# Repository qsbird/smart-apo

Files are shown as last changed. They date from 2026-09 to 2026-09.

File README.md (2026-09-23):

# Smart Apo · 智能阿波与智能水中

**想让浮漂自己记笔记，顺便查清是谁在拽鱼线。** 方案是水面阿波和钩侧水中件各记录一份数据，回收后对时分析。鱼还没参与测试，预算已经先替项目按了暂停键。

> [!NOTE]
> **项目状态：暂停。** 完整方案的预计试制成本超出当前预算。仓库保留研究过程与可审查的工程文件；暂停不等于技术验证通过。

> [!IMPORTANT]
> **制造状态：`NOT_FAB_RELEASED`。** Rev.A2 的 KiCad ERC 为 0 错误、0 警告，DRC 为 0 错误、0 未连接，仍有 **3 项连接区 courtyard 警告**。没有放行的生产 Gerber、钻孔和最终 BOM/CPL，也没有首件装配或水域实测。DRC 很能检查铜线，但不会替你拧紧 O 形圈。

## 先看钓组

鱼竿主线依次经过水面阿波、水中张力记录件、鱼钩和鱼饵，鱼游在饵旁的概念图

*概念示意，不按比例。鱼在饵旁边，没有被画成“已咬钩”的成功案例；线长、结节、配重和安全绳位置仍需实物确认。*

| 设备 | 设计中的任务 | 主要硬件 |
|---|---|---|
| **阿波** · 水面 | 记录加速度、角速度和水压，原始数据写入本地 Flash；预留 LED 提示接口 | STM32G031、LSM6DSO、LPS28DFW、W25Q256、LiPo 供电/充电及 LED 驱动 |
| **智能水中** · 靠近钩侧 | 通过受力梁与应变全桥记录钓线张力，供回收后离线标注；也记录运动和压力 | 共用 MCU、IMU、压力传感器和 Flash，另装 316L 弹性梁、应变片全桥与 NAU7802 |

“共板”是**同一 PCB 设计、两块独立设备、两套贴装清单**。它们计划各自记录，回收后导出；水里不靠实时无线链路传数据。上表描述的是设计功能，尚无装配样机证明这些功能在水里运行。

## 波浪很会演，鱼却不一定配合

浮漂动了，原因可能是浪、流、提竿动作，也可能是钩侧发生了机械事件。这个项目希望用水中张力作研究阶段的辅助标签，寻找阿波的 IMU 与压力信号里可重复的特征，而不是只赌一个瞬时阈值。

```mermaid
flowchart LR
    A["阿波原始记录<br/>运动 · 压力"] -->|回收导出| H["主机工具<br/>校验 · 对时 · 评价"]
    U["水中原始记录<br/>张力 · 运动 · 压力"] -->|回收导出| H
    H --> P["候选检测参数"]
    P --> V["下一独立航次再验证"]
```

这条链路是研究方案，不是已经跑通的产品流程。尤其要说清楚：**张力变化说明钩侧受了力，不自动证明有鱼咬钩。** 摄像、提竿或捕获结果仍需作为语义真值。[现场验证计划](validation/FIELD_TEST_PLAN_CN.md)记录了拟进行的台架、水槽和真实海况测试。

## 尺寸和材料：设计目标，不是合格证

| 项目 | Rev.A 目标或候选 |
|---|---|
| 阿波外形 | 最大直径 32 mm、高 49 mm |
| 共用 PCB | 12 × 35 × 1.0 mm，四层，计划沉金 |
| 首批设想 | 共板 10 片，阿波和水中各装 5 套；**尚未下生产订单** |
| 电池 | 带保护 401020 LiPo，候选 60–80 mAh；所购型号与允许充电电流未锁定 |
| 深度 | 目标工作 10 m、15 m 等效静水压力验证；未实测 |
| 水中张力 | 目标工作 0–2 kgf；另需独立样件验证 ≥5 kgf 生存 |
| 受力件 | 0.30 mm 316L 弹性梁；打印件不能代替它承受钓线拉力 |

<details>
<summary>看看 Rev.A1 的机械概念预览</summary>

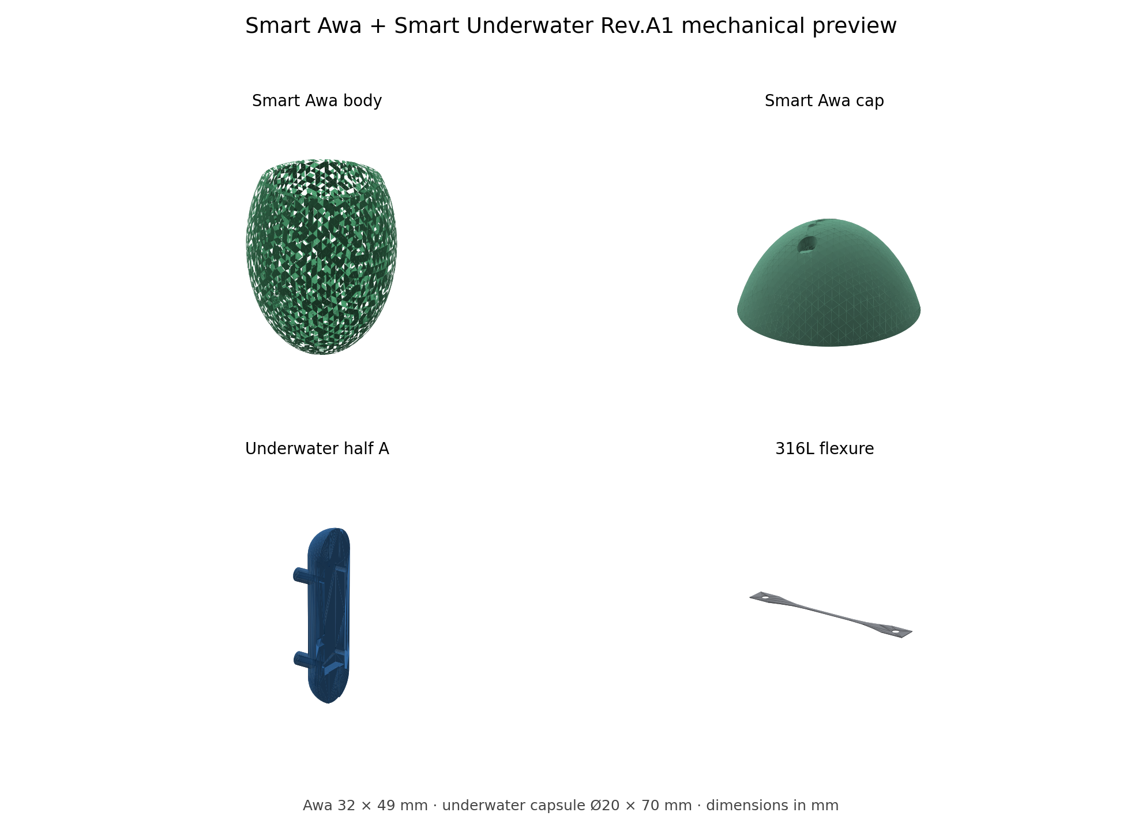
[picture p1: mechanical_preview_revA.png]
Rev.A1 阿波壳体、水中半壳与弹性梁的工程预览


这张图展示壳体与梁的工程几何。梁 STL 只供看形状，真实受力件须按 [316L 加工规范](mechanical/316L_FLEXURE_SPEC_CN.md)和 DXF 制作；图像也不表示 Rev.A2 的装配干涉或防水测试通过。

</details>

位号、数量与 DNP 差异请看 [Rev.A2 工作 BOM](hardware/revA2/BOM_revA2_WORKING.csv)和[装配变体表](hardware/revA2/ASSEMBLY_VARIANTS_revA2.csv)。采购后缀与来料尚未全部确认，工作 BOM 不能直接当最终贴片清单。

## 进度条不如证据可靠

| 领域 | 已留下什么 | 还差什么 |
|---|---|---|
| **电路与 PCB** | Rev.A2 原理图、项目符号/封装库、四层已布线候选板；KiCad 10.0.6 官方 ERC 0/0、DRC 0 错误/0 未连接 | J1/J2/J3 的 3 项连接区 courtyard、所购器件与板厂工艺、完整 3D 装配审查和制造文件复核 |
| **主机数据工具** | UART 解码、CSV 输入校验、事件评分、离线寻参和合成数据生成 | 新航次头缺专门的 C→UART→Python 端到端验证；合成数据不能替代真实航次 |
| **MCU 固件** | 采样、Flash 日志、总线与时基源码；宿主模型测试 | 没有最终可烧录 ELF、板上运行、实测功耗或真正 Stop/RTC 闭环 |
| **机械** | Rev.A1 参数模型、STL、316L 梁 DXF 与装配说明 | 缺匹配 Rev.A2 的完整壳体/器件模型、实物干涉和密封验证 |
| **现场研究** | 静载、水槽、压力和真实海况试验计划 | 尚无可用于证明性能或可靠性的样机与实测数据 |

三处警告只是最显眼的剩余提示；更大的缺口在采购、装配和实物。详细情况见 [Rev.A2 交付门槛](hardware/revA2/DELIVERY_GATES_CURRENT_CN.md)与[暂停检查点](PAUSE_CHECKPOINT_20260924_CN.md)。历史检查点中的数字属于当时版本，别把不同日期的报告拼成一块“全绿”的板。

> [!CAUTION]
> `hardware/revA2/smart_apo_common_revA2.kicad_pcb` 是设计候选版；`hardware/` 根目录里早期的 `*_NETS_PLACED.kicad_pcb` 只是布局参考。**仓库里没有可直接付款投产的制造包。**

## 如果你想复现数字检查

在仓库根目录运行。Python 测试使用宿主机 C 编译器验证模型和协议，不能替代板上测试。

```bash
python3 -m unittest discover -s firmware/host/tests -v
python3 -m unittest discover -s firmware/mcu/tests -v
python3 -m unittest discover -s tools/tests -v
python3 tools/validate_revA2.py
```

2026-09-24 公开提交前，三组测试分别有 **34、8、17 项通过**，结构检查也通过；最新 UART 航次头尚缺完整端到端用例。若有 KiCad 10，可用仅检查模式刷新 ERC/DRC 报告：

```bash
KICAD_CLI=/path/to/kicad-cli bash tools/export_fab_revA2.sh --check-only
```

`--check-only` 会更新工程中的检查报告，不生成制造文件。返回 0 只说明脚本规定的电气门禁通过，**不替三处警告、采购、3D 和实物验证签字**。无参数调用会进入制造导出流程，当前项目不应将其结果视作放行。

安装了 NumPy、SciPy 后，还可以用合成数据熟悉离线工具：

```bash
python3 firmware/host/generate_synthetic_dataset.py
python3 firmware/host/autotune.py \
  firmware/host/example_data/awa.csv \
  firmware/host/example_data/underwater.csv \
  -o /tmp/smart-apo-synthetic-result.json
```

这个例子主要验证管线能否处理规定格式，不负责替鱼提供表演。真实数据的字段、缺测规则、时钟回绕与梁标定要求见 [主机说明](firmware/host/README_CN.md)和[数据协议](firmware/DATA_AND_AUTOTUNE_PROTOCOL_CN.md)。

## 仓库地图

```text
hardware/revA2/       当前原理图、PCB、项目库、工作 BOM、正式检查结果
hardware/*revA1*      Rev.A1 历史文件；旧板不能投产
firmware/mcu/         STM32 固件、宿主模型与构建说明
firmware/host/        解码、输入校验、评分和离线寻参
mechanical/           Rev.A1 壳体/托架、316L 梁图纸与装配说明
tools/                生成器、结构检查、BOM 检查、制造导出门禁
validation/           现场试验方案与 Rev.A1 验证记录
CONTEXT_HANDOFF.md    历史决策与交接资料
```

公开仓库保存源码、工程文件和正式检查结果。本机逐轮候选板、回退快照、编译日志及不完整 3D 审查包没有推送到 GitHub；旧文档提及这些目录时，请以仓库实际文件为准。

## 如果哪天预算松口

先补齐 UART 航次头的端到端测试和最终固件链接；再确认电芯、CT05、LED、晶振、MLCC、Pogo 与板厂工艺，关闭连接区警告；随后核对 Rev.A2 壳体/压力口/电池的实物干涉。完成制造文件独立审阅后，才轮到首件、梁标定、压力、盐水和水域试验。[PCB 放行清单](hardware/revA2/PCB_RELEASE_CHECKLIST_revA2_CN.md)给出了更细的关口。

**当前结论仍是：项目因成本超预算而暂停，Rev.A2 未制造放行。** 鱼可以晚点上钩，工程结论不能抢跑。

## 复用与交流

欢迎通过 Issue 指出具体器件、KiCad 位置或可重复的测试问题。仓库中由项目作者原创的代码、设计文件、文档与插图按 [WTFPL Version 2](LICENSE) 发布（SPDX：`WTFPL`）。引用或改作自第三方的器件资料、库内容等仍受其原有权利约束；本仓库的许可证不能替第三方授权。许可证也不等于产品安全或制造放行证明。

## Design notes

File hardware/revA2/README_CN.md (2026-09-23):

> 最新同版本审查包：`validation/revA2_review_bundle/`已刷新当前原理图、正反面装配PDF及D1旋转后的不完整STEP，manifest.json绑定源/输出哈希。电气结果ERC0/0、DRC0错误/0未连/3项courtyard；采购/工艺/3D/最终链接/实机与尚未完成固件功能见 `hardware/revA2/DELIVERY_GATES_CURRENT_CN.md`。NOT_FAB_RELEASED。

> 最新原理图字段检查点（2026-09-23）：58个阻容显示字段拉开、J2扩大并同步7标签、8个符号库默认字段修正。官方ERC0/0、DRC0错误/0未连/3项courtyard，网表完全一致、PCB未改。见 `hardware/revA2/SCHEMATIC_FIELDS_CHECKPOINT_20260923_CN.md`，NOT_FAB_RELEASED。

> 最新IC图面检查点（2026-09-23）：U1至U7符号及75引脚间距扩大，69个标签/NC同步，长引脚名清晰分列；网表components/nets完全一致，PCB未改。官方ERC0/0、DRC0错误/0未连/3项courtyard。见 `hardware/revA2/SCHEMATIC_IC_CHECKPOINT_20260923_CN.md`；阻容/连接器图面仍待改善，NOT_FAB_RELEASED。

> 最新网络标签检查点（2026-09-23）：148个网络标签改为朝外对齐，锚点/网络语义不变，PCB未改。官方ERC0/0、DRC0错误/0未连/3项courtyard；IC内部引脚名及阻容字段仍待修整。见 `hardware/revA2/SCHEMATIC_LABEL_CHECKPOINT_20260923_CN.md`，NOT_FAB_RELEASED。

> 最新原理图检查点（2026-09-23）：A3纵向解决越页，Population仅隐藏显示；独立坐标/网表审查发现并清除6个连接引脚上的遗留NC叉号，保留3个有效标记。全部网络语义不变，官方ERC0/0、DRC0错误/0未连/3项courtyard，PCB未改；内部标签拥挤仍待修整。见 `hardware/revA2/SCHEMATIC_PAGE_CHECKPOINT_20260923_CN.md`，NOT_FAB_RELEASED。

> 最新D1极性修复（2026-09-23）：正式采用明确A/K符号及K1封装，1=K/LED_K、2=A/LED_A；封装/模型/端标转180°且原物理铜连接保持。官方ERC0/0、DRC0错误/0未连/3项courtyard，17项工具测试通过。设计内部冲突已关闭，所购器件/整页原理图/旧3D更新仍开放。见 `hardware/revA2/D1_POLARITY_FIX_20260923_CN.md`，NOT_FAB_RELEASED。

> 新确认的D1极性阻断（2026-09-23）：D1以PASSIVE2符号定义1=LED_A/2=LED_K，与派生KiCad LED封装1=K/2=A约定相反；ERC/DRC未捕获。必须先修正明确A/K符号、焊盘编号/网络及方向标识，不能仅等待采购资料。见 `hardware/revA2/D1_POLARITY_BLOCKER_20260923_CN.md`。PCB尚未修改，NOT_FAB_RELEASED。

> 最新BOM一致性检查（2026-09-23）：修正C7=100n、C11/C12实际0402和完整封装ID；43位号/变体数量检查通过，15项工具测试通过。U5目录编号冲突及准确MPN/有效容量仍开放，不是生产BOM放行。PCB未改，ERC0/0、DRC0错误/0未连/3警告。见 `hardware/revA2/BOM_CONSISTENCY_CHECKPOINT_20260923_CN.md`。

> 最新1脚标记检查点（2026-09-23）：U1/U5方向三角形仅平移并保持形状/指向，项目库同步；5→3警告，全部丝印DRC清零。官方ERC0/0、DRC0错误/0未连/0一致性问题，剩J1/J2/J3 missing_courtyard开放；NOT_FAB_RELEASED。见 `hardware/revA2/PIN1_SILK_CHECKPOINT_20260923_CN.md`。以下较大计数为历史。

> 最新连接区丝印检查点（2026-09-23）：J2/J3轮廓与库同步修复，9→5警告，无新增项。官方ERC0/0、DRC0错误/0未连/0一致性问题，NOT_FAB_RELEASED。见 `hardware/revA2/CONNECTOR_SILK_CHECKPOINT_20260923_CN.md`。剩2项方向标记压铜和3项courtyard，以下较大计数为历史。

> 最新上部位号检查点（2026-09-23）：U1/U7位号回到各自本体，六个拥挤丝印位号不印刷并保留原位Fab装配标识；36→9警告，无新增项。官方ERC0/0、DRC0错误/0未连/0一致性问题，NOT_FAB_RELEASED。见 `hardware/revA2/UPPER_LABEL_CHECKPOINT_20260923_CN.md`。以下较大警告数为历史。

> 最新被动元件位号检查点（2026-09-23）：R8/C5/C3/C8/R10可见位号调整，50→36警告，无新增项。官方ERC0/0、DRC0错误/0未连/0一致性问题，NOT_FAB_RELEASED。见 `hardware/revA2/PASSIVE_LABEL_CHECKPOINT_20260923_CN.md`。以下较大警告数为历史。

> 最新装配位号检查点（2026-09-23）：补齐6个项目封装Fab标识，43个封装各有一个原位Fab位号并导出正反面审查PDF；仅新增非制造层文字。官方ERC0/0、DRC0错误/0未连/50警告，项目库一致，NOT_FAB_RELEASED。见 `hardware/revA2/ASSEMBLY_LABEL_CHECKPOINT_20260923_CN.md`。完整装配/极性/工艺验证仍开放。

> 最新MCU标识处置（2026-09-23）：五个拥挤丝印位号不印刷，保留原位F.Fab并输出核对装配图，R4移到邻近空白区；70→50警告，无新增项。官方ERC0/0、DRC0错误/0未连/0一致性问题，NOT_FAB_RELEASED。见 `hardware/revA2/MCU_LABEL_CHECKPOINT_20260923_CN.md`。完整装配图仍为交付门槛，下方较大警告数为历史。

> 最新充电区丝印检查点（2026-09-23）：U6/R3/C11位号调整，75→70警告，无新增项。官方ERC0/0、DRC0错误/0未连/0一致性问题，NOT_FAB_RELEASED。见 `hardware/revA2/CHARGER_LABEL_CHECKPOINT_20260923_CN.md`。下方较大警告数为历史。

> 最新J1丝印检查点（2026-09-23）：J1丝印与项目库同步，79→75警告，板边丝印类别清零，无新增项。官方ERC0/0、DRC0错误/0未连/0一致性问题，NOT_FAB_RELEASED。见 `hardware/revA2/J1_SILK_CHECKPOINT_20260923_CN.md`。以下较大警告数为历史。

> 最新D1丝印检查点（2026-09-23）：D1位号及两段板边轮廓调整，项目专用封装同步原理图，82→79警告，无新增项。官方ERC0/0、DRC0错误/0未连/0一致性问题；NOT_FAB_RELEASED。见 `hardware/revA2/BOTTOM_SILK_CHECKPOINT_20260923_CN.md`。D1所购器件极性仍须核验，下方较大警告数为历史。

> 最新字高检查点（2026-09-23）：U2/SW1/J2位号字高修复，89→82警告，text_height类别清零，无新增项。官方ERC0/0、DRC0错误/0未连/0一致性问题，NOT_FAB_RELEASED。见 `hardware/revA2/TEXT_HEIGHT_CHECKPOINT_20260923_CN.md`。下方较大警告数为历史。

> 最新板边位号检查点（2026-09-23）：U4/C6/C16/R6仅Reference字段调整，95→89警告，无新增项；官方ERC0/0、DRC0错误/0未连/0一致性问题，NOT_FAB_RELEASED。见 `hardware/revA2/EDGE_LABEL_CHECKPOINT_20260923_CN.md`。下方警告数为历史。

> 最新U3/C13检查点（2026-09-23）：C13可见位号修复消除10项警告；U3及配套库按最大本体重建禁布，最小理想via余量.10mm/顶部.125mm。官方ERC0/0、DRC普通错误0/未连接0/95警告、一致性0，无忽略/排除，NOT_FAB_RELEASED。见 `hardware/revA2/U3_MARGIN_AND_C13_CHECKPOINT_20260923_CN.md`。以下较小余量和警告数均为历史。

> 最新整板电气闭合（2026-09-23）：MOSI最终候选已独立复检并采用。官方ERC0/0、DRC普通错误0/未连接0/105警告、一致性0，无忽略/排除；NOT_FAB_RELEASED。仅检查模式exit0且fab_export不存在。见 `hardware/revA2/MOSI_CONNECTED_CHECKPOINT_20260923_CN.md`。还须警告、制造公差/采购资料、当前3D及固件/实物门槛；下方未连接数字均为历史。

> 最新位号检查点（2026-09-23）：仅修正U3/J3可见丝印Reference字段，铜/器件位置/规则未变；官方ERC0/0、普通DRC错误0/1MOSI未连接/107警告、一致性0，无忽略/排除，NOT_FAB_RELEASED。见 `hardware/revA2/REFERENCE_TEXT_CHECKPOINT_20260923_CN.md`。MOSI候选仍独立迭代。

> 验证命令更新：日常官方检查使用 `bash tools/export_fab_revA2.sh --check-only`。即使电气计数清零，也不会创建或修改制造文件；不带参数才会在电气门禁通过后进入导出。警告、制造与机械门槛仍需逐项审核。见 CHECK_ONLY_CHECKPOINT_20260923_CN.md。

> 最新IMU完整连接（2026-09-23）：经两组几何合并与独立复核已采用；官方ERC0/0、普通DRC错误0/仅MOSI 1未连接/110警告、一致性0，无忽略/排除，NOT_FAB_RELEASED。最大U2本体理想via余量.10mm；局部供电参考缺口有明确处置、严格标记仍false。见 `hardware/revA2/IMU_CONNECTED_CHECKPOINT_20260923_CN.md`。以下候选未采用/计数为历史。

> 最新DRC可见性检查点（2026-09-23）：五类原忽略检查已启用，无ignored_checks/单项排除；修正一处地线端点，并将工程状态长说明保留到Dwgs.User。官方ERC0/0、普通DRC错误0/2未连接/111警告、一致性0，NOT_FAB_RELEASED。3个连接区courtyard缺失现在明确可见，仍开放。见 `hardware/revA2/DRC_VISIBILITY_CHECKPOINT_20260923_CN.md`。以下为历史。

> 最新LED制造修复（2026-09-23）：LED阴极孔已移出焊盘，审查中元件焊接焊盘内中心为0，剩2处Pogo接触孔待资料；官方ERC0/0、DRC普通错误0/2未连接/122警告、一致性0，NOT_FAB_RELEASED。见 `hardware/revA2/LED_VIA_MANUFACTURING_CHECKPOINT_20260923_CN.md`。以下计数为历史。

> 最新SCL制造修复（2026-09-23）：ADC与MCU两端SCL孔已移出焊盘，焊盘内中心5→3（剩D1.2及J2.7/J2.5）。官方ERC0/0、DRC普通错误0/2未连接/122警告、一致性0；NOT_FAB_RELEASED。IMU候选失败未采用。见 `hardware/revA2/SCL_VIA_MANUFACTURING_CHECKPOINT_20260923_CN.md`。以下数字为历史。

> 最新R5制造修复（2026-09-23）：原审批路径已恢复可用，R5焊盘内孔修复stage3已采用；焊盘内中心6→5。主板官方ERC0/0、DRC普通错误0/2未连接/122警告、一致性0，NOT_FAB_RELEASED。见 `hardware/revA2/R5_MANUFACTURING_CHECKPOINT_20260923_CN.md`。下方审批失败和未采用记录为历史。

> 当前制造审查补充（2026-09-23）：正式板未变，仍2未连接/122警告、NOT_FAB_RELEASED。新增全板via/焊盘审查发现4处元件焊盘内孔与2处Pogo接触孔。R5候选尚未采用，最后修改/复检因自动审批额度不足未执行；MOSI试验拒绝。见 `hardware/revA2/VIA_PAD_CHECKPOINT_20260923_CN.md`。

> 当前ADC SDA检查点（2026-09-23）：I²C两条总线已全部接通；官方ERC0/0、DRC普通错误0/未连接2/警告122、一致性0；NOT_FAB_RELEASED。见 `hardware/revA2/ADC_SDA_CHECKPOINT_20260923_CN.md`。剩IMU_INT/MOSI；官方STEP为不完整模型审查件，未通过3D干涉。以下为历史。

> 当前I²C主干检查点（2026-09-23）：SCL全部接通，上部SDA接入MCU；官方ERC0/0、DRC普通错误0/未连接3/警告122、一致性0；NOT_FAB_RELEASED。见 `hardware/revA2/I2C_JOIN_CHECKPOINT_20260923_CN.md`。余下ADC SDA/IMU_INT/MOSI；局部反焊盘及装配余量仍有明确审查边界。以下为历史。

> 当前ADC SCL检查点（2026-09-23）：MCU/上拉至ADC的SCL已连通，相关REED支路完整。官方ERC0/0、DRC普通错误0/未连接5/警告120、一致性0；NOT_FAB_RELEASED。见 `hardware/revA2/ADC_SCL_CHECKPOINT_20260923_CN.md`。显式填铜增量参考及独立连通审查通过，非EM/实物通过；以下数字为历史。

> 当前上部I²C检查点（2026-09-23）：U2/U3 SDA/SCL已连接，C2同面供电路径缩短。官方ERC0/0、DRC普通错误0/未连接6/警告120、一致性0；NOT_FAB_RELEASED。见 `hardware/revA2/UPPER_I2C_CHECKPOINT_20260923_CN.md`。7个供电过孔边缘参考点单独处置，非EM通过；以下计数为历史。

> 当前 U3 检查点（2026-09-23）：找回哈希匹配的原厂Gerber，按实际中央接地和外围逃线路径建立窄通道，电源/地缺口关闭。官方ERC0/0、DRC普通错误0/未连接8/警告119、一致性0；NOT_FAB_RELEASED。见 `hardware/revA2/U3_ESCAPE_CHECKPOINT_20260923_CN.md`。以下数字为历史。

> 当前 MISO 检查点（2026-09-23）：SCK与MISO已分组采用，官方ERC0/0、DRC普通错误0/未连接12/警告119、一致性0；NOT_FAB_RELEASED。见 `hardware/revA2/MISO_CHECKPOINT_20260923_CN.md`。In1新填铜几何通过，换层回流/SI仍开放；以下旧计数为历史。

> 当前 SCK 检查点（2026-09-23）：已采用独立验证的 B/In2/F 布线，In1 保持地。官方 ERC0/0、DRC 普通错误0/未连接13/警告120、一致性0；NOT_FAB_RELEASED。详见 `hardware/revA2/SCK_CHECKPOINT_20260923_CN.md`。以下旧检查点数字均为历史。

> 最新Flash封装检查点（2026-09-23）：误用Microchip焊盘已按Winbond原著land/paste替换，编号网络保持，错误3D移除。官方ERC0/0、DRC普通错误0/未连接14/警告119；NOT_FAB_RELEASED。见 `hardware/revA2/FLASH_LAND_CHECKPOINT_20260923_CN.md`；局部供电过孔参考缺口有独立处置，不等于EM验证。

> 最新Flash检查点（2026-09-23）：固定32轮BUSY误超时已改为5ms实时时限，host23/23、MCU8/8、20 ARM对象通过。KiCad仅检查独立副本，未采用新布线；仍14未连接/119警告，NOT_FAB_RELEASED。见 `hardware/revA2/FLASH_TIMEOUT_CHECKPOINT_20260923_CN.md`。

> 最新软件等待/LED检查点（2026-09-23）：恢复时基误失效及UART锁存重试已修复，LED寄存器驱动通过模型；MCU8/8、host23/23、20 ARM对象。真实Stop/RTC、最终ELF/实物仍未完成；PCB未改，NOT_FAB_RELEASED。见 `hardware/revA2/IDLE_LED_CHECKPOINT_20260923_CN.md`。

> 最新启动检查点（2026-09-23）：ADC100ms非阻塞保护与LSE有界启动已模型验证，MCU8/8、host23/23、20 ARM对象通过；无最终ELF/板上验证。PCB未改，仍14未连接/119警告。见 `hardware/revA2/STARTUP_TIMING_CHECKPOINT_20260923_CN.md`，软件SLEEP恢复缺陷待修复。

> 最新分压/GPIO检查点（2026-09-23）：R4/R5已改180k/60.4k，阻抗数值超限修正但精度/功耗未实测。ERC0/0；DRC普通错误0、未连接14、警告119；NOT_FAB_RELEASED。见 `hardware/revA2/DIVIDER_GPIO_CHECKPOINT_20260923_CN.md`。旧记录为历史。

> 验证更正（2026-09-23）：旧参考地脚本可能读缓存；MISO PCB组已撤回，SCK候选拒绝。当前官方ERC0/0、DRC普通错误0/未连接14/警告119，NOT_FAB_RELEASED。以 `hardware/revA2/REFERENCE_AUDIT_CORRECTION_20260923_CN.md` 为准，后续必须用显式填铜审查器。

> 最新MISO/I²C检查点（2026-09-23）：ERC0/0，DRC普通错误0、未连接13、警告115；NOT_FAB_RELEASED。详见 `hardware/revA2/SPI_I2C_CHECKPOINT_20260923_CN.md`。In1局部信号的最终回流审查仍开放；旧计数为历史记录。

> 最新逃线/ADC检查点（2026-09-23）：ERC 0/0，DRC普通错误0、未连接14、警告119；NOT_FAB_RELEASED。ADC分压源阻抗另有设计阻塞。详见 `hardware/revA2/FANOUT_ADC_CHECKPOINT_20260923_CN.md`；旧计数为历史记录。

> 最新复位/UART检查点（2026-09-23）：ERC 0/0，DRC普通错误0、未连接15、警告119；NOT_FAB_RELEASED。详见 `hardware/revA2/RESET_UART_CHECKPOINT_20260923_CN.md`。下文旧计数为历史记录。

> 最新电源/SPI 检查点（2026-09-23）：官方 ERC 0/0，DRC 普通错误 0、未连接 18、警告 119；仍 NOT_FAB_RELEASED。详见 `hardware/revA2/POWER_CHECKPOINT_20260923_CN.md`（下文旧计数为历史记录）。

# 智能阿波共板 Rev.A2 工作区

> **活动目标最新桥路检查点**：ERC **0/0**；普通DRC错误 **0**，仍有 **22未连接、119警告**，一致性0，**NOT_FAB_RELEASED**。主差分输入已成对、同面、零过孔；J3物理顺序已旋转。TIM2寄存器后端模型测试通过，23项host＋2项MCU测试通过，最终ELF/板上未完成。详见 [桥路与时基检查点](ANALOG_CHECKPOINT_20260923_CN.md)。下方旧数字为历史。

此目录是从 Rev.A1 独立建立的生产候选工作区。任何 Rev.A2 生成或审查操作都不得写入上级目录中的 `*revA1*` 文件。

## 当前状态

- Rev.A1 基线 SHA-256 已记录在 `revA1_baseline_sha256.json`。
- `smart_apo_revA2.kicad_sym` 使用逐脚电气类型，不再把核心 IC 的所有引脚定义为 Passive。
- `smart_apo_common_revA2.kicad_sch` 是独立原理图；当前先完成符号电气类型修复，电路改动需在官方 ERC 与逐脚审查后进行。
- `SmartApoRevA2.pretty` 是项目级封装库目录。
- `BOM_revA2_WORKING.csv` 与 `ASSEMBLY_VARIANTS_revA2.csv` 保留双装配版本；前者仍是工作 BOM，不是最终下单 BOM。
- `CPL_revA1_REFERENCE_ONLY.csv` 只用于查看旧布局，严禁作为 Rev.A2 贴片坐标文件。
- 上级 `hardware/smart_apo_common_revA2_NETS_PLACED.kicad_pcb` 只是参考板；本目录 `smart_apo_common_revA2.kicad_pcb` 才是从网表重建的四层候选板。
- 已使用 KiCad 10.0.6 官方 ERC：0 错误、0 警告（SW1 改紧凑封装后重跑仍通过）。
- 已使用 KiCad 10.0.6 官方 DRC：**未通过**（2026-09-09 长程 CP05：104 错误、74 未连接）。过孔 0.60/0.30 已消除钻孔过小和孔环不足。完整布线仍未关闭。
- LSM6DSO 已使用项目封装 `SmartApoRevA2:LGA-14_2.5x3mm_P0.5mm_LSM6DSO`（2.5×3.0 mm，DS Figure 25）。无评估板 Gerber 交叉验证前，封装复核不能整项关闭。
- MCU 固件骨架在 `firmware/mcu/`；无 CubeMX / `arm-none-eabi-gcc`，不能当已验证固件。
- 生产导出脚本：`tools/export_fab_revA2.sh`（DRC 非零即拒绝）。长程检查点：`LONG_RUN_CHECKPOINTS_CN.md`。
- LPS28DFW footprint 已按 ST 官方 STEVAL-MKI225A 铜层/阻焊/钢网 Gerber 重建。
- STM32G031F8P6 已按 DS12992 Rev 4 的真实 TSSOP20 物理脚顺序重建。
- W25Q256 `/CS` 已增加 R12 10 kΩ 上电上拉；`/WP`、`/HOLD` 接 3V3。
- KiCad 官方网表已导出：43 个器件、33 个已连接网络、9 个明确未连接引脚。
- 电池焊盘、7 针 Pogo、6 线桥和紧凑磁簧已在项目级 `.pretty`。

## 放行原则

只有在从原理图更新 PCB、完成布线、官方 DRC 为零错误、独立查看 Gerber/钻孔并重新导出 BOM/CPL 后，才可把状态改为 `FAB_RELEASED`。

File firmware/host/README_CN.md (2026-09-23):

> 最新CSV入口校验：直接调参输入拒绝非有限值、重复/倒序时间戳及缺失/重复列；34项host回归通过，旧/新真实加载函数对照通过。完整SciPy管线仍未运行。见VERIFICATION_CSV_INPUT_CN.md。

> 最新评分修复：事件评价改为一对一重叠匹配，防止长报警/重复报警获得虚高F1；28项host回归通过，4096组序列对照及实际搜索函数合成集成通过。完整SciPy管线未运行；example_result.json为旧评分历史，不可当新版质量证据。见VERIFICATION_EVENT_METRICS_CN.md。

# 离线闭环调参工具

输入是阿波与智能水中的两个 CSV。下水前和回收后分别做三次同步敲击，脚本用六个冲击拟合时间偏移与晶振漂移；水中张力生成教师标签，阿波 IMU/压力生成学生特征，并按连续时间切为 60%/20%/20% 三段。

```bash
python generate_synthetic_dataset.py
python autotune.py example_data/awa.csv example_data/underwater.csv -o example_result.json
```

输出参数只作为候选版本。必须在下一次、完全未参与寻参的独立航次通过门限后，才允许写入设备；本工具有意不实现自动刷机，避免同一数据集上的过拟合参数被直接投入使用。

CSV 必填列：`timestamp_us, ax, ay, az, gx, gy, gz, pressure`；水中端另加 `tension_gf`。时间戳必须单调递增，单位为微秒。

回收后若从设备 UART 拉原始帧（`A5 5A` 同步），用：

```bash
python dump_decode.py capture.bin -o voyage_raw.csv
python dump_decode.py capture.bin --autotune awa -o awa.csv
python dump_decode.py capture.bin --autotune uw --tension-lsb-per-gf "$CAL_COUNTS_PER_GF" --tension-zero-counts "$CAL_ZERO_COUNTS" -o underwater.csv
```

`--autotune` 输出 `autotune.py` 所需列，但会先执行下述安全检查。加速度/角速度用 `sensors.h` 候选量程（±4 g、±500 dps）及 ST 官方敏感度 0.122 mg/LSB、17.50 mdps/LSB。压力按 DS13317：阿波 4096 LSB/hPa（Mode 1），水中 2048 LSB/hPa（Mode 2，15 m 不能用 1260 hPa 档）。raw 导出一直保留张力原始计数；UW 调参导出必须填写实际梁标定得到的 CAL_COUNTS_PER_GF 和 CAL_ZERO_COUNTS，不提供默认 gf。帧格式见 `firmware/mcu/include/uart_dump.h`。这不是自动刷机。

宿主机协议/固件模拟接口回归（无 numpy/scipy 依赖，在仓库根目录运行）：

```bash
python3 -m unittest discover -s firmware/host/tests -v
```

2026-09-23：增加显式时间展开验证，见 `firmware/host/VERIFICATION_TIME_UNWRAP_CN.md`；ARM/板上验证未完成。MCU 已实现全航次 Flash/RAM 尾转储的模拟验证，host 去除连续完全相同的重试帧；raw 原样保留计数及 flags；`--autotune` 已拒绝含缺测通道的日志，不会把未采样零值送入调参。显式重采样仍未实现。前序证据与阻塞见 `firmware/mcu/VERIFICATION_20260923_CN.md`。

## 调参导出安全门槛

- AWA 每条样本必须同时置位 IMU_OK(bit 1) 和 PRESS_OK(bit 2)，且不能携带 STRAIN_OK(bit 3)；UW 每条必须三个有效位齐全。没有有效位的数值（即使为 0）只能作为 raw 诊断数据，不能解释为物理零值。
- 任一条缺测即拒绝整次调参导出，退出 2，不创建/覆盖目标 CSV；不擅自删行、补零、插值或前值填充。当前异步 MCU 日志通常会被此门槛拒绝，直到明确实现重采样流程。
- 检查样本内部 CRC，时间戳必须严格递增，sequence 必须按模 65536 连续（允许 65535→0）；外层 CRC 丢弃中间坏帧后产生的序号缺口也拒绝调参；回绕/复位需显式重建，不能直接调参。UART 外层 CRC 仍负责帧筛选，完全相同的连续重试帧去重。
- UW 张力采用 `(raw - zero_counts) / counts_per_gf`；斜率须有限且非零（可为负以表达桥方向），零点必须显式提供且有限。ADC 内部 offset 校准不等于梁的 gf 标定。
- UART v1 尚未传送航次头。`--autotune awa|uw` 是操作者声明的装配变体，不能自动证明压力量程正确；AWA/UW 压力比例分别是 4096/2048 LSB/hPa。
- raw 导出不改变原样本，包括诊断用无效值与 flags。它使用 `*_raw` 列名，不能直接当作 autotune 输入。

## 长航次 uint32 微秒时间展开（显式选择）

默认仍拒绝时间戳回绕。uint32 微秒计数约 71.6 分钟回绕一次；只有操作者能从采集记录确认以下条件时，才可展开：单次不中断启动、没有重启/时钟复位、相邻记录实际间隔始终不超过已知上限，且该上限严格小于半周期（2147483648 us，约 35.8 分钟）。例如已确认最大相邻间隔不超过 10000 us：

```bash
python3 firmware/host/dump_decode.py capture.bin --autotune awa --unwrap-timestamps --max-sample-gap-us 10000 -o awa.csv
```

两个参数必须一起用于 `--autotune`，上限必须为 1..2147483647 的整数。此选项是对采集条件的显式声明，软件不能替操作者证明。每步按模 2^32 计算增量，重复、明显后退、增量超上限、半周期及以上歧义全部拒绝；输出从第一条原始计数开始累加为展开时间，不推断第一条之前的回绕次数。原始记录和内部 CRC 不改写，seq 模 65536 连续、CRC、变体及缺测门槛全部保留；验证失败不覆盖输出。

UART v1 缺少启动/航次标识和宽时间戳，任意长停顿（特别是整周期停顿）、恰好伪装成小正增量的复位，以及恰丢失 65536 的整数倍记录，无法仅凭这两个有限位宽计数可靠识别。来源不明确的日志应保留 raw，不应使用展开参数强行放行。连续完全相同的 UART 重试帧仍按既有规则去重；这不证明采集未重启。时间展开不是异步传感器重采样，当前存在缺测标志的 MCU 日志仍拒绝调参导出。

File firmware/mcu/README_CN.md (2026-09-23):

> 最新日志读取修复：CRC失败时不再覆盖调用者的有效样本，空指针不推进游标的既有防护纳入回归。host契约23项通过（日志用双变体），20个ARM对象编译验证通过；函数静态栈帧40→72字节，仍无最终ELF/上板。见VERIFICATION_LOG_READ_SAFETY_CN.md。

> 最新最终链接实测（2026-09-23）：AWA/UW两次`make all`均因现有Clang找不到lld而exit2，20个新目标文件确认为ARM ELF32 REL；没有最终ELF、未上板。缺ARM链接器及builtins库，未安装新依赖。详见 hardware/revA2/CURRENT_DELIVERY_AUDIT_20260923_CN.md及validation/revA2_current_delivery_audit/。

> 最新资源证据（2026-09-23）：两个版本20个真实ARM对象带-fstack-usage编译通过；静态RAM节714/705字节，已知调用链栈帧小计616字节。未知运行库/异常栈未覆盖，最终ELF和完整栈安全仍未通过。见VERIFICATION_STACK_RESOURCES_CN.md。

# STM32G031 Rev.A2 固件开发状态

截至2026-09-23：主代理实际重跑MCU模型/runtime **8/8**、host回归 **23/23**，AWA/UW两变体共 **20个Cortex-M0+ ELF32目标文件**编译及标头检查通过。**最终ELF未链接、未烧录、没有板上运行或发行包**；缺链接器与ARM compiler runtime，新增工具链安装授权待答复。未安装CubeMX，没有声称CubeMX生成或验证过完整工程。

## 实现层级

| 功能 | 当前证据 | 尚未完成 |
|---|---|---|
| TIM2微秒时基 | 真实寄存器+状态模型 | HSI精度、实物计时、跨Stop补偿 |
| LSE启动 | 真实寄存器、有界2s策略超时+模型 | 准确晶体/drive/负载匹配、板上起振、连续监控 |
| SPI1 / UART TX / I²C1 | 真实寄存器+故障模型 | 真实器件、波形、吞吐与边界工况 |
| GPIO / 磁簧 | IDR实读、释放边沿锁存、1.5s模型 | 电平/抖动、NVIC/ISR、Stop唤醒 |
| ADC电池 | 原始码后端、分压换算、100ms启动保护 | 参考电压、实际RC/漏电/精度、运行中电压阶跃 |
| 传感器/Flash/转储 | 模型与协议回归 | 实际寄存器应答、NOR写入/掉电、整航次 |
| LED | PB0写入/读回、闪光/取消/故障模型 | 实际波形/亮度、轮询节拍、咬钩检测 |
| SLEEP/Stop | 软件等待保持时基、恢复及故障转储模型 | 真正硬件Stop、RTC补偿与功耗验证 |

每项证据与局限见 `VERIFICATION_TIM2_CN.md`、`VERIFICATION_LSE_CN.md`、`VERIFICATION_SPI_CN.md`、`VERIFICATION_UART_CN.md`、`VERIFICATION_I2C_CN.md`、`VERIFICATION_GPIO_CN.md`、`VERIFICATION_ADC_CN.md`。早期报告的“骨架”和测试数量是历史状态。

## 启动、变体和引脚

`app_boot`依次开启SYSCFG、设置PA11_RMP/PA12_RMP、启动TIM2并尝试LSE，然后初始化GPIO、SPI/I²C、磁簧轮询边沿、UART及日志/传感器。PA13/14保留SWD。LSE仅提供启动ready快照；无论LSE成功与否，当前时间戳仍由HSI16/TIM2提供。`SAMPLE_FLAG_LSE_FAIL`不是时间戳校准状态。

同一PCB的AWA变体为LSM6DSO+LPS28DFW+Flash+LED；UW另贴NAU7802与桥路，用`SMART_APO_VARIANT_AWA/UW`选择。物理引脚表见仓库 `hardware/revA2/STM32G031_TSSOP20_PIN_REVIEW_CN.md`，数据协议见 `firmware/DATA_AND_AUTOTUNE_PROTOCOL_CN.md`。

R4/R5现为180kΩ/60.4kΩ、1%，名义毫伏换算 `adc*132220/41223`。启动前100ms拒绝ADC读取且不改输出；C14的100nF X7R、容差≤20%及温度/时钟裕量是设计条件，未由实物证明。详见硬件 `DIVIDER_GPIO_CHECKPOINT_20260923_CN.md` 与启动检查点。

## 状态、存储和接口

软件路径为BOOT→RECORD→DUMP→SLEEP，失败进入ERROR；发现已有APO2日志则只读DUMP。**SLEEP目前不是硬件Stop**，不能宣称低功耗或磁簧中断唤醒已运行。`board_buses_reinit_after_stop`故意使失去补偿的TIM2时基失效；软件SLEEP现不再调用它；等待和转储期间持续服务真实时基，恢复保持同一epoch。时钟失效则仅允许只读转储，不恢复写日志。

RECORD按整数相位调度104/208/320Hz等名义速率；迟到只读当前值，不伪造历史样本。IMU连读14字节、压力5字节，失败不置有效位。同步敲击检测尚未实现；PA0即时电平轮询不能保证捕获短脉冲。

磁簧为PA9低有效。1.5s持续闭合资格使用TIM2及EXTI9上升沿pending清除释放历史，IMR/EMR屏蔽，没有NVIC/ISR。GPIO或时基错误清除资格。

SPI为Mode0、约1MHz、8位访问和软件CS；I²C使用保守标准模式时序计算、7bit地址、重复起始读和有界故障处理，干净NACK不屏蔽其他设备，硬故障需要显式恢复。具体时序假设和测试不等于板上合格。

Flash写前检查整页空白/WEL，写后读回；已有日志只读回收，未知/损坏头拒写，不自动擦除历史。BUSY已改为TIM2实时时限5ms，并有连续4096次停滞终止；首次ready允许无TIM2只读恢复，真正PP前必须验证时基进展。原厂页写最大3ms的依据及边界测试见 `VERIFICATION_FLASH_TIME_CN.md`。读失败/半帧不当有效数据。UART格式仍 `A5 5A | version=1 | len | sample | crc16`；TX等待TXE和末尾TC，失败后APP显式重新初始化TX后端并在下一步重试原记录，但没有主机ACK，不能证明主机持久化。

`app_error_flags()`提供日志/转储粘滞错误；失败保留样本/记录。主机解码为 `firmware/host/dump_decode.py`，默认拒绝时戳回绕，显式展开需满足记录间隔约束。TIM2的模2^32单调契约要求调用间隔不超过INT32_MAX微秒；Stop、停转或配置异常失败闭合。

## 实际验证

在仓库根目录：

```sh
python3 -m unittest discover -s firmware/mcu/tests -v
python3 -m unittest discover -s firmware/host/tests -v
make -C firmware/mcu objects-both CC=/opt/homebrew/opt/llvm/bin/clang BUILD=validation/flash_time_checkpoint/arm
python3 tools/check_divider_revA2.py
```

当前集成日志及20个对象哈希在 `validation/revA2_interactive/`；软件等待/转储/LED的新回归与局限见 `VERIFICATION_IDLE_LED_CN.md`；各后端还有独立状态模型/静态分析证据。不得直接运行宿主编译的生产main：默认MMIO地址属于MCU；宿主测试必须使用明确隔离的hooks。

下一步：完成真实Stop/RTC时间设计、咬钩检测与最终链接/栈预算，再以样机验证传感器、NOR/转储、ADC、时钟、功耗和故障恢复。PCB仍NOT_FAB_RELEASED。

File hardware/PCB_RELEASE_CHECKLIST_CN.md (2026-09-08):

# PCB 投板放行清单

当前文件包含网络、真实焊盘、器件布局和内层平面定义，但尚未布线。Gerber 放行门槛如下，全部签字后才可建立 `FAB_RELEASED` 版本。

## 原理图

- [ ] 从 ST、Nuvoton、Winbond、Microchip、TI 的当前原厂数据手册逐脚复核。
- [ ] STM32G031F8P6 的 TSSOP20 复用脚与固件外设映射经过 CubeMX 验证。
- [ ] LSM6DSO 在 I²C 模式下 CS 拉高；SDO/SA0 地址脚固定，不悬空。
- [ ] LPS28DFW 的焊盘严格按 ST TN0018 复核；金属帽接地、O 形圈受力和顶层禁布区按原厂建议完成。
- [ ] NAU7802 的 AVDD=3.0 V、DVDD=3.3 V、六线桥 REF、输入共模与 320 SPS 配置复核。
- [ ] W25Q256 的 `/WP`、`/HOLD` 上拉与上电时序复核。
- [ ] 充电电流按实际电芯允许值设置；20 kΩ 仅代表约 50 mA 的候选值。
- [ ] 使用带保护电芯，或补充独立过充、过放、短路保护。

## 布局布线

- [ ] 四层建议：F.Cu 信号/器件，In1 整面 GND，In2 3V3/VBAT，B.Cu 低速信号。
- [ ] IMU 距板边、螺钉、弹性梁和磁性件足够远；器件坐标轴已在丝印标出。
- [ ] 压力传感器开孔上方无遮挡，所有铜/阻焊/外壳压紧区域满足数据手册。
- [ ] NAU7802 与桥路接口形成独立安静区，差分输入等长、短、成对，远离 LED 和充电回路。
- [ ] 每个电源脚就近去耦；Flash 和 MCU SPI 回路短且有连续参考地。
- [ ] 湿式触点设置隔离/串阻，盐水中不得带电暴露。
- [ ] 完成 4 层板厂能力规则 DRC，无未布网络，无未连接地岛。
- [ ] 板文件中当前 `segments/tracks=0` 的阻断状态已解除，全部飞线清零。

## 制造与首件

- [ ] 板厚 1.0 mm、ENIG、4 层叠层与 12 × 35 mm 外形得到板厂确认。
- [ ] 实际 SMT 厂料号锁定；BOM 中所有替代料逐项审批。
- [ ] Gerber/钻孔在独立查看器中复核，CPL 原点和旋转方向用装配图确认。
- [ ] 先做裸板短路检查，再限流 10 mA 上电。
- [ ] 分别验证 3V3、I²C 三传感器、Flash、充电、SWD、LED、应变桥。

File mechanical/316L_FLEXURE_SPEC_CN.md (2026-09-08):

# 316L 弹性梁加工与标定规范（Rev.A）

## 加工定义

- 材料：316L 不锈钢薄板，固溶态；厚度 0.30 ± 0.015 mm。
- 轮廓：`316L_flexure_0p30mm_revA.dxf`，单位 mm。
- 总长 78 mm，端部宽 8 mm，安装孔 Ø3.2 mm，孔距 67 mm。
- 中央敏感段宽 1.50 mm、有效长度 22 mm。
- 工艺：优先精密激光切割后电解抛光；也可慢走丝。去除毛刺但不得磨窄敏感段。
- 平面度：≤0.15 mm；孔边与过渡圆角不得有可见裂纹。

## 应变片

- 四片 350 Ω、适用于不锈钢的箔式应变片，组成温度补偿全桥。
- 两片沿载荷方向、两片横向或布置在等应变位置；贴片方向误差建议 <0.5°。
- 胶层越薄越均匀越好。固化后先做绝缘电阻，再涂柔性防水保护。

## 工程限制

这是一根用于获取真实数据和确定最终量程的 Rev.A 梁，不是已认证的安全件。解析估算只用于下单前筛选：中央截面积约 0.45 mm²，1 kgf 名义轴向应力约 21.8 MPa、应变约 113 µε。孔边、过渡区、切割热影响和贴片胶层会改变实际输出，必须用砝码标定。

建议依次执行 0、50、100、200、500、1000、1500、2000 g 五次加载/卸载循环，记录零点、线性、回差和温漂；然后对独立样件逐级加载，验证至少 5 kgf 生存目标。钓线另加一根松弛约 1–2 mm 的 Dyneema 安全绳，防止梁意外断裂后丢钩。未经破坏试验前不得把 5 kgf 当作额定安全载荷。

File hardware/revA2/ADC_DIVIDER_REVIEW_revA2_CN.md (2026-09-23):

> **后续已采用180k/60.4k、1%（常见E96值）**：最坏Rth45.677kΩ；4.2V下17.471µA，分压30天12.579mAh。原理图/PCB/BOM/网表/固件已同步，见 `validation/revA2_divider/consistency.json`。静态电流预算、参考/建立时间和精度实测仍开放；下文保留原方案比较，180k/59.4k并非本次采用值。

# 电池分压阻抗与功耗复核（2026-09-23）

**设计开放，尚未修改R4/R5或宣称电压精度通过。** 主代理实际读取 [ST DS12992 Rev4](https://www.st.com/resource/en/datasheet/stm32g031f8.pdf) 第78页表59及第80页表60：RAIN最大50kΩ；表60还给出采样条件。不能仅用当前4MHz/160.5周期或C14就推定248kΩ已获规格保证。

以下是实际运行 `python3 validation/revA2_spi/adc_divider_options.py` 的计算结果。假设电池恒4.2V、分压电阻1%、C14名义100nF；不含漏电、参考误差、电容容差/偏压降容或其他负载，不是续航预测。

| R4/R5 | Rth最大（1%） | 4.2V静态电流 | 仅分压30天电量 | 名义RC全阶跃至半个12bit LSB |
|---|---:|---:|---:|---:|
| 现有1M/330k | 250.60kΩ | 3.158µA | 2.274mAh | 223.58ms |
| 候选180k/59.4k | 45.11kΩ | 17.544µA | 12.632mAh | 40.24ms |
| 候选100k/33k | 25.06kΩ | 31.579µA | 22.737mAh | 22.36ms |

两个候选保留相同名义分压比；原始ADC到名义毫伏的数学比值可保持，但电阻定义/静态断言、原理图、BOM、PCB值与验证记录必须同步修改。不能只改固件系数。180k/59.4k在列出的固定比值候选中静态电流较低，但采购精度/温漂和系统待机预算仍需纳入取舍。

还有开关分压/缓冲方案，会增加器件、面积、漏电和上电时序要求；本轮没有未经评估新增器件。现有代码未测VREFINT，仍用名义3.3V换算，需验证LDO压差下VDDA、输入漏电/反灌、连接电池后的RC建立和温度误差。软件读取完成只证明ADC原始码转换完成。

数字计算证据 `validation/revA2_spi/adc_divider_options.json`。下一步在准确电芯和待机目标基础上选定电阻/开关方案，完成跨文件一致性、ERC/DRC及采样建立验证；实物精度门槛保持开放。

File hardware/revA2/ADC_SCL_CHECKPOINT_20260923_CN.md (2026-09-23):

# ADC SCL 连接检查点 · 2026-09-23

已采用stage3，主板SHA256 `1b107b735467401e9e3c740cd033305a7a1a90b10bf3aedef7c3753b80e3ccb6`；NOT_FAB_RELEASED。

## 正式改动

PCB完成MCU/U1 pad20、R2 pad1与ADC/U4 pad13的SCL连接，经过F/In2/B/F，新增0.60/0.30mm过孔(9.55,10.25)、(9.1,19.4)、(5.365,21.0)，线宽0.15mm。没有In1信号。

相关REED B铜改为明确的折线路径，保留R10上拉、SW1信号脚和MCU输入连接；In2下段向右绕行避让SCL。正式版本没有移动器件、过孔或修改焊盘网络/封装/制造规则。独立文本审核除segment/via/zone外均保持，四层、1mm、12×35mm、43封装不变。

初版误将SW1连接支路当作可移除铜，并碰到已有过孔，产生短路/开路；官方检查检出后拒绝，没有进入主板。补读全部焊盘后恢复SW1完整路径并逐点修复。前后回退副本baseline/final以及每次候选和变化清单在validation/revA2_adc_bus。

## 实际工具证据

| 检查点 | 普通DRC错误 | 未连接 | 警告 |
|---|---:|---:|---:|
| baseline | 0 | 6 | 120 |
| stage1，拒绝 | 13 | 7 | 121 |
| stage2，拒绝 | 1 | 5 | 120 |
| stage3与主板复检 | 0 | 5 | 120 |

stage1分类：shorting_items5、clearance6、solder_mask_bridge2；stage2为REED支路碰3V3via的shorting_items1，stage3局部绕开后清零。采用前后警告type/UUID集合无变化。

实际执行命令：

```sh
bash tools/export_fab_revA2.sh
python3 tools/validate_revA2.py
python3 tools/check_divider_revA2.py --output validation/revA2_adc_bus/divider_consistency.json
python3 validation/revA2_adc_bus/summarize.py
```

官方KiCad10.0.6 ERC0/0，DRC普通错误0、5未连接、120警告、一致性0。制造脚本退出2，未导出生产文件。validate确认Rev.A1哈希不变；分压跨文件一致性通过。详细日志main_gate.log、validation.log及分类/位置清单comparison.json、repair_queue.csv。

另以KiCad自带Python运行check_invariants.py和tools/check_reference_revA2.py（主板对本组baseline，输出main_reference.json），均退出0；显式填铜后In1地单轮廓，六敏感网及原有外层铜无新增参考缺口。本项只比较本轮增量，不取消既有局部供电过孔的历史审查说明。

独立复核通过实际连通图确认REED的SW1.1/R10.2/U1.16及原有两via连通；SCL的U1.20/R2.1/U4.13及三个新via连通。REED新12段1962点、SCL新9段2598点，以≤0.02mm步长采样中心和双边，缺失点仅在自身via反焊盘（铜半径+0.15mm净空+0.01mm离散容差）内，未发现其他缺口。详见independent_review.md；不等于电磁回流、阻抗、I²C上升时间或实物验证。

## 剩余工作

5个缺口：SDA2（上部至MCU、MCU至ADC）、SCL1（上部传感器至MCU/上拉）、IMU_INT1、MOSI1。下一组继续I²C主干，随后IMU_INT/MOSI。

警告120与5项忽略规则仍需逐项审查。制造文件/独立查看器、采购器件与电芯资料、壳体STEP/3D、实物仍未完成。固件本轮未改也未重测；前次MCU8/8、host23/23、20ARM对象不代替最终ELF/板上验证。没有更改制造放行状态。

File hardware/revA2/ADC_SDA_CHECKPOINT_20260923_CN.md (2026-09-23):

# ADC SDA完成与3D缺件审查 · 2026-09-23

正式PCB SHA256 `07bc3e6bfeb425158fc84a676e46575252e4cc9e3bb62b5befcbbb1a239b4ae7`；I²C两条总线已全部接通，NOT_FAB_RELEASED。

## 改动

R1由B(3.8,10.4)移至(3.7,10.15)，关联线端同步。SCK In2原四段改为(4.8,11.2)→(5,11.2)→(7.55,13.75)→(7.55,15.475)，为SDA的B跨层桥让出空间。SDA从R1 pad1经B铜至via(5.8,12.85)，In2向下至via(4.825,19.525)，F经(4.825,20.1)→(4.095,20.83)接U4 pad14。线宽0.15mm、via0.60/0.30mm，不增加In1信号。

独立子任务初候选把ADC端via置于SMT pad内；主任务没有采用此端点，在隔离副本将其移至焊盘外。最终两个新via的铜环到最近焊盘包围框净距分别1.625mm、0.159619mm，不要求据此使用未经确认的填孔/盖孔工艺。

只改PCB铜及R1位置；原理图/封装库/焊盘网络/四层1mm/12×35mm板框保持。未修改Rev.A1或运行整板生成器。IMU_INT与MOSI本轮未采用改动，固件未改。

## 实际验证证据

子任务独立候选stage1：1项tracks_crossing；stage2：21 clearance、5 hole_clearance、1 solder_mask_bridge；均拒绝。stage3官方普通错误0/2未连接/122警告，随后主任务另改ADC端换层点。完整探索证据在validation/revA2_adc_sda_candidate；主任务采用前baseline、接收候选stage1、焊盘外修正版stage2、最终final在validation/revA2_adc_sda_adopt。

实际执行：

```sh
bash tools/export_fab_revA2.sh
python3 tools/validate_revA2.py
python3 tools/check_divider_revA2.py --output validation/revA2_adc_sda_adopt/divider_consistency.json
python3 validation/revA2_adc_sda_adopt/summarize.py
```

主板KiCad10.0.6 ERC0/0，普通DRC错误0、未连接3→2、警告122、一致性0。制造导出exit2拒绝Gerber/钻孔/CPL。validate确认Rev.A1哈希不变，分压一致性通过。详见main_gate.log、comparison.json、repair_queue.csv。

使用KiCad Python显式Fill的check_reference_revA2主板对baseline退出0：In1单轮廓、六敏感网和未变外层铜无新增缺口。check_invariants.py通过。

独立BFS确认SDA五器件U2.14/U3.1/U1.1/R1.1/U4.14连通，SCK与R1供电仍连通。主任务对端部修改后再次BFS，并按各段实际线宽采样全部变更铜中心/双边，共6549点，缺口距同网via最大0.456015667mm，按0.45mm反焊盘加0.01mm离散几何容差归类，不声称严格≤0.45mm或EM通过。证据在stage2/supplement.json和review.md。

## 本轮3D实际工具输出

新增validation/revA2_3d_audit，官方执行：

```sh
/Applications/KiCad/KiCad.app/Contents/MacOS/kicad-cli pcb export step --output validation/revA2_3d_audit/revA2_POST_ADC_SDA_REVIEW_ONLY_INCOMPLETE_MODELS.step hardware/revA2/smart_apo_common_revA2.kicad_pcb
```

退出0，生成1,665,009字节审查STEP，但日志报告Y1模型无法添加。实际清单43器件中35个有可解析的通用模型文件；J1/J2/J3/U2/U3/U5/SW1共7个未绑定模型，Y1绑定路径不存在。已有文件并不证明所购器件外形正确。current_export_manifest.json将STEP散列与当前PCB散列绑定；旧导出另行保留，不能混作当前板。

没有Rev.A2壳体装配STEP，未做独立3D查看器或完整干涉验证。只生成明确标记模型不完整/非生产的审查件，未勾选机械放行。Downloads按CT05/401020等相关名称检索未找到所购资料，阻塞未关闭。

## 剩余工作

电气连接剩IMU_INT和MOSI各1处。继续逐网隔离修复，随后审查122项警告、5类忽略规则和全板回流/制造细节。3D缺模型、所购器件/电芯资料、Rev.A2壳体、最终制造包/独立查看器与实物验证仍开放。固件已有8/8 MCU、23/23 host及20 ARM对象仅是前次证据，最终ELF/板上未通过。

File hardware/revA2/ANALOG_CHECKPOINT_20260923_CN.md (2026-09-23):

# 桥路输入与TIM2检查点（2026-09-23）

**目标继续活动，未完成交付，NOT_FAB_RELEASED。** 本轮解决桥路主差分输入的几何不对称，不能将此视为整个模拟性能或PCB放行已经验证。

## 当前实际结果

| 检查 | 改动前快照重跑 | 当前主文件重跑 |
|---|---:|---:|
| 普通DRC错误 | 0 | **0** |
| 未连接 | 25 | **22** |
| 警告 | 111 | **119** |
| 原理图一致性 | 0 | **0** |
| ERC | 先前0/0 | 本轮 **0/0** |
| host/native回归 | 23 | **23项通过** |
| MCU模型/runtime回归 | 1 | **2项通过** |
| Cortex-M0+对象构建 | 两变体 | 本轮重建 **20个对象通过** |
| 最终ELF链接 | 未完成 | 两变体 **exit 2** |
| 生产导出 | 拒绝 | **exit 2** |

警告增加来自重排后的丝印：压铜56、重叠47、板边9、文字高度6、背面文字未镜像1，全部仍开放；未更改规则严重性或关闭检查。普通错误0不含22项未连接，不能宣称DRC通过。

## 桥路布局及数字验证

U4横向置于F(6.0,24.4)，旋转90°；J3仍在F(7.4,32.6)，旋转180°。R8/R9在F(4.095,30.0)/(2.825,30.0)，C13在F(3.46,28.6)。C5/C6分别在F(2.825,19.6)/(1.555,19.6)，C7在F(7.905,29.5)。R10移至B(8.0,17.7)，D1移至F(2.3,32.65)。

所有受影响铜都先显式移除并重建，包括输入、参考、激励、DRDY、LED_GATE及去耦/上拉局部线。移动D1时同步焊盘内过孔和跨层相接铜，未只改坐标。中间候选曾发现跨层端点重复移动造成断线，已从原候选重做；失败副本 `finish1` 未采用。

| 输入网络 | 原铜长 / 过孔 | 当前铜长 / 过孔 |
|---|---:|---:|
| BRIDGE_A+ | 17.150mm / 0 | **2.670mm / 0** |
| BRIDGE_A− | 15.500mm / 2 | **2.670mm / 0** |
| AIN_P_FILT | 3.250mm / 0 | **2.770mm / 0** |
| AIN_N_FILT | 7.150mm / 0 | **2.770mm / 0** |

四网全部F.Cu、0.15mm宽。滤波总长包含0.155mm差分电容支路，电阻到ADC主路径各2.615mm。长度为CAD中心线去重铜段总长，不代表加工公差或噪声验证；也不是受控阻抗差分对。

- 独立只读复核确认14/16等器件焊盘网络映射没有被调换，C13仍跨AIN_P_FILT/AIN_N_FILT，未改接地。
- 主任务复核所有编号焊盘网络与基线一致。沿四条网络的中心及两侧边缘共696个采样点均有In1地覆盖，In1地为单一轮廓。
- C5/C6到U4电源脚各1.845mm；C7到VBG为2.145mm。针对复核意见补近端回流后，C5/C6地焊盘到最近接地过孔各0.72mm，C7约0.913mm，U4数字地约0.980mm。均在可追溯的接地连接组件中。
- S+参考线仍为约15.33mm/2过孔，S−约8.01mm/0过孔，参考线路并未获得主差分对同等对称性。此项及充电器附近的热/噪声影响、样机ADC噪声与标定继续开放。

**J3物理左右顺序已变化**：正面从左到右为6、5、4、3、2、1；必须使用 `BRIDGE_INTERFACE_revA2_CN.md` 的当前接线表，不能照旧图接线。

## LED供电补充

R6原位旋转180°，LED_A重新短接，过孔和相接铜同步调整，补0.25mm的3V3馈线。初次同名铜区仍未实际接主电源，官方连通性检查发现后，增加明确的F.Cu桥接至已连接的3V3网络，最终消除LED供电缺口。`led_supply`和`led_supply_finish`是未闭合的中间副本，最终采用`led_supply_bridge`。电池/LDO总链仍有未连接，不能称LED已运行。

## TIM2固件进展

`board_start_clocks()` 现在初始化寄存器级TIM2后端。它验证HSI16、分频、实际时钟源和CNT进展，PSC=15、ARR=0xffffffff；不使用循环次数伪造时间。配置变化、停转、超范围间隔和Stop唤醒后失败闭合。LSE、其余总线/ADC/低功耗驱动仍未完整实现。

宿主寄存器模型覆盖两变体的初始化、保留其他RCC位、自然回绕、配置损坏、停转、重复初始化和Stop失效；20个真实ARM目标文件编译及ARM静态分析已执行。**模型不等于真实APB/振荡器，不证明HSI精度或板上运行。** 详情与ST官方来源见 `firmware/mcu/VERIFICATION_TIM2_CN.md`。

仍无完整ELF：现有Clang可编译，但缺ARM链接器和compiler runtime。工具链安装授权问题尚未收到答复，未安装依赖。主机时间展开仍需明确的单次不中断采集条件，不会补缺测或自动完成异步重采样。

## 实际命令和证据

主任务重新运行：

```sh
python3 -m unittest discover -s firmware/host/tests -v
python3 -m unittest discover -s firmware/mcu/tests -v
make -B -C firmware/mcu objects-both CC=/opt/homebrew/opt/llvm/bin/clang
python3 firmware/mcu/tests/verify_arm_objects.py /opt/homebrew/opt/llvm/bin/llvm-nm
make -C firmware/mcu all CC=/opt/homebrew/opt/llvm/bin/clang VARIANT=0
make -C firmware/mcu all CC=/opt/homebrew/opt/llvm/bin/clang VARIANT=1
python3 tools/validate_revA2.py
git diff --check
bash tools/export_fab_revA2.sh
```

前四项通过，两次链接exit2，结构检查和diff检查通过，导出exit2。每组官方DRC使用 `/Applications/KiCad/KiCad.app/Contents/MacOS/kicad-cli pcb drc --format json --severity-all --units mm --refill-zones --schematic-parity`；主文件另加`--save-board`，另重跑错误级报告。ERC由导出门控重跑。

证据目录 `validation/revA2_analog/`：`baseline/`、`cluster/`、`finish1/`、`finish2/`、`ground_returns/`、`final/`，各有实际板/工程与DRC；`.changes.json`保存对象级修改；`analog_evidence.json`绑定主板哈希；`review.md`为补近端地过孔前的独立复核，相关意见已在最终候选处理；`commands.json`、`export_gate.log`、`comparison.json`、`repair_queue.csv`供复现。

本轮改变主PCB、官方报告/交接文档、`board.c`与`board_revA2.h`、新增TIM2寄存器模型测试及报告。Rev.A1、板框/层数/板厚/项目DRC规则和已有未涉及工作保留，未提交/重置分支。

## 下一步与仍开放门槛

优先完成SPI、I²C、NRST、IMU_INT、电池采样以及剩余电源连接，并审查参考线回流和所有丝印。U3专用引出/PAD2LID方案、原厂land/钢网复核仍有资料阻塞。所购CT05、电芯允许充电电流及尺寸、采购后缀、Rev.A2装配STEP/3D干涉和全部实物试验未通过。

完整交付目标未缩小。当前不能导出生产Gerber，也不能把ARM对象称可烧录固件。

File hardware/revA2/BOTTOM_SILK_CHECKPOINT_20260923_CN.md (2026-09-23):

# D1板边丝印检查点 · 2026-09-23

正式PCB SHA256 `33df907ab6cf1ddd62f012da16388b9dba40117633d571ee1f606bb7e43282dd`。官方KiCad10.0.6 ERC0错误/0警告、DRC0错误/0未连接/0一致性问题、79警告。NOT_FAB_RELEASED。

D1位号移到(0.65,32.1)mm，F.SilkS、90°、0.8mm字高、0.12mm笔画。左侧轮廓从(1.34,31.65)至(1.34,34.335)缩短至(1.34,33.8)；底部横线起点从(1.34,34.335)改为(1.8,34.335)，右侧轮廓完整保留。保留原开放端方向，避开板角；不删除全部方向轮廓。

首轮出现lib_footprint_mismatch，未忽略。建立项目库`LED_0805_2012Metric_RevA2_EdgeSilk.kicad_mod`并同步PCB/原理图D1引用后消除该项。基于当前板标准LED封装派生，仅板框丝印适配，不声称匹配已采购LED。

字段级检查证明PCB除D1 Reference、两段授权fp_line和库ID以外逐字节一致；原理图只变一个Footprint引用；项目不变。铜/焊盘/走线/阻焊/钢网不变。D1仍是pad1=LED_A、pad2=LED_K；此网络对应与标准库方向标识、实际所购LED阴阳极必须在装配前明确核验，不能以DRC通过替代。

官方DRC：silk_edge_clearance 4→1，其他丝印重叠27、压铜48、缺courtyard3不变，82→79，无新增项。剩板边项是J1背面轮廓。官方PDF+Poppler图面显示D1位号可辨认、轮廓在板框内；局部图面通过，不作实物极性验收。

实际命令：

- KiCad内置Python运行`validation/revA2_bottom_silk/edit.py`、`library.py`，独立副本试验；库脚本先修正Duplicate参数和SWIG类型转换，失败日志未作为验证通过。
- `kicad-cli pcb drc --format json --severity-all --units mm --refill-zones --schematic-parity -o validation/revA2_bottom_silk/candidate/drc_revA2_kicad10.json validation/revA2_bottom_silk/candidate/smart_apo_common_revA2.kicad_pcb`：0错误/0未连/79警告。
- `python3 validation/revA2_bottom_silk/verify.py`：授权块以外一致，无新增DRC。
- 采用后`bash tools/export_fab_revA2.sh --check-only`：exit0，ERC/DRC上述结果。
- `kicad-cli sch export netlist --format kicadxml --output hardware/revA2/netlist_revA2_kicad10.xml hardware/revA2/smart_apo_common_revA2.kicad_sch`：exit0，刷新封装引用。
- `python3 tools/validate_revA2.py`：exit0，Rev.A1哈希保持。

修改正式PCB、原理图D1封装引用、新项目封装及库README，刷新网表/校验报告和交接入口。固件未改未重测；未生成fab_export。证据目录包含baseline/candidate/final、invariants.json、日志、PDF/PNG和79项OPEN的warning_queue.csv。

下一步处理J1板边轮廓、底部R8/R9关联丝印及其他剩余警告。采购型号/极性、连接工艺、公差、板厂能力、当前3D与最终固件及实机门槛仍开放。

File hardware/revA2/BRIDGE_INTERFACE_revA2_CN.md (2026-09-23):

# Rev.A2 六线桥接口方向（当前候选）

本轮 J3 已旋转180°以配合短、成对的输入布线。**焊盘编号和网络定义没有改变，物理左右顺序已经改变。** 当前PCB仍未放行，本表用于审查，不是装配批准。

从 PCB 正面（F.Cu）看，板坐标 x 向右增大；J3 位于 y=32.6mm。由左至右：

| 位置 | 焊盘号 | 网络 | 六线桥功能 | x/mm |
|---|---:|---|---|---:|
| 最左 | 6 | BRIDGE_A− | 差分信号负输入 | 4.225 |
|  | 5 | BRIDGE_A+ | 差分信号正输入 | 5.495 |
|  | 4 | BRIDGE_S− | 远端激励负端感测，接REFN | 6.765 |
|  | 3 | BRIDGE_S+ | 远端激励正端感测，接REFP | 8.035 |
|  | 2 | GND | 激励负端E− | 9.305 |
| 最右 | 1 | BRIDGE_E+ | 激励正端E+ | 10.575 |

不得按旧版本的物理左右顺序接线。线色未指定，应以所购六线桥的实际引脚资料核对；S− 与 E−分别回线，不在接口处随意合并。阿波装配变体不贴J3及应变ADC相关器件，水中变体为手工引线。

本表从当前KiCad焊盘对象提取，证据 `validation/revA2_analog/analog_evidence.json`。BOM/CPL及丝印方向仍要在最终布局与生产文件审查时复核。

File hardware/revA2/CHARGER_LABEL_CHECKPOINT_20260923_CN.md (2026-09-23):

# 充电区域位号检查点 · 2026-09-23

正式PCB SHA256 `94066e22c2fb98ba4b941ccdb95fd8ff4e4b268be3cedd7140fdf393a44213fe`。官方ERC0错误/0警告，DRC0错误/0未连接/0一致性问题、70警告；NOT_FAB_RELEASED。

只修改三个B.SilkS Reference字段，保持镜像/可见属性：U6(7.8,22.1)mm/0°、R3(1,22)mm/90°、C11(1,24.6)mm/90°，字高0.8mm、笔画0.12mm。剔除三个授权字段后PCB逐字节一致，原理图/项目逐字节一致，铜/焊盘/器件位置/规则不变。

官方分类：silk_overlap26→25、silk_over_copper46→42、missing_courtyard3不变，总75→70。按type/关联UUID比较无新增项。背面官方PDF经Poppler渲染并查看，三个位号清楚，局部图面通过；不是整板或实物通过。

实际命令：

- KiCad内置Python运行`validation/revA2_charger_labels/edit.py`，只修改独立候选。
- `kicad-cli pcb drc --format json --severity-all --units mm --refill-zones --schematic-parity -o validation/revA2_charger_labels/candidate/drc_revA2_kicad10.json validation/revA2_charger_labels/candidate/smart_apo_common_revA2.kicad_pcb`：0错误/0未连/70警告。
- `python3 validation/revA2_charger_labels/verify.py`：字段不变量和无新增项通过。
- 采用后`bash tools/export_fab_revA2.sh --check-only`：exit0，官方ERC/DRC上述结果。
- `python3 tools/validate_revA2.py`：exit0，Rev.A1哈希保持，fab_export不存在。

修改正式PCB，刷新ERC/DRC/校验报告、检查点与交接入口。固件未改未重测。证据`validation/revA2_charger_labels/`含baseline/candidate/final、invariants.json、官方日志、PDF/PNG、visual_verdict.json和70项OPEN队列。

下一步处理正面MCU与上部去耦密集区域25项重叠/42项压铜。3项连接区courtyard、采购型号/极性、Pogo/板厂工艺、当前板壳体3D、最终ELF与板上验证仍开放。

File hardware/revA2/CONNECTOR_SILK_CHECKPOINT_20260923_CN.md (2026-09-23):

# J2/J3丝印轮廓检查点 · 2026-09-23

正式PCB SHA256 `146b85a298fe51a1330474656d7318dcf9f9357f232ff399242d1a810aaf2057`。官方ERC0错误/0警告、DRC0错误/0未连接/0一致性问题、5警告；NOT_FAB_RELEASED。

J2/J3丝印矩形长轴两端各外移0.25mm。J2局部x范围±4.25→±4.5mm；J3±3.62→±3.87mm，宽轴±0.8mm、线宽0.12mm保持。正式板及POGO_7x1.27mm/PAD_6x1.27mm两个项目库同步。剔除两处授权矩形后PCB逐字节一致，库除对应矩形外逐字节一致；原理图/项目不变。铜、焊盘、钢网、阻焊、位号和Fab标识不变。

官方silk_over_copper6→2，missing_courtyard3不变，总9→5，无新增type/UUID违规。正反面PDF/PNG已查看，轮廓与开窗有间隔且位于板内，不改变连接器方向。丝印边界不代表焊线/接触工艺空间通过。

实际命令：

- KiCad内置Python执行`validation/revA2_connector_silk/edit.py`，独立副本试验。
- `kicad-cli pcb drc --format json --severity-all --units mm --refill-zones --schematic-parity -o validation/revA2_connector_silk/candidate/drc_revA2_kicad10.json validation/revA2_connector_silk/candidate/smart_apo_common_revA2.kicad_pcb`：0错误/0未连/5警告。
- `python3 validation/revA2_connector_silk/verify.py`：修改范围、项目库增量与无新增项通过。
- 正式采用后`bash tools/export_fab_revA2.sh --check-only`：exit0，官方ERC/DRC上述结果。
- `python3 tools/validate_revA2.py`：exit0，Rev.A1哈希保持，fab_export不存在。

改动PCB、两个库、报告及交接入口，固件未改未重测。证据`validation/revA2_connector_silk/`包括baseline/candidate/final、invariants.json、日志、正反面PDF/PNG、visual_verdict.json及5项OPEN队列。

下一步单独核对U1/U5方向多边形的2项压铜，不直接删掉方向标记。J1/J2/J3 courtyard、采购型号/极性、工艺公差、当前3D及固件/实物验证仍开放。

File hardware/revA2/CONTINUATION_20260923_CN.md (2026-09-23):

# Rev.A2 后续开发检查点（2026-09-23）

> **活动目标最新检查点**：ERC **0/0**；普通DRC错误 **0**，仍有 **25未连接、111警告**，一致性0，**NOT_FAB_RELEASED**。LSE已同面无过孔；host/native 23项＋runtime 1项测试通过，两变体ARM目标文件可编译，最终ELF/HAL/板上仍未完成。详见 [完整目标检查点](GOAL_CHECKPOINT_20260923_CN.md)。下方旧数字为历史。

**官方 DRC 仍未通过，NOT_FAB_RELEASED。** 本轮将普通 DRC 错误从 12 降到 0，未连接从 59 降到 40；不能把“普通错误 0”说成“整板 DRC 通过”。108 项警告尚未逐项关闭。

| 实际检查 | 本轮开始 | 最终主文件 |
|---|---:|---:|
| KiCad | 10.0.6 | 10.0.6 |
| DRC 普通错误 | 12 | **0** |
| 未连接项目 | 59 | **40** |
| DRC 警告 | 108 | **108** |
| 原理图一致性问题 | 0 | **0** |
| ERC | 上轮 0/0 | 本轮重跑 **0/0** |
| native 回归 | 15 | **17 项通过** |
| ARM 构建 | 未通过 | **exit 2：缺 arm-none-eabi-gcc** |
| 生产导出 | 拒绝 | **exit 2：仍有未连接，拒绝导出** |

## PCB 改动与依据

- U2 原矩形禁布将正常焊盘引出也拦截。依据 [ST TN1383 §3.2–3.5](https://www.st.com/resource/en/technical_note/tn1383-pcb-design-guidelines-for-mems-sensors-stmicroelectronics.pdf) 的等宽、长轴向外引出及本体下保护要求，改成两层规则：**完整本体仍禁过孔和覆铜；走线只开放 14 个径向 0.20 mm 通道，实际引线 0.15 mm**。0.20 mm 是工程实现尺寸，不是 ST 给出的推荐数值；不代表原厂 Gerber/装配认证。
- 14 个焊盘位置、铜尺寸、编号和网络未改。通道彼此隔离，不形成横穿本体的路径；错误网络仍由正常铜间距/短接检查约束，规则本身不是按网络的白名单。
- 完成 U2 五个地脚及局部供电连接。地通过普通短线引出，不把地平面直接铺入本体。
- REED_WAKE 原来在顶层向上绕行后再向下，切断右侧去耦附近的地连接。改为局部逃线进入 In2.Cu，保留 In1.Cu 地参考；未通过的路径副本已弃用。
- 用实际地线连接 C16/C5/U6/U7，关闭余下热焊盘错误，未降低最少热引线规则或设置错误豁免。
- 接通 Flash 供电、CS 上拉供电、压力去耦的 3V3；调整阻挡供电的 FLASH_CS 局部段；接通电池分压与滤波节点。所有新增过孔仍为 0.60/0.30 mm。

U3 **未修改**：其外围焊盘与中央 PAD2LID 不能机械套用 U2 径向规则。原厂允许金属盖接地或悬空，但本项目保留原接地选择，未擅自改网。评估板 Gerber 下载仍失败，中央接地/其他引出方式继续待审。访问证据在 `validation/revA2_continue/sources/mems_source_access_20260923.json`；没有宣称取得或重新校验历史 ZIP。

## 正反例与回退证据

本轮所有候选先写 `validation/revA2_continue/` 的独立子目录，再运行 KiCad 官方 DRC；主板只合入最终通过局部检查的 `battery_sense` 候选。

- `u2_rule_evidence.json`：2000 个确定种子的本体采样点检查；完整投影仍禁 via/pour；只开放径向通道；原焊盘几何/网络不变。
- `negative_inner_track`：本体内线路触发 `items_not_allowed`。
- `negative_body_via`、`negative_escape_via`：本体或逃线通道里的过孔均触发 `items_not_allowed`。
- `negative_short`：将不同电源/地实际连在一起，触发 `tracks_crossing ×2`、间距和阻焊桥错误。不是 `shorting_items` 类别，不混淆统计。
- `negative_wrong_net`：只标错一条孤立线的网络，KiCad 连通性重建后没有新增错误；**此试验不计作有效反例**。
- `reed`、`reed2`、`flash_power`、`mcu_power` 均有失败报告。尤其 MCU 电源试接碰到旧 LSE/I²C 铜及 UART 净空，未合入，下一轮需先调整这些网络。
- `comparison.json`：每一阶段完整分类计数；`repair_queue.csv`：当前所有缺口和警告的网络、坐标、UUID；`unconnected_by_net.json`：逐网数量。
- `baseline/` 和 `final/` 保存完整工程快照；`board_invariants.json` 证明所有编号焊盘网络、12×35 mm 板框、四层/1.0 mm 及工程规则文件保持不变。未提交、未 reset、未动 Rev.A1。

独立子代理已只读复核规则几何和上述官方报告。规则可作为当前工程实现采用，land/钢网、传感器偏置及实际装配仍未认证。

## 固件改动与实际测试

移除 CPU 每循环自增 1000 µs 的伪时间，新增 `board_time_us()` 契约；没有真实 HAL 时基时失败闭合。调度改用整数相位，支持 uint32 回绕和 104/208/320 Hz 非整数微秒周期；迟到只读取当前一次，记录跳槽数，不伪造补采。

本轮主任务实际运行：

```sh
python3 -m unittest discover -s firmware/host/tests -v
make -C firmware/mcu
python3 tools/validate_revA2.py
bash -n tools/export_fab_revA2.sh
git diff --check
bash tools/export_fab_revA2.sh
```

结果：17 项通过；ARM 构建 exit 2；结构检查通过但保留 PCB 门槛；shell 语法与 diff 检查通过；导出 exit 2。两变体各模拟三小时、1 ms 轮询，验证累计名义次数和多次计数回绕。另实际对 8 个 C 源文件×2 变体执行 `clang --analyze`，全部退出 0，但 `board.c` 仍有合计 4 条已知 MMIO 固定地址警告，不能写成零警告。

完整命令/stdout/stderr/退出码在 `validation/revA2_continue/commands.json`；测试日志 `native_tests.log`；详细固件边界见 `firmware/mcu/VERIFICATION_TIMING_CN.md`。没有新增依赖，没有 ARM 映像或板上运行通过结论。真实 HAL 时钟、DRDY/FIFO、总线吞吐、Stop 连续性仍缺验证；主机仍拒绝跨 71.6 分钟的原始时间戳回绕，尚需显式时间重建。scipy、样机和测量设备缺失状态未改变。

官方 PCB 最终命令（CLI 绝对路径 `/Applications/KiCad/KiCad.app/Contents/MacOS/kicad-cli`）：

```sh
kicad-cli pcb drc --format json --severity-all --units mm --refill-zones --save-board --schematic-parity -o hardware/revA2/drc_revA2_kicad10.json hardware/revA2/smart_apo_common_revA2.kicad_pcb
kicad-cli pcb drc --format json --severity-error --units mm --refill-zones --schematic-parity -o hardware/revA2/drc_revA2_errors_only_kicad10.json hardware/revA2/smart_apo_common_revA2.kicad_pcb
```

实际执行使用绝对路径；ERC 由导出门控中的 `sch erc --format json --severity-all` 重跑，报告位于 Rev.A2 目录。不能仅看错误级报告的 0 项而忽略另列的 40 项未连接。

## 剩余工作与下一步

1. 成组重新安排 LSE 的同面短连接，调整阻挡 MCU 电源的旧 I²C/LSE/UART 局部铜，不能仅移动晶体而保留旧线。
2. 完成余下 40 个连接缺口：3V3 11、GND 7、I²C SDA/SCL 各3、NRST 3、VBAT 3、LSE_OUT 2、SPI三线各1、IMU_INT/VBAT_SENSE/BRIDGE_S+/VBG/CHARGE_IN 各1。优先电源与回流，再模拟/LSE及总线；已连通桥路仍需成对/长度/回流质量审查。
3. U3 引出/中央焊盘方案、U2 land/钢网原厂交叉验证仍需资料。CT05所购图纸、电芯允许充电电流、采购后缀、Rev.A2装配 STEP、3D干涉及全部实物试验仍开放。
4. 108项丝印/文字警告逐项处理。原工程忽略的5类检查也仍需恢复适用检查或写明处置依据，不能视为已完成审核。
5. 所有布线和制造门槛关闭后再生成/独立查看 Gerber、钻孔、最终 BOM/CPL；当前没有生产输出。

## 本轮主要改动文件

- `hardware/revA2/smart_apo_common_revA2.kicad_pcb`、U2 `.kicad_mod`、官方报告与状态/来源文档。
- `tools/validate_revA2.py`：适配 KiCad 格式化后的封装，检查两层保护规则名称/属性，标明评估板资料仍阻塞。
- `firmware/mcu/src/{main,board,app,sensors}.c`、对应头文件、`tests/app_errors.c`、新 `tests/sensors_timing.c`、README/时基报告及备份。
- `firmware/host/tests/test_firmware_contract.py`、`validation/revA2_continue/` 和交接状态。

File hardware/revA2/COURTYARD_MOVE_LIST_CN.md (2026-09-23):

# 人工 courtyard 挪位清单（连铜一起挪）

> **活动目标最新桥路检查点**：ERC **0/0**；普通DRC错误 **0**，仍有 **22未连接、119警告**，一致性0，**NOT_FAB_RELEASED**。主差分输入已成对、同面、零过孔；J3物理顺序已旋转。TIM2寄存器后端模型测试通过，23项host＋2项MCU测试通过，最终ELF/板上未完成。详见 [桥路与时基检查点](ANALOG_CHECKPOINT_20260923_CN.md)。下方旧数字为历史。

日期：2026-09-09。官方 DRC 现有 **10** 处封装重叠。脚本在已布线板上改坐标会把焊盘压到旧铜（CP05：错误 108→175），**不要再跑** `tools/nudge_courtyard_revA2.py`。

在 KiCad PCB 编辑器里：选中封装后用 **D**（拖动，走线跟着焊盘），不要只用改坐标。

当前冲突（`drc_revA2_kicad10.json`）：

| 冲突 | 建议 |
|---|---|
| U1 与 C3 | C3 是 IMU 去耦，沿 U1 上方空隙拖到约 y=8.0，离开 TSSOP courtyard |
| U6 与 R3 | R3 是 MCP73831 编程电阻，拖到 U7 附近，不要靠 LDO |
| U6 与 C11 / C12 | C11/C12 跟着 U6 的 IN/OUT，整组往板底中间挪，离开 LED |
| U6 与 D1 | D1/R6 留在板底角落，U6 不要压 LED |
| C11 与 D1 / C12 | 拉开 0402 间距 ≥ 0.5 mm courtyard |
| R7 与 Q1 | 都在背面，拖开 LED 栅极电阻与 MOSFET |
| C7 与 C10 | 右侧 0402 柱，把 C10 沿 x=10.55 再往下移约 1.2 mm |

挪完后只跑官方 DRC，不要重新自动布线。目标先把 `courtyards_overlap` 降到 0；短路和未连接仍按单网手工处理。

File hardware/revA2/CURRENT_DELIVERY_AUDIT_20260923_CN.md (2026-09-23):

# 当前交付证据审查 · 2026-09-23

PCB SHA256 `5d1f8a7a330c3bbbf86d8e15930d2b26694e2a207ddf2a994f410223839efa94`。本阶段PCB、原理图和固件生产代码均未改，上一阶段官方ERC0/0、DRC0错误/0未连/3项courtyard仍适用于同一板文件。NOT_FAB_RELEASED。

## 当前3D审查件

实际运行`kicad-cli pcb export step --subst-models --output validation/revA2_current_delivery_audit/revA2_CURRENT_REVIEW_ONLY_INCOMPLETE.step hardware/revA2/smart_apo_common_revA2.kicad_pcb`，exit0；STEP 1664963字节，板与STEP SHA在manifest.json。旧3D审查件对应07bc3e…板，已明确为历史，不能当当前板证据。

KiCad内置Python重新遍历43封装模型：35个模型引用可解析为现有通用STEP；J1/J2/J3/U2/U3/U5/SW1仍未绑定模型；Y1绑定路径仍无法解析，导出日志有其模型诊断。exit0不是模型齐全或碰撞通过。无Rev.A2壳体及准确实购物料外形，未运行独立3D查看器/装配碰撞检查。

## 固件最终构建实测

实际逐版本运行：

```sh
make -C firmware/mcu all CC=/opt/homebrew/opt/llvm/bin/clang BUILD=validation/delivery_link_audit VARIANT=0
make -C firmware/mcu all CC=/opt/homebrew/opt/llvm/bin/clang BUILD=validation/delivery_link_audit VARIANT=1
```

两次make均exit2，最终链接失败：Clang `invalid linker name in argument '-fuse-ld=lld'`。新目录生成20个目标文件，二进制标头逐个确认ELF32 little-endian、ET_REL、EM_ARM，哈希在manifest.json；没有生成最终ELF。因此状态仍是“ARM目标文件可编译”，不能叫“最终固件构建通过”或“板上运行”。

现有LLVM bin中没有lld，lib/clang中没有ARM builtins archive；rustc及用户Rust工具链目录也不可用，没有可复用的rust-lld。链接至少仍需ARM链接器和兼容的__aeabi运行库。未安装新工具或依赖；既有授权问题未有答复。无样机，未烧录/上板。旧模型/runtime测试证据不因本次对象构建变成硬件验证。

## 产物与下一步

`validation/revA2_current_delivery_audit/`含当前STEP、当前模型清单、官方导出日志、两份实际链接日志、退出码、20对象及STEP哈希清单；对象在firmware/mcu/validation/delivery_link_audit/。更新3D_CHECK_PARKED_CN.md和MCU README状态入口。

继续可独立进行的最终BOM/装配变体/极性一致性核查。缺失的具体输入仍为连接工艺courtyard及Pogo尺寸/定位公差、CT05所购图纸、401020允许充电电流、核心采购后缀/MLCC有效容量、Rev.A2壳体/模型、最终链接工具与板上设备。没有生产Gerber导出或FAB_RELEASED声明。

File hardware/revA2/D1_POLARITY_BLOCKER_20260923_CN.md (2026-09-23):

> 数字设计内部冲突现已修复，见D1_POLARITY_FIX_20260923_CN.md。以下为发现时历史证据；所购LED验证仍开放。

# D1极性约定冲突 · 2026-09-23

状态：BLOCKED_CONFIRMED_SYMBOL_FOOTPRINT_POLARITY_CONVENTION_CONFLICT。这是数字设计内部可修复问题，不只是等待所购LED资料。当前不允许将D1方向标识用于生产装配。

实际执行`python3 validation/revA2_led_polarity/audit.py`，exit0表示审查脚本成功识别冲突，不代表电路通过。证据audit.json绑定当前板SHA256 `5d1f8a7a330c3bbbf86d8e15930d2b26694e2a207ddf2a994f410223839efa94`与官方网表哈希；installed_Device_LED_symbol.txt为本机KiCad10.0.6库的LED符号摘录。

- 当前D1使用SmartApoRevA2:PASSIVE2通用无极性符号。
- 官方网表：D1.1=/LED_A，D1.2=/LED_K；LED_A接R6，LED_K接Q1漏极。
- 本机Device:LED明确1=K、2=A；派生来源LED_SMD:LED_0805_2012Metric采用KiCad阴极为1脚约定。
- 项目LED封装沿用了标准方向轮廓/Fab及3D方向，只曾裁短板边丝印。故当前电气定义与来源库的极性含义相反；前述“保留轮廓方向”的检查只证明未改图形方向，不能证明LED极性正确。

官方约定来源：[KiCad IDF Exporter — Pin orientation and positioning](https://docs.kicad.org/5.1/en/idf_exporter/idf_exporter.html#_pin_orientation_and_positioning)。该旧版文档作为约定背景，当前实际引脚命名由本机10.0.6库摘录直接佐证。

当前ERC0/0、DRC0错误/0未连/3项courtyard不能捕捉这个通用符号造成的极性冲突，不能据此放行。尚无所购LED准确MPN，器件实体标志与光学性能也未验证。

下一步在独立副本将D1换为明确A/K语义的符号，协调引脚编号、实际焊盘网络、阴极丝印/Fab及3D方向；优先保持已有铜几何。逐项验证R6→A、K→Q1漏极的物理连接、模型/标记一致性，再重跑官方ERC/DRC与BOM检查。不得只改网名或只旋转位号掩盖问题。

本阶段未改PCB、原理图、库或固件，只新增审查脚本/证据/本报告与交接阻断入口；因此未重复运行无修改的ERC/DRC。没有Gerber或生产BOM/CPL导出，NOT_FAB_RELEASED。

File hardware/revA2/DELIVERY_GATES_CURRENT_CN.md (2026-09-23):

# Rev.A2 当前交付门槛

状态：**NOT_FAB_RELEASED**。最新同版本审查文件在validation/revA2_review_bundle，源/输出哈希在manifest.json；旧STEP/PDF须按哈希辨别，不能混用。

| 门槛 | 当前证据 | 未完成/下一步 |
|---|---|---|
| 官方电气与PCB一致性 | KiCad10.0.6 ERC0/0、DRC0错误/0未连/0一致性问题 | 最终冻结/导出前仍须同版本重跑 |
| 丝印与方向 | 丝印DRC清零；D1明确1=K、2=A，铜网络不变 | 所购LED/IC外观、实际贴装方向与变体核验 |
| 连接区装配 | J1/J2/J3共3项missing_courtyard开放 | 需要电池线径/焊接/应力释放、桥路线束占用、Pogo探针外形/接触直径/定位公差；不能用丝印框推定 |
| 板厂能力 | 当前孔径/孔盘0.30/0.60mm、记录有几何审查 | 确认目标板厂叠层/板厚/阻抗与最小制造能力；两个Pogo焊盘内孔的接触工艺仍未合格 |
| 采购与BOM | 43位号、标称阻容值、完整封装ID/变体一致性检查通过 | U5目录编号冲突、CT05所购图纸、401020容量/保护/允许充电电流、晶体CL/drive、MLCC有效容量、Q1/D1准确MPN等未闭合 |
| 原理图与装配图 | 当前原理图已修正越页、标签和IC/阻容显示；43封装具原位Fab标识 | 最终带变体/工艺/极性说明的制造审阅；图形检查不代替电路性能验证 |
| 3D与机械 | 当前板STEP已导出；35模型引用可解析 | J1/J2/J3/U2/U3/U5/SW1未绑定，Y1路径不可解析；缺准确外形/Rev.A2壳体、电芯/压力口/O形圈；无独立3D碰撞/间隙通过 |
| MCU最终构建 | 20个ARM ELF32 REL目标文件；两变体make all实测在链接失败 | 缺lld及兼容ARM builtins，未安装新依赖；无最终ELF、无最终链接内存/栈结论 |
| MCU功能与主机 | 已有寄存器模型/协议测试；区分对象编译与上板 | 真正Stop/RTC跨睡眠时间及咬钩检测仍未完成；真实总线/传感器/Flash掉电/UART/功耗/ADC/LSE测试需样机和设备 |
| 制造输出与独立查看 | 没有生产Gerber/钻孔/CPL输出 | 前述门槛关闭后才走export_fab_revA2.sh，独立查看层/板框/孔/阻焊/钢网/方向，不能提前写FAB_RELEASED |

可独立继续：审查尚未完成的固件功能与现有测试范围，准备明确的台架测试步骤；有准确采购或机械输入后逐项关闭对应门槛。不能把外部阻塞项改写成默认通过。

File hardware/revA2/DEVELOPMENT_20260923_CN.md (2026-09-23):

# Rev.A2 开发与验证检查点（2026-09-23）

> **2026-09-23 后续实测**：ERC **0/0**；普通 DRC 错误 **0**，仍有 **40 个未连接、108 个警告**，原理图一致性 0，**仍未通过 DRC / NOT_FAB_RELEASED**。U2 径向逃线规则已实现并通过正反例检查；固件 **17 项 native 回归通过**，ARM/板上未验证。详见 [后续开发记录](CONTINUATION_20260923_CN.md)。下方早期数字保留为历史；勿重新生成整板。

本轮推进了 PCB 与固件，**完整布线和发行目标尚未完成，仍为 NOT_FAB_RELEASED**。以下为本轮实际工具证据，不以历史记录代替验证。

## 当前结果

| 检查 | 开始时实测 | 本轮主文件最终实测 |
|---|---:|---:|
| KiCad 版本 | 10.0.6 | 10.0.6 |
| 官方 ERC 错误 / 警告 | 0 / 0 | 0 / 0 |
| 官方 DRC 错误 | 104 | **12**（全部 starved_thermal） |
| 官方 DRC 警告 | 133 | **108** |
| 官方未连接项目 | 74 | **59** |
| 短路 | 24 | **0** |
| 普通间距 / 孔间距 | 15 / 7 | **0 / 0** |
| 封装 courtyard 重叠 | 10 | **0** |
| 铜到板边 / 阻焊桥错误 | 7 / 25 | **0 / 0** |
| 禁布违规 | 0 | **0** |
| 原理图一致性 | 开始的基线命令未启用 | **0**（显式启用） |
| 固件 native 回归 | 未建立本轮证据 | **15 项通过** |
| ARM 可启动构建 / 板上运行 | 未验证 | **未完成 / 未验证** |

`violations` 的错误/警告与 `unconnected_items` 分开计数，不能把 12 项错误误称整个 DRC 只剩 12 项。原理图中的 9 个明确 NC 引脚也不等于 PCB 的 59 个未连接。

Git 保持 `cursor`，`cursor/codex/main` 均从 `830e5a6` 起步；未 reset、清理或提交已有工作。Rev.A1 哈希检查通过，所有编号焊盘的网络映射与开始时完全相同。板仍为四层、1.0 mm，43 个封装，所有过孔为 0.60/0.30 mm。详见 `../../validation/revA2_20260923/board_invariants.json`。

## 已改变的 PCB 与原因

1. C8 离开背面 J2 Pogo 触点，移开两个冲突地过孔，消除 Pogo/充电/复位短路。
2. 修正 U2：ST 图中的 L/W 被旧记录误读为 X/Y。顶视投影现在为 X=3.0、Y=2.5 mm，项目库改名并同步原理图、网表；保留脚号、网络和焊盘 UUID。改动前确认 U2 没有相接走线。**0.625×0.35 mm 是候选 land，不是已获 LSM6DSO 原厂装配认证**，见 `LSM6DSO_FOOTPRINT_SOURCE_CN.md`。
3. U7/C9/C10 移出底部桥接口；充电器 U6/R3/C11/C12 移到背面，单独重接 CHG_PROG。充电器接近模拟区的热/噪声影响仍需布局复审和实测，不能据 DRC 判定模拟性能通过。
4. 调整 Q1/R7、D1/R6、C3/J1 及局部过孔；修改相接走线端点，移动焊盘内过孔时同步跨层相接走线。LED_A 的旧连接单独拆除并重接，未运行迷宫或全板生成器。
5. 接通 LDO 输入/输出去耦和充电器电容短连接；补 LDO→3V3 内层平面、J1→VBAT 平面馈线，消除孤立电源铜区和悬空过孔警告。删除一个同网同尺寸同位置的重复磁簧过孔。
6. 外层热引线宽度、热间隙、铜区最小厚度一致设置为 0.15 mm，仍符合当前候选线/隙规则，未降低最少热引线数。实际板厂能力和焊接工艺仍需确认。
7. 根据官方网表同步 43 个 `Population` 字段；原理图一致性从首次扩展检查的 43 项字段警告降为 0，双装配表未改变。

所有几何试验先写独立副本，再跑官方 DRC。主板只合入最终经过检查的链条，没有把失败试验的铜直接留在主板。

## 回退与每组计数

完整副本、分类计数和对象级修改日志位于 `../../validation/revA2_20260923/`：

- `baseline/`：开始时 PCB/原理图/工程、官方 ERC/DRC、已有 tracked 改动补丁及项目库。旧错误 U2 mod 保存在此处用于回退，不能作为当前封装选型。
- `stage*/`：每次候选 PCB、工程、原理图、库和官方 `drc.json`；`smart_apo_common_revA2.changes.json` 记录移动前后位置、调整端点 UUID 及明确局部路径。
- `comparison.json`：所有阶段错误/警告/未连接与按类型计数；`repair_queue.csv`：每一个仍开放问题的网络、坐标、UUID 和处置状态。
- `final/`：本轮最终板及报告；`local_repairs.py` 只向不存在的输出文件写入，拒绝覆盖输入。不是全板自动布线器，也不是下轮应盲跑的生产脚本。

明确不采用：stage04 充电组前移使旧铜产生新短路；stage06 背面层识别不完整，已由 stage06b 纠正；stage07 背面中部与已有 SWD/UART/SPI 铜冲突；stage13 热引线小于铜区最小厚度，虽错误归零却导致未连接升至 85，已拒绝；stage14_probe 仅作禁布诊断，未合入。stage08–11 是连续 LED/板边修复的中间副本，不能单独作为已通过板。

## 尚未解决的硬件工作，按执行顺序

1. **先审查 U2/U3 逃线与禁布规则的可实现性。** U2 候选禁布为整个本体投影，而焊盘也在投影内。stage14_probe 从 U2 pad2 `(1.1375,6.35)` 向外接到 `(0.65,6.35)`，0.15 mm 线宽、0.4875 mm 长，官方新增 `items_not_allowed`；已撤回，保留原规则。必须以原厂布板/焊接指南、评估板铜/钢网证据区分端子接线通道与其余本体下禁布区，不能简单关闭规则。U3 PAD2LID 接地逃线也需一并复核，当前还未接通。ST STEVAL-MKI196V1 页面有 Gerber，但本次下载接口失败，尚未取得用于交叉核对的压缩包。
2. **补接地与 12 个热焊盘连接。** 位置见 CSV；包括 U2 的 1/2/3/6/7，U6/U7 地脚，C1/C5/C14/C16/C17。保持最少热引线规则，局部增接地走线/过孔与调整间隙后逐组跑 DRC，不以 direct-connect 或规则豁免掩盖工艺问题。
3. **完成模拟与 LSE。** 尚有 BRIDGE_S+、VBG 未接；已接通的桥输入也没有完成短、并行、少过孔及连续回流审查。Y1 在背面、MCU 在正面，现有布置不满足 LSE 同面无过孔目标，需成组重排 Y1/C15/C16 并同步铜；不能只勾“网络已通”。
4. **剩余电源/信号逐网完成。** 数量见 `unconnected_by_net.json`，优先地和电源、NRST，再 SPI、I²C、IMU_INT/VBAT_SENSE；59 是连接缺口数，不是 59 个独立网络。保持 U2/U3 规则和连续 In1 回流，不能以铺铜覆盖或修改网络名清零。
5. **警告逐条审查。** 当前 108 项为丝印压铜 55、丝印重叠 39、丝印板边 7、文字高度 6、背面文字未镜像 1。CSV 全部保持 OPEN，没有进行空泛整体豁免。原工程还忽略了 5 类检查（含 missing_courtyard、track_not_centered_on_via），完整键列在 validation_report；这不等于这些项目已经合格，放行前应恢复适用检查或逐项写明依据。
6. **资料/机械/实物阻塞继续开放。** 所购 CT05 精确后缀及焊盘图；所购带保护 401020 的尺寸、公差、保护板、允许充电电流和温度范围；LSM6DSO land/钢网；W25Q256JVEIQ 中央焊盘工艺；其余采购后缀；Rev.A2 壳体/电池/Pogo/器件 STEP、压力口与 O 形圈装配。50 mA 仍只是候选，未用相似电芯推定通过。15 m 压力、盐水、梁标定及首件装配均无样机证据。

## 实际复核命令与结果

在项目根目录运行，`KICAD` 表示 `/Applications/KiCad/KiCad.app/Contents/MacOS/kicad-cli`：

```sh
"$KICAD" version
"$KICAD" sch erc --format json --severity-all -o hardware/revA2/erc_revA2_kicad10.json hardware/revA2/smart_apo_common_revA2.kicad_sch
"$KICAD" sch export netlist --format kicadxml -o hardware/revA2/netlist_revA2_kicad10.xml hardware/revA2/smart_apo_common_revA2.kicad_sch
"$KICAD" pcb drc --format json --severity-all --units mm --refill-zones --save-board --schematic-parity -o hardware/revA2/drc_revA2_kicad10.json hardware/revA2/smart_apo_common_revA2.kicad_pcb
"$KICAD" pcb drc --format json --severity-error --units mm --refill-zones --schematic-parity -o hardware/revA2/drc_revA2_errors_only_kicad10.json hardware/revA2/smart_apo_common_revA2.kicad_pcb
python3 tools/validate_revA2.py
python3 -m unittest discover -s firmware/host/tests -v
bash -n tools/export_fab_revA2.sh
bash tools/export_fab_revA2.sh
```

ERC 0/0；DRC 12/108/59、一致性 0；结构检查为 PASS_WITH_PCB_AND_PHYSICAL_TEST_GATES，Rev.A1 哈希未变；15 测试通过；shell 语法通过；实际导出脚本 **exit 2 并打印 REFUSING**，没有生产 Gerber/钻孔/CPL。本次增强导出门控：先 ERC，再包含一致性的 DRC；未来 BOM 使用官方 CSV 导出且失败不再被 `|| true` 吞掉。通过导出仍不等于 FAB_RELEASED，须完成独立查看和 3D 审查。

本机 DRC 最初在沙箱中 SIGABRT；崩溃栈为 macOS `_RegisterApplication`/wx 调用。经受控沙箱外运行同一官方 CLI 后得到报告；不是 KiCad 对板文件“通过”或“失败”的替代判断。Fontconfig 版本警告另保留在日志，未改系统设置。

## 固件与改动文件

固件详见 `../../firmware/mcu/VERIFICATION_20260923_CN.md`，含实际 ARM 构建失败、16 个 C 单元检查、4 条已说明 MMIO 静态分析警告、15 个 native 模拟测试及其边界。仍是代码骨架与宿主机可编译逻辑，缺 ARM 工具链、startup/linker/时钟树/HAL；没有可烧录发行包、没有板上运行结论。主机完整 autotune 仍缺 scipy，异步日志重采样/真实时基/回绕/实物标定仍未完成。

本轮改动入口：

- PCB/原理图/库：`smart_apo_common_revA2.kicad_pcb`、`.kicad_sch`、新 `SmartApoRevA2.pretty/LGA-14_3x2.5mm_P0.5mm_LSM6DSO.kicad_mod`；删除现用目录中的旧错误尺寸 mod，备份保留。
- 工程证据：官方 ERC/DRC 两种报告、netlist、validation_report；本文件、来源文档、README/放行清单/历史检查点/挪位清单及 CONTEXT_HANDOFF 的最新状态说明。
- 工具：`tools/validate_revA2.py`、`tools/export_fab_revA2.sh`、`tools/generate_revA2.py`（新封装引用并修正既有 CT05 str.replace 第三参数类型错误；**未运行生成器**）。
- 固件：`firmware/mcu/Makefile`，`include/{board_revA2,app,datalog,flash,sensors}.h`，`src/{board,app,datalog,flash,sensors}.c`，README、SENSOR_CTRL_INIT、验证报告、`tests/` 和 `validation/`；`firmware/host/dump_decode.py`、README 及 `tests/`。
- 可回退检查点和分类清单：`validation/revA2_20260923/`。

不要重新运行 `generate_pcb_revA2.py`、`route_explicit_revA2.py` 或旧挪位脚本覆盖本板；生成器的历史布局不是当前已审核局部修改的输入源。

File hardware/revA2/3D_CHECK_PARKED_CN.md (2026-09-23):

# Rev.A2 当前3D状态

最新审查件为validation/revA2_review_bundle/REVIEW_ONLY_INCOMPLETE.step，输入PCB SHA256 `6399dd180a5b50c9931cfed0662c3caf641f06213e151ca5037d261392fa9602`，已包括D1旋转修复。官方导出exit0；文件哈希/模型清单见该目录manifest.json和model_inventory.json。

43封装中35个模型引用可解析，J1/J2/J3/U2/U3/U5/SW1未绑定，Y1路径不可解析。没有准确Rev.A2壳体/完整实购物料模型，没有独立查看器及碰撞检查通过。通用模型存在不等于采购后缀/高度匹配。

其余旧STEP为历史，不再视为当前板。当前仍NOT_FAB_RELEASED，完整门槛见DELIVERY_GATES_CURRENT_CN.md。

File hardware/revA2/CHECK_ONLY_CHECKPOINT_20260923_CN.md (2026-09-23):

# 官方检查与制造导出分离 · 2026-09-23

新增 `bash tools/export_fab_revA2.sh --check-only`。它执行完全相同的官方ERC、DRC及原理图一致性门禁：失败保留非零退出；通过则退出0，但在任何mkdir/rm/导出调用前结束，不创建、不清空、不改写制造目录。检查通过也输出NOT_FAB_RELEASED提醒，其含义只是该脚本没有完成其余放行门槛。

不带参数的既有行为保持：电气门禁通过后导出候选Gerber/钻孔/CPL/BOM；仍不设置FAB_RELEASED。新增--help及参数校验，未知/多余参数在调用KiCad前退出64。没有放宽原有任何拦截条件。

## 实际验证

- `bash -n tools/export_fab_revA2.sh`：通过。
- `python3 -m unittest discover -s tools/tests -p 'test_export_fab_revA2.py' -v`：5个测试方法通过，覆盖clean check-only、ERC警告拦截、DRC错误、开路、一致性问题、工具失败、无参旧行为、无效参数/帮助。测试在临时项目中使用假CLI，只验证脚本编排，不能当作PCB验证。
- `bash tools/export_fab_revA2.sh --check-only`：实际KiCad10.0.6 ERC0违规，普通DRC错误0、1未连接（MOSI）、110警告，返回2。制造目录前后均不存在，散列/存在性核查确认没有制造文件被修改。证据validation/revA2_check_only/{tests.log,official_checks.log,verification.json}。

改动：tools/export_fab_revA2.sh；新增tools/tests/test_export_fab_revA2.py。未改PCB、原理图或固件源代码，没有新依赖。

后续MOSI闭合及丝印处理阶段使用--check-only，待用户要求的警告、制造和机械门槛审核完成后再运行无参导出；不把只检查模式的exit0当作生产放行。

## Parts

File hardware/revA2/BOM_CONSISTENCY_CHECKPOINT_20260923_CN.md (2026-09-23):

# 工作BOM跨文件一致性检查 · 2026-09-23

本阶段不修改PCB、原理图或固件。板SHA256 `5d1f8a7a330c3bbbf86d8e15930d2b26694e2a207ddf2a994f410223839efa94`保持；此前官方ERC0/0、DRC0错误/0未连/3项courtyard仍适用于同一板。NOT_FAB_RELEASED。

## 已修正的工作BOM差异

- C7原列在1µF组，正式原理图/PCB/网表为100nF。拆为独立100nF X7R行，AWA0、UNDERWATER1；1µF组变为C6/C9/C10，AWA2、UNDERWATER3。
- C11/C12工作BOM历史标注0603，正式设计为0402；纠正封装引用并明确4.7µF有效容量/充电稳定性仍未由准确MPN证明。
- 全部BOM封装字段使用正式网表的完整库ID，包括已修正的U2几何、U1/D1项目变体及其余项目封装，消除简写/过期名称歧义。
- 不改变设计器件值、板上封装尺寸、数量或装配变体；只是工作BOM与当前正式设计一致。

新增`tools/check_bom_revA2.py`读取工作BOM、ASSEMBLY_VARIANTS_revA2.csv、官方网表：检查唯一位号与43器件覆盖、阻容标称值、完整Footprint ID、Population与变体状态、分组数量。MANUAL/PCB_ONLY计数表示存在的线焊接口/PCB焊盘组，不是应采购的SMT连接器数量。该工具不验证供应商编号、准确MPN适配、容差、电压/温度降容或极性。

## 实际命令及结果

```sh
python3 tools/check_bom_revA2.py --output validation/revA2_bom_audit/consistency.json
python3 -m unittest discover -s tools/tests -v
```

一致性PASS_DESIGN_CONSISTENCY_ONLY，43/43、issues为空。15项工具测试通过，其中新增6项覆盖当前数据以及C7错误值、C11/C12错误封装、错误变体数量、重复/缺失位号、Population冲突的拒绝。旧工作BOM回放检测到44条不一致（多数为简写封装ID，并非44个电路错误），包括C7实际值差异。未重复运行无改动的PCB/ERC或固件测试。

改动文件：BOM_revA2_WORKING.csv、tools/check_bom_revA2.py、tools/tests/test_check_bom_revA2.py及本报告/交接入口。证据目录含BOM_before/after.csv、before_consistency.json、consistency.json（输入哈希）、tests.log。未输出最终生产BOM/CPL或Gerber。

## 仍开放的采购阻塞

- U5工作BOM LCSC列C97522，但备注另列C5334276，不能将两者当已确认相同采购项；下单前需要所购/批准目录项与W25Q256JVEIQ核对。
- Q1仍有2N7002/DMN1019USN-7替代选择；D1无准确MPN、极性/光学规格未闭合。
- SW1所购CT05图纸、Y1准确晶体CL/驱动规格、C15/C16匹配仍开放。
- C9/C10、C11/C12等MLCC的准确MPN与有效容量未闭合；纠正0402字段不证明0402的4.7µF能满足稳压/充电条件。
- 401020保护电芯规格/允许充电电流、Pogo/线焊实际占用、核心采购后缀、壳体与3D、ARM链接器/运行库及样机仍缺。

下一步继续核对极性与实际采购输入，保持装配及制造放行门槛。

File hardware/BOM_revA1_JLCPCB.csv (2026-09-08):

Comment | Designator | Footprint | LCSC Part # | Manufacturer Part | AWA Qty | UNDERWATER Qty | Assembly | Notes
MCU | U1 | TSSOP-20_4.4x6.5mm_P0.65 | C529334 | STM32G031F8P6 | 1 | 1 | SMT | 64KB Flash / 8KB RAM; stock must be rechecked at order
6-axis IMU | U2 | LGA-14_2.5x3.0mm_P0.5 | C2655100 | LSM6DSOTR | 1 | 1 | SMT | Do not substitute without pin/driver review
Water-resistant pressure sensor | U3 | CCLGA-7_2.8x2.8mm | C3263277 | LPS28DFWTR | 1 | 1 | SMT | Critical; footprint must be checked against ST TN0018
24-bit bridge ADC | U4 | SOIC-16_3.9x9.9mm_P1.27 | C5180029 | NAU7802SGI | 0 | 1 | SMT | AVDD 3.0V; 320SPS; six-wire bridge
256Mbit SPI NOR | U5 | WSON-8_6x8mm_P1.27 | C97522 | W25Q256JVEIQ | 1 | 1 | SMT | Alternate C5334276 only after package check
Li-ion charger | U6 | SOT-23-5 | C424093 | MCP73831T-2ACI/OT | 1 | 1 | SMT | 4.2V version; R3=20k gives nominal 50mA
3.3V LDO | U7 | SOT-23-5 | C2887324 | TPS7A0233PDBVR | 1 | 1 | SMT | Alternate C5142805 TPS7A0233DBVR after review
N-MOSFET | Q1 | SOT-23 |  | 2N7002 or DMN1019USN-7 | 1 | 0 | SMT | Lock JLC part during order
Red LED | D1 | LED_0805 |  | High-bright red 0805 | 1 | 0 | SMT | Optically couple to float light pipe
Battery pads | J1 | 2-pad custom |  | BATTERY_WIRE_PADS | 1 | 1 | Manual | Protected 401020 LiPo 60-80mAh
Debug/charge pads | J2 | POGO_7x1.27mm |  | SWD_UART_CHARGE_POGO | 1 | 1 | PCB | No connector populated
Bridge pads | J3 | PAD_6x1.27mm |  | FULL_BRIDGE_6WIRE | 0 | 1 | Manual | E+/E-/S+/S-/A+/A-
Reed switch | SW1 | SMT reed 5mm |  | Normally-open SMT reed | 1 | 1 | SMT | Wake input only; not in battery current path
32.768kHz crystal | Y1 | 2012-2P |  | 32.768kHz 12.5pF | 1 | 1 | SMT | Frequency tolerance <=20ppm preferred
4.7k 1% | R1 R2 | 0402 |  | Generic thick film | 2 | 2 | SMT | I2C pullups
20k 1% | R3 | 0402 |  | Generic thick film | 1 | 1 | SMT | Charge-program resistor
1M 1% | R4 | 0402 |  | Generic thick film | 1 | 1 | SMT | Battery divider upper
330k 1% | R5 | 0402 |  | Generic thick film | 1 | 1 | SMT | Battery divider lower
68R 1% | R6 | 0402 |  | Generic thick film | 1 | 0 | SMT | LED series
100k 1% | R7 | 0402 |  | Generic thick film | 1 | 0 | SMT | MOS gate pulldown
100R 0.1% | R8 R9 | 0402 |  | Low-TCR precision resistor | 0 | 2 | SMT | Bridge differential input pair; same lot
100k 1% | R10 | 0402 |  | Generic thick film | 1 | 1 | SMT | Reed pullup
10k 1% | R11 | 0402 |  | Generic thick film | 1 | 1 | SMT | NRST pullup
100nF X7R | C1 C2 C3 C4 C5 C8 C14 C17 | 0402 |  | Generic MLCC | 8 | 8 | SMT | Rated >=10V
1uF X5R | C6 C7 C9 C10 | 0402 |  | Generic MLCC | 2 | 4 | SMT | C6/C7 are underwater-only
4.7uF X5R | C11 C12 | 0603 |  | Generic MLCC | 2 | 2 | SMT | Rated >=10V
10nF C0G | C13 | 0402 |  | Generic MLCC | 0 | 1 | SMT | Bridge differential filter
8.2pF C0G | C15 C16 | 0402 |  | Generic MLCC | 2 | 2 | SMT | Recalculate after crystal CL/parasitics review

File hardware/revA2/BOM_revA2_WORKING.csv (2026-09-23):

Comment | Designator | Footprint | LCSC Part # | Manufacturer Part | AWA Qty | UNDERWATER Qty | Assembly | Notes
MCU | U1 | SmartApoRevA2:TSSOP-20_4.4x6.5mm_P0.65mm_RevA2_Pin1 | C529334 | STM32G031F8P6 | 1 | 1 | SMT | 64KB Flash / 8KB RAM; stock must be rechecked at order
6-axis IMU | U2 | SmartApoRevA2:LGA-14_3x2.5mm_P0.5mm_LSM6DSO | C2655100 | LSM6DSOTR | 1 | 1 | SMT | Do not substitute without pin/driver review
Water-resistant pressure sensor | U3 | SmartApoRevA2:LPS28DFW_CCLGA-7L | C3263277 | LPS28DFWTR | 1 | 1 | SMT | Critical; footprint must be checked against ST TN0018
24-bit bridge ADC | U4 | Package_SO:SOIC-16_3.9x9.9mm_P1.27mm | C5180029 | NAU7802SGI | 0 | 1 | SMT | AVDD 3.0V; 320SPS; six-wire bridge
256Mbit SPI NOR | U5 | SmartApoRevA2:WSON-8_W25Q256JV_8x6mm_AN0000009 | C97522 | W25Q256JVEIQ | 1 | 1 | SMT | Winbond AN0000009 p21 PCB land; C5334276 catalog MPN matches; incoming lot and carrier remain unverified
Li-ion charger | U6 | Package_TO_SOT_SMD:SOT-23-5 | C424093 | MCP73831T-2ACI/OT | 1 | 1 | SMT | 4.2V version; R3=20k gives nominal 50mA
3.3V LDO | U7 | Package_TO_SOT_SMD:SOT-23-5 | C2887324 | TPS7A0233PDBVR | 1 | 1 | SMT | Alternate C5142805 TPS7A0233DBVR after review
N-MOSFET | Q1 | Package_TO_SOT_SMD:SOT-23 |  | 2N7002 or DMN1019USN-7 | 1 | 0 | SMT | Lock JLC part during order
Red LED | D1 | SmartApoRevA2:LED_0805_2012Metric_RevA2_K1 |  | High-bright red 0805 | 1 | 0 | SMT | Optically couple to float light pipe
Battery pads | J1 | SmartApoRevA2:BATTERY_WIRE_PADS |  | BATTERY_WIRE_PADS | 1 | 1 | Manual | Protected 401020 LiPo 60-80mAh
Debug/charge pads | J2 | SmartApoRevA2:POGO_7x1.27mm |  | SWD_UART_CHARGE_POGO | 1 | 1 | PCB | No connector populated
Bridge pads | J3 | SmartApoRevA2:PAD_6x1.27mm |  | FULL_BRIDGE_6WIRE | 0 | 1 | Manual | E+/E-/S+/S-/A+/A-
Reed switch | SW1 | SmartApoRevA2:REED_CT05_COMPACT |  | Normally-open SMT reed | 1 | 1 | SMT | Wake input only; not in battery current path
32.768kHz crystal | Y1 | Crystal:Crystal_SMD_2012-2Pin_2.0x1.2mm |  | 32.768kHz 12.5pF | 1 | 1 | SMT | Frequency tolerance <=20ppm preferred
4.7k 1% | R1 R2 | Resistor_SMD:R_0402_1005Metric |  | Generic thick film | 2 | 2 | SMT | I2C pullups
20k 1% | R3 | Resistor_SMD:R_0402_1005Metric |  | Generic thick film | 1 | 1 | SMT | Charge-program resistor
180k 1% | R4 | Resistor_SMD:R_0402_1005Metric |  | Generic thick film | 1 | 1 | SMT | Battery divider upper
60.4k 1% | R5 | Resistor_SMD:R_0402_1005Metric |  | Generic thick film | 1 | 1 | SMT | Battery divider lower
68R 1% | R6 | Resistor_SMD:R_0402_1005Metric |  | Generic thick film | 1 | 0 | SMT | LED series
100k 1% | R7 | Resistor_SMD:R_0402_1005Metric |  | Generic thick film | 1 | 0 | SMT | MOS gate pulldown
100R 0.1% | R8 R9 | Resistor_SMD:R_0402_1005Metric |  | Low-TCR precision resistor | 0 | 2 | SMT | Bridge differential input pair; same lot
100k 1% | R10 | Resistor_SMD:R_0402_1005Metric |  | Generic thick film | 1 | 1 | SMT | Reed pullup
10k 1% | R11 | Resistor_SMD:R_0402_1005Metric |  | Generic thick film | 1 | 1 | SMT | NRST pullup
10k 1% | R12 | Resistor_SMD:R_0402_1005Metric |  | Generic thick film | 1 | 1 | SMT | W25Q256 /CS reset-state pullup
100nF X7R | C1 C2 C3 C4 C5 C8 C14 C17 | Capacitor_SMD:C_0402_1005Metric |  | Generic MLCC | 8 | 8 | SMT | Rated >=10V; C14 tolerance <=20% (startup RC guard)
100nF X7R | C7 | Capacitor_SMD:C_0402_1005Metric |  | Generic MLCC | 0 | 1 | SMT | Underwater-only; matches formal schematic/PCB 100n; exact MPN and tolerance remain open
1uF X5R | C6 C9 C10 | Capacitor_SMD:C_0402_1005Metric |  | Generic MLCC | 2 | 3 | SMT | C6 underwater-only; C9/C10 common; effective capacitance under bias/temperature requires exact MPN review
4.7uF X5R | C11 C12 | Capacitor_SMD:C_0402_1005Metric |  | Generic MLCC | 2 | 2 | SMT | Rated >=10V; actual PCB is 0402, not historical 0603; exact MPN/effective capacity and charge/LDO stability remain unverified
10nF C0G | C13 | Capacitor_SMD:C_0402_1005Metric |  | Generic MLCC | 0 | 1 | SMT | Bridge differential filter
8.2pF C0G | C15 C16 | Capacitor_SMD:C_0402_1005Metric |  | Generic MLCC | 2 | 2 | SMT | Recalculate after crystal CL/parasitics review

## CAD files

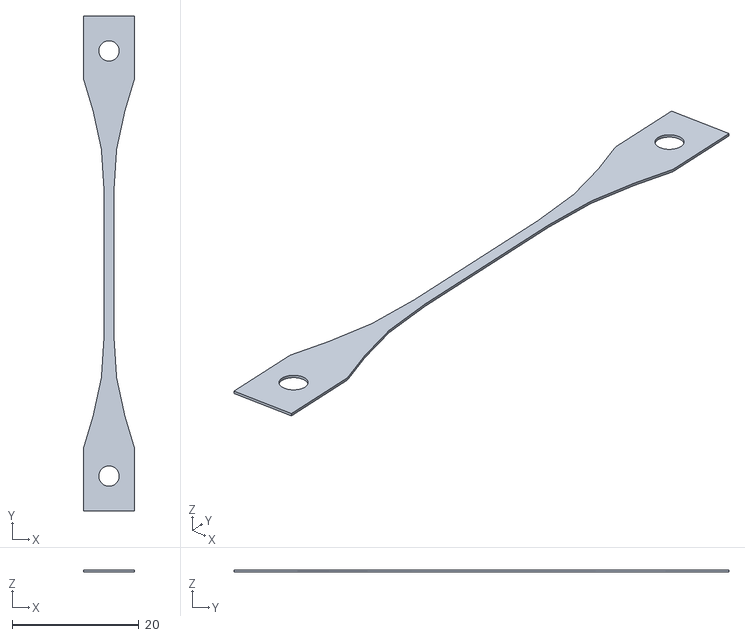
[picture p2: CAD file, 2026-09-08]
mechanical/316L_flexure_preview_NOT_FOR_PRINTING.stl
8.00 x 78.0 x 0.3

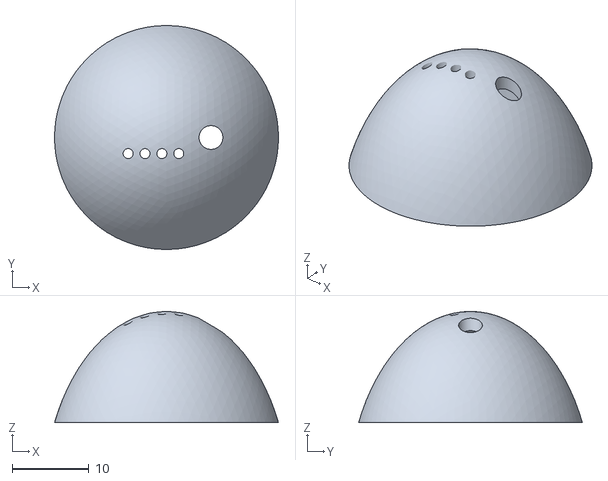
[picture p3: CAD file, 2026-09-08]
mechanical/awa_cap_revA.stl
29.2 x 29.2 x 14.5

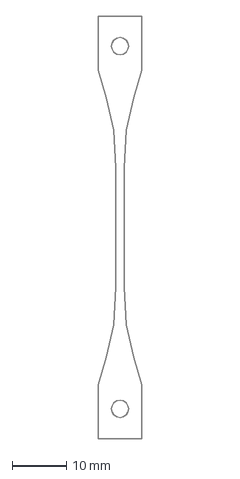
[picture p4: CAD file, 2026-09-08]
mechanical/316L_flexure_0p30mm_revA.dxf
8.00 x 78.0 mm

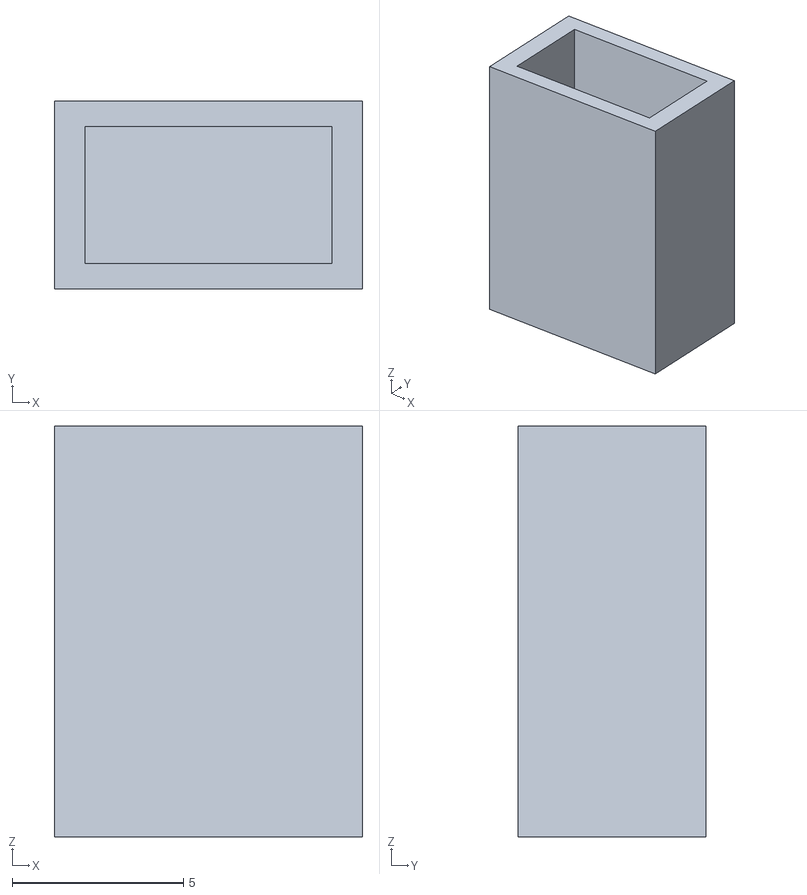
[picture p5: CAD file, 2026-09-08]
mechanical/underwater_ballast_cassette_revA.stl
9.00 x 5.50 x 12.0

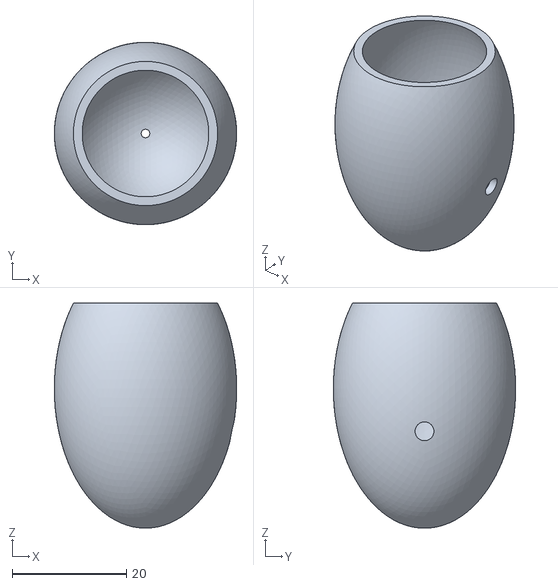
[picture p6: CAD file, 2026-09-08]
mechanical/awa_body_32x49_revA.stl
32.0 x 32.0 x 39.5

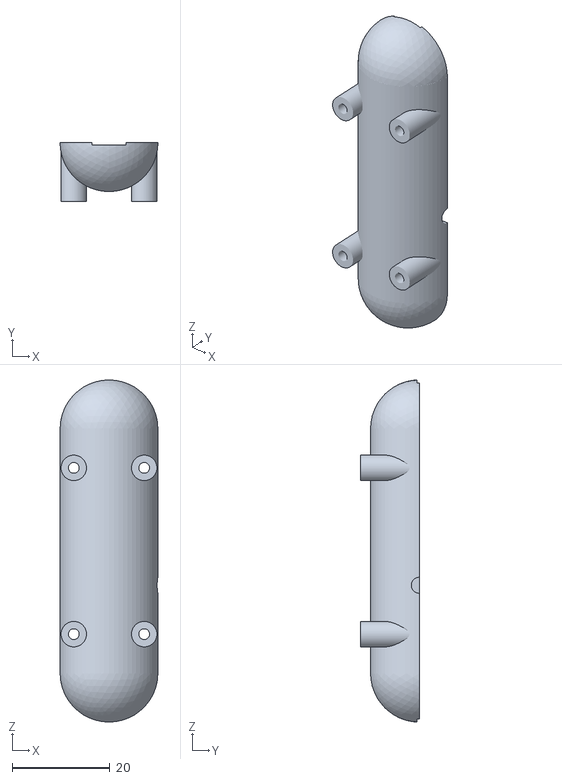
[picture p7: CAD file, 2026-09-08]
mechanical/underwater_fairing_half_A_revA.stl
20.0 x 12.0 x 69.9

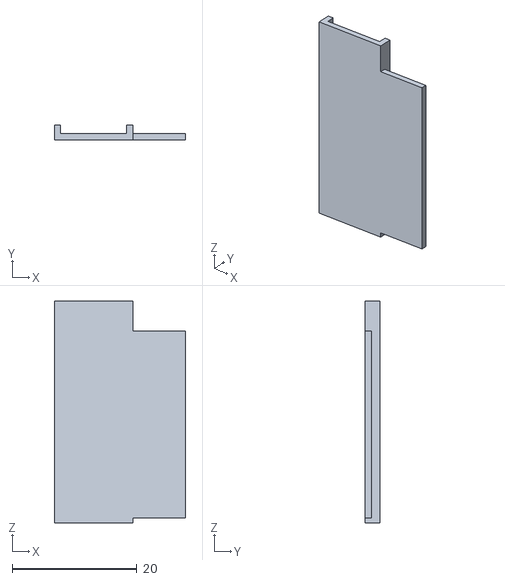
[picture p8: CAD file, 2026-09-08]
mechanical/awa_electronics_sled_revA.stl
21.1 x 2.40 x 35.6

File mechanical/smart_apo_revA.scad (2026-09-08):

// Smart Awa + Smart Underwater Rev.A — authoritative parametric geometry
// Units: millimetres.  STL files in this package were independently generated
// and watertight-checked.  Use $fn=128 for final export.
$fn = 96;

part = "awa_body"; // awa_body, awa_cap, awa_sled, uw_A, uw_B, uw_ballast, flexure

awa_d = 32;
awa_h = 49;
awa_split_z = 15;
awa_wall = 1.4;
pcb_w = 12;
pcb_l = 35;
uw_d = 20;
uw_total_l = 70;
uw_straight_l = 50;

module ellipsoid(rx, ry, rz) { scale([rx,ry,rz]) sphere(1); }

module awa_outer() { ellipsoid(awa_d/2, awa_d/2, awa_h/2); }

module awa_body() {
  difference() {
    intersection() { awa_outer(); translate([-25,-25,-35]) cube([50,50,50]); }
    intersection() {
      translate([0,0,0.2]) ellipsoid(14.6,14.6,22.8);
      translate([-20,-20,-25]) cube([40,40,45]);
    }
    cylinder(h=60,r=0.75,center=true);                    // 316L wire/eye spine
    translate([12,0,-7.5]) rotate([0,90,0]) cylinder(h=12,r=1.65,center=true); // pressure port
  }
}

module awa_cap() {
  difference() {
    union() {
      intersection() { awa_outer(); translate([-25,-25,10]) cube([50,50,20]); }
      difference() {
        translate([0,0,14]) cylinder(h=4,r=11.55,center=true);
        translate([0,0,14]) cylinder(h=6,r=9.55,center=true);
      }
    }
    intersection() {
      translate([0,0,0.2]) ellipsoid(14.6,14.6,22.8);
      translate([-20,-20,7.5]) cube([40,40,16]);
    }
    cylinder(h=35,r=0.75,center=true);
    translate([5.8,0,19]) cylinder(h=20,r=1.55,center=true); // light pipe
    for (x=[-5,-2.8,-0.6,1.6]) translate([x,-2.1,19]) cylinder(h=20,r=0.65,center=true);
  }
}

module awa_sled() {
  union() {
    translate([-4.2,0,-1.5]) cube([12.6,1,35.6],center=true);
    translate([-10,0.7,-1.5]) cube([1,2.4,35.6],center=true);
    translate([1.6,0.7,-1.5]) cube([1,2.4,35.6],center=true);
    translate([5.8,0,-3.5]) cube([9.5,1,30],center=true);
  }
}

module capsule(r=10, straight=50) {
  union() {
    cylinder(h=straight,r=r,center=true);
    translate([0,0,straight/2]) sphere(r);
    translate([0,0,-straight/2]) sphere(r);
  }
}

module uw_shell() {
  difference() {
    union() {
      capsule(uw_d/2,uw_straight_l);
      for (x=[-7.2,7.2], z=[-17,17])
        translate([x,0,z]) rotate([90,0,0]) cylinder(h=24,r=2.6,center=true);
    }
    cube([13.2,8,43],center=true);                         // electronics cavity
    cube([7,1,76],center=true);                            // 316L beam slot
    translate([8,0,-7]) rotate([0,90,0]) cylinder(h=10,r=1.65,center=true);
    for (x=[-7.2,7.2], z=[-17,17])
      translate([x,0,z]) rotate([90,0,0]) cylinder(h=28,r=1.1,center=true);
  }
}

module uw_half(sign=1) {
  intersection() {
    uw_shell();
    translate([0,sign*25.01,0]) cube([50,50,90],center=true);
  }
}

module uw_ballast() {
  translate([0,0,-14]) difference() {
    cube([9,5.5,12],center=true);
    translate([0,0,0.8]) cube([7.2,4,10.5],center=true);
  }
}

module flexure_316L() {
  // Preview only. Manufacture from the DXF in 0.30 mm 316L sheet.
  difference() {
    linear_extrude(0.30) polygon([
      [-4,-39],[4,-39],[4,-29],[2.5,-24],[1.2,-18],[0.75,-11],
      [0.75,11],[1.2,18],[2.5,24],[4,29],[4,39],[-4,39],
      [-4,29],[-2.5,24],[-1.2,18],[-0.75,11],[-0.75,-11],
      [-1.2,-18],[-2.5,-24],[-4,-29]
    ]);
    for (y=[-33.5,33.5]) translate([0,y,-0.2]) cylinder(h=1,r=1.6);
  }
}

if (part=="awa_body") awa_body();
else if (part=="awa_cap") awa_cap();
else if (part=="awa_sled") awa_sled();
else if (part=="uw_A") uw_half(-1);
else if (part=="uw_B") uw_half(1);
else if (part=="uw_ballast") uw_ballast();
else if (part=="flexure") flexure_316L();

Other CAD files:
mechanical/underwater_fairing_half_B_revA.stl

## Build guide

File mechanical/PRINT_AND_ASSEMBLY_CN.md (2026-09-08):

# 打印与装配说明

## 打印建议

| 零件 | 推荐工艺 | 层高 | 壁/填充 | 备注 |
|---|---|---:|---|---|
| 阿波壳体、上盖 | PA12 MJF/SLS；次选韧性 SLA | 0.08–0.12 mm | 实体壳 | FDM 仅用于尺寸试装，不用于下水密封 |
| 水中件两半壳 | PA12 MJF；次选韧性 SLA | 0.08–0.12 mm | 实体壳 | 接合面打印后研磨至平面 |
| 电子仓托架、配重盒 | PA12/SLA/FDM 均可 | 0.12–0.20 mm | ≥60% | 不属于压力壳 |

STL 尺寸单位均为 mm。先打印 100% 比例试装，不要让切片软件自动缩放。

## 阿波装配

1. 将 1.0–1.2 mm 316L 轴向钢丝/端眼穿过极点孔，钢丝与壳体之间留出环氧胶结合长度。
2. PCB 固定在托架左侧，30–60 mAh 保护型 LiPo 固定在另一侧；压力传感器帽对准侧面 Ø3.3 mm 压力口。
3. 压力口采用传感器原厂推荐 O 形圈结构或低模量硅胶隔离，禁止用硬环氧直接压在 MEMS 帽上。
4. 上盖四个小孔供临时湿式触点/灌封触点，Ø3.1 mm 孔供 LED 光导。盐水试验前用硅胶塞保护触点。
5. 完成上电、下载和零偏检查后再封盖。Rev.A 可采用薄 O 形圈加环氧二次密封；首次下水不超过 0.5 m、30 min。

## 水中件装配

1. 316L 梁置于中央 7 × 1 mm 槽内，梁两端孔连接钓线，外壳不得同时夹死梁的两个受力端。
2. 四片 350 Ω 应变片组成全桥，布线使用柔软漆包线，先涂应变片防水保护层，再做整机封装。
3. 两半壳结合面使用 0.5 mm 激光切割硅胶垫或低模量密封胶；四颗 M2×16 316L 螺钉仅压紧壳体。
4. 电子仓与梁之间使用软硅胶定位，避免硬胶把应变绕过敏感段传入壳体。
5. 完成装配后称重。海水目标总质量为 23.294 g；淡水目标为 22.797 g。用配重盒加入钨泥/316L 小片，最后以实测悬浮差校准。

## 密封升级顺序

水槽 0.5 m → 2 m 静压桶 → 目标使用深度的 1.5 倍保压 2 h。每级结束后称重，吸水增重超过 0.05 g 即判失败。

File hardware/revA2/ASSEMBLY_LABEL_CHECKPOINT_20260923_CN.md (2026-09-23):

# 装配位号覆盖检查点 · 2026-09-23

正式PCB SHA256 `5c6c6cb8134fcbc620c9eb22a98f85be26f280167b6e134c9233ffcfd164d30d`。官方ERC0错误/0警告、DRC0错误/0未连接/0一致性问题、50警告；NOT_FAB_RELEASED。

U2/U3/SW1/J1/J2/J3缺少Fab `${REFERENCE}`，此次在器件原点补充0.8mm字高/0.12mm笔画标识，保持各自正反面及镜像方向，并同步六个项目封装库。现在43个封装各有一个Fab位号，现有37个标识未改变。PCB除了新增六个Fab文本外内容一致（仅归一化空白），每个库除了一个Fab文本外一致；原理图/项目逐字节一致。制造层丝印、铜、焊盘、走线、规则均未改变。

修改PCB及项目库：PAD_6x1.27mm、LPS28DFW_CCLGA-7L、LGA-14_3x2.5mm_P0.5mm_LSM6DSO、REED_CT05_COMPACT、POGO_7x1.27mm、BATTERY_WIRE_PADS；完整相对路径在证据adopted_files.json。另刷新官方/离线报告和交接入口。

实际工具：

- KiCad内置Python运行`validation/revA2_assembly_labels/inspect.py`、`edit.py`，清点43个封装并在独立副本补齐；首次LIB_ID Format调用不兼容已修正后重跑，失败不计通过。
- `kicad-cli pcb drc --format json --severity-all --units mm --refill-zones --schematic-parity -o validation/revA2_assembly_labels/candidate/drc_revA2_kicad10.json validation/revA2_assembly_labels/candidate/smart_apo_common_revA2.kicad_pcb`：0错误/0未连/50警告；每项type/UUID集合与基线完全相同。
- `python3 validation/revA2_assembly_labels/verify.py`：六项Fab增量、既有内容/库增量/DRC集合检查通过。
- 官方`pcb export pdf`分别输出F.Fab/Edge.Cuts与B.Fab/Edge.Cuts，后者镜像，均exclude-value、scale5；Poppler渲染并查看。front_REVIEW.pdf与back_REVIEW.pdf的新增标识均可辨认。
- 正式采用后`bash tools/export_fab_revA2.sh --check-only`：exit0，官方ERC/DRC上述结果。
- `python3 tools/validate_revA2.py`：exit0，Rev.A1哈希保持，fab_export不存在。

证据`validation/revA2_assembly_labels/`包括baseline/candidate/final、before/after_inventory.json、invariants.json、正反面PDF/PNG、review_manifest.json、官方日志及50项OPEN队列。固件未改未重测。

这次只关闭装配位号缺失。图中原位标签能定位此前不印刷丝印的五个器件，但尚未完成装配变体、所有针脚/极性、实购物料与完整工艺标注核验；不能将位号覆盖当成装配放行或机械干涉通过。仍须处理18项丝印重叠/29项压铜/3项缺courtyard，以及采购、板厂、当前3D、最终ELF和板上验证。

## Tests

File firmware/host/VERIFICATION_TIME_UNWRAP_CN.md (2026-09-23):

# 长航次时间展开验证（2026-09-23）

## 改动与回退

- `dump_decode.py`：新增 opt-in 时间展开；要求明确声明单次不重启采集及最大样本间隔，保持严格序号/CRC/缺测/变体门槛。
- `tests/test_decode_safety.py`：新增 6 项自动回归测试。
- `README_CN.md`：增加使用契约及不能从 UART v1 推断的情况。
- 修改前副本：`firmware/host/checkpoints/time_unwrap_before/` 中同名三文件。未修改 MCU 或 PCB。

## 实际执行

仓库根目录执行：

```text
python3 -m unittest discover -s firmware/host/tests -v
修改前：Ran 17 tests in 11.125s / OK
修改后：Ran 23 tests in 5.630s / OK

python3 -m py_compile firmware/host/dump_decode.py firmware/host/tests/test_decode_safety.py
exit 0
```

新增测试验证：

1. `0xfffffff0 → 16 → 48` 正常展开为 `4294967280 → 4294967312 → 4294967344`，同时允许 seq `65535 → 0 → 1`，原始样本不变。
2. 重复时间、后退时间、等于/超过半周期和超过声明上限时拒绝。
3. 缺失/零/负数/半周期/非整数上限，或未选择展开却传上限时拒绝。
4. 开启展开仍拒绝内部 CRC 错误、外层 CRC 丢帧造成的序号缺口、缺测通道及变体冲突。
5. 14 条间隔 10^9 us 的模拟记录累计到 13×10^9 us，跨多次回绕正确。
6. 实际 subprocess CLI：默认拒绝回绕；缺少上限/上限过小拒绝并保留已有目标；明确上限后成功导出。

## 验证边界

这是宿主 Python 及已有 C 模拟回归证据，不是 ARM 构建或实物运行证据。没有添加依赖，也未改变传输格式。

UART v1 没有 boot ID、航次头或 64 位时钟。复位若恰好产生可接受的小正模增量、超整周期停顿或丢失 65536 倍数条记录，不能从当前载荷可靠识别。必须有外部采集记录支持不中断/间隔声明，否则只保留 raw。正常小幅后退或超上限能被拒绝，不代表任意复位已被检测。

时间展开不补缺测，不插值，不证明异步通道同时有效。异步日志重采样、校准、ARM/HAL 及板上验证继续保持开放。

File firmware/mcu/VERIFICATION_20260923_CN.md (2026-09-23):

# Rev.A2 固件实际验证记录（2026-09-23）

状态：**代码骨架；宿主机 C 检查/模拟接口测试通过；ARM 可启动构建未完成；板上运行未验证。** 未生成可烧录发行包。

## 已修复

- `include/sensors.h` 的宏后多余 `*/` 导致 app/main/sensors 全部无法通过 C 预处理；已删除。
- `Makefile` 中 `CC ?=` 被 GNU make 内置 `CC=cc` 覆盖，原来误调用 Apple clang 并报 Cortex-M0+ 不支持。仅在默认来源时指定 ARM 编译器，仍尊重用户显式 CC。
- `include/board_revA2.h` / `src/board.c`：RCC APBENR2 地址由 `0x4002104C` 更正为 `0x40021040`；原地址是 APBSMENR1，不能完成预期的 SYSCFG/SPI1 时钟使能。实际指针复用头文件常量，减少重复。依据 [ST 官方 STM32G031 CMSIS 头文件 RCC_TypeDef](https://raw.githubusercontent.com/STMicroelectronics/cmsis-device-g0/master/Include/stm32g031xx.h)，APBENR2 offset=0x40，APBSMENR1 offset=0x4C（本次在线读取）。此文档校核不等于寄存器实测。
- `src/datalog.c`：JEDEC/读取失败拒写；重启检测到已有 APO2 航次则只读，未知/损坏头拒写。保留 RAM 页和被拒样本；禁止日志地址越过 32 MiB；append 在隐式刷新后再次检查容量，满盘拒绝 RAM 尾写入，由 app 保留未接受样本。`src/flash.c` 检查全页空白、WEL、写后读回；已写入完全相同数据的重试仅确认，半写页拒绝重新编程。不提供擦除/历史航次自动复用。
- `src/app.c`：新增 APP_ERROR 与粘滞错误位；init/append/flush/read 失败传播，日志异常停止采样。全航次按页检查样本 CRC 并转储，包含 RAM 尾和未成功 append 样本；UART 失败缓存同一记录重试。host 去除连续完全相同帧。移除前三个调度点伪造同步敲击标记。
- 新增 native C 模拟夹具 `tests/{log_lifecycle,log_capacity,flash_nor,app_errors,sensors_config}.c`，由无第三方依赖的 `firmware/host/tests/test_firmware_contract.py` 编译运行，保留原有未提交文件，不改 Rev.A1。

## 实际工具证据

完整命令/退出码/stdout/stderr：`validation/commands_20260923.json`。测试原始输出：`validation/native_tests_20260923.log`。

| 实际命令 | 结果及边界 |
|---|---|
| `python3 -m unittest discover -s firmware/host/tests -v` | 15 个测试通过；测试内部使用 clang 编译执行模拟接口，另对 8 个 C 源文件、两个装配变体运行 `-std=c11 -Wall -Wextra -Werror -fsyntax-only` |
| `make -C firmware/mcu` | exit 2：`arm-none-eabi-gcc` 不在 PATH；未声称 ARM 构建通过 |
| `python3 firmware/host/dump_decode.py firmware/host/example_data/uart_dump_fixture.bin -o firmware/mcu/validation/uart_fixture_raw.csv` | exit 0，解码 1 条现有夹具；另测试直接生成真实 C 打包帧，验证 Python 解码、负数、小端、外层 CRC 破损重同步及截断帧 |
| `clang --analyze ...`（具体 16 条见 JSON） | 全部退出 0；board.c 在两个变体各有 2 个 `core.FixedAddressDereference` 警告，为实际 MMIO 地址访问。其余无诊断。不能把 exit 0 写成零警告 |
| 默认 `python3 firmware/host/autotune.py ...` | exit 1，缺 numpy |
| App bundled Python 执行同一 autotune | exit 1，numpy 可用但缺 scipy；未安装新依赖，未改写现有示例结果 |

测试覆盖：UART C→Python 协议；Flash 越界先于 SPI 拒绝；Flash 探测/读取失败不写；满页失败不溢出、重试地址及数据保留；模拟 NOR 的重启存储逐字节不变、WEL 拒绝、半写/占用页拒写、写后读回、同数据响应丢失重试；跨部分页的全航次+RAM尾、样本CRC损坏；DUMP 同记录重试和重新进入、错误状态停止采样；不伪造同步事件；ST RCC 地址契约。没有在宿主机执行 board.c 的 MMIO 初始化。

引脚头文件与 `hardware/revA2/STM32G031_TSSOP20_PIN_REVIEW_CN.md` 的 20 脚表对应：PB6/PB7 AF6 I2C，PA2/PA3 AF1 USART2，PA5/6/7 AF0 SPI1，PA4 CS，PA9/10 remap 后磁簧/DRDY，PA13/14 保持 SWD。该结论是文件交叉检查；CubeMX/芯片验证仍开放。

## 剩余阻塞与后续优先级

1. **非可启动固件**：未找到 ARM 工具链；`/Applications` 未找到 CubeMX。缺 startup/vector、linker script、时钟树/HAL 或完整 LL 驱动。现 Makefile 即使补工具链也不构成经过验证的可启动映像。GPIO/总线/ADC/LSE/Stop 大多数函数仍只有注释与失败返回；禁止烧录骨架。
2. **日志保护已实现软件模拟，仍需实物验证**：保持原 APO2 16-byte header / 34-byte sample / FF 页填充；已有航次一律只读，缺可用空白页拒写，未提供多航次目录、用户确认擦除或自动续写。断电损坏样本会明确报错，不跳过伪装成功；复杂损坏的原始存储抢救尚未实现。完整空白页作为顺序日志终点，不扫描任意稀疏历史片段。当前方案优先保护存量数据，不宣称断电自动恢复全部记录。
3. **全航次读取/错误传播已通过模拟验证**：增加 READ4=0x13、逐页 CRC、RAM 尾、UART 单记录重试、APP_ERROR/错误位。仍未传输航次头/设备ID/量程元数据；主机需显式选择 awa/uw。无主机 ACK、持久化确认或端到端完成帧，不把 UART 成功等同于主机已保存。实际 SPI/UART 尚无 HAL 驱动。READ4 依据 [Winbond W25Q256JV Rev.Q §8.2.11（TI 托管原厂 PDF）](https://e2e.ti.com/cfs-file/__key/communityserver-discussions-components-files/908/W25Q256JV-SPI-RevQ-02072025-Plus.pdf)：始终使用 4 字节地址；BUSY 时不读取，代码先轮询。
4. **定时与同步（软件未完成）**：main 使用循环自增伪时间；sensors deadline 比较没有 uint32 回绕处理（约 71.6 min），1 ms 步长不保证 104/208/320 Hz。尚无真实敲击检测/事件输入；标志保持未置位。
5. **主机数据安全门槛已实现，重采样未实现**：raw 保留原始计数/flags；`--autotune` 逐条拒绝缺测，要求 AWA IMU/PRESS 有效、UW 再加 STRAIN；拒绝 AWA 携带 strain-valid、样本内 CRC 错误、非递增时间戳及 sequence 缺口/乱序（允许正常 16 位回绕）。外 CRC 丢弃中间帧后不会静默输出缺失航次。UW 必须提供有限非零梁标定斜率及显式有限零点，不能把 counts 命名 gf。拒绝时不覆盖输出 CSV。当前异步 MCU 日志需要明确定义重采样后才可进入调参；时间戳回绕展开、头部变体/量程自动验证仍未实现。
6. **传感器寄存器补充模拟验证**：依据 [ST 官方 lsm6dso_reg.h](https://raw.githubusercontent.com/STMicroelectronics/lsm6dso-pid/master/lsm6dso_reg.h) 将 CTRL3_C 配成 BDU|IF_INC=`0x44`；依据 [ST 官方 lsm6dso_reg.c](https://raw.githubusercontent.com/STMicroelectronics/lsm6dso-pid/master/lsm6dso_reg.c) 修正 host 敏感度为 0.000122 g/LSB 和 0.0175 dps/LSB（原 500/32768 错误）。依据 [Nuvoton NAU7802 V1.7 原厂表](https://www.nuvoton.com/resource-files/NAU7802%20Data%20Sheet%20V1.7.pdf) 增加 PUR 有限轮询、CTRL2.CALS 内部 offset 校准并检查 CAL_ERR、PU_CTRL.CR 门控新转换。两变体模拟测试覆盖 BDU 实际写值、AWA 不访问 DNP NAU、校准失败/超时/未就绪不置有效位。NAU 和 Flash 仍使用限次数轮询，需真实毫秒时基；没有板上回读证据。内部 offset 不代表 gf 梁标定通过。
7. **设备条件**：需样机、调试器、串口/逻辑分析仪，验证 remap、总线、寄存器回读、Flash 完整性、LSE 失败降级、磁簧唤醒、ADC、高阻分压采样误差和梁标定。当前没有任何板上验证通过结论。
8. **主机调参运行依赖**：已检查 `.pydeps`，含 numpy 2.5.2 的 cp312 扩展、不含 scipy；默认 Python3.14 ABI 不兼容，但 App bundled Python3.12 实际可导入该 numpy。系统 Python3.9、KiCad Python3.9、bundled Python3.12 的 scipy 均缺失。完整探测见 `validation/python_dependencies_20260923.json`；本次未安装依赖，未运行通过 autotune，未更新候选参数，仍需 scipy 环境和真实独立航次。

不影响硬件放行状态：保持 NOT_FAB_RELEASED，由主任务官方 ERC/DRC 决定 PCB 数字检查结果。

末轮独立审查修复证据：`log_capacity.c` 实际模拟填满 131072 页/917504 条记录，额外追加触发最终页刷新后被拒绝，重复追加仍拒绝且不增加编程次数。主机回归人为破坏中间帧外 CRC，raw 恢复序号 0、2，严格调参拒绝该缺口，并单独证明 65535→0 连续回绕可通过。

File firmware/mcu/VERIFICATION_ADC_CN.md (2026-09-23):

> 启动保护已补充：TIM2开机epoch前100ms拒绝采样、不阻塞、不改输出。BOM增加C14容差≤20%设计条件；RC/温度/时钟裕量计算见 `validation/revA2_divider/consistency.json` 的 `startup_RC`。模型覆盖门槛前后与后续回绕；不是运行中电压阶跃/实物精度验证。

# STM32G031 PA1 ADC1_IN1 验证（2026-09-23）

已实现真实寄存器单次采样后端；返回实际 ADC_DR 的 12 位原始码。仅模型、宿主回归和 ARM 目标文件通过；**没有最终 ELF、烧录或板上成功声明，分压阻抗已作设计修正，但电池毫伏精度尚未实测成立。**

## 实现与边界

- PA1 改为模拟、无上下拉；只读改写 GPIOA MODER/PUPDR 中 PA1 字段。SWD PA13/14、其他GPIO、remap、TIM2/SPI/UART/I2C实现均未改动。
- 每次读独占 ADC1：使能时钟、ADC局部reset、禁IRQ/DMA/连续/外部触发/过采样，固定序列仅IN1、12位右对齐。仅接受HSI16 /1、AHB/APB /1，并检查HSIRDY及微调不变；同步HCLK/4，标称ADC 4 MHz。不改变系统时钟树或异步ADC时钟选择。
- 使用现有 `board_time_us` 测量稳压器启动30 us（官方要求20 us，留HSI与整数计时裕量），校准完成后2 us（官方要求2 ADC周期）。TIM2须先经 `board_start_clocks` 初始化；时基不可用、停止或Stop唤醒后失败，不以空循环伪造延时。TIM2的HSI与时间契约同时适用。
- 等待CHSELR更新CCRDY；启动ADCAL，等待ADCAL清零且EOCAL置位，再清陈旧标志，设置ADEN，等待ADRDY，软件ADSTART。等待EOC和EOS同时成立、ADSTART结束后才读DR。拒绝OVR、配置/时钟漂移及大于4095的DR；任何失败不改调用者输出。NULL立即失败。
- 每段轮询最多4096次，延时段也有相同次数上限；这是终止保证，不是精确墙钟timeout。成功和失败都仅reset ADC取消残留操作/关闭模拟稳压器；下一次调用必须重新校准，没有跨Stop沿用就绪状态。ADC时钟保持使能。要求串行独占ADC，无ISR/DMA/并发RCC或GPIO写者。
- 最大160.5周期采样，在4 MHz下标称40.125 us；12位转换另需12.5周期。返回0表示观察到硬件转换完成和格式正确，不表示模拟误差合格，也不表示电池电压已校准。

## 模拟硬件阻塞条件

初始R4=1 MΩ、R5=330 kΩ，等效源阻抗约248.1 kΩ，超出DS12992 Rev4表59的50 kΩ条件。后续已改为R4=180 kΩ、R5=60.4 kΩ、1%，最坏Rth=45.677 kΩ，关闭该阻抗数值超限；其余误差没有因此验证通过。分压在4.2 V下静态电流17.471 µA，仅此支路30天约12.579 mAh（恒压假设，不是整机续航）。

固件名义换算现为 `adc * 132220 / 41223`，4095码中间乘积不溢出32位。新增宿主机双变体测试逐一检查4096个码与独立物理分压有理数结果，并验证超量程钳位。跨文件证据见 `validation/revA2_divider/consistency.json`。C14名义100nF与新Rth时间常数4.522ms，全阶跃至半个12位LSB约40.75ms；电容偏压/容差、输入漏电、参考电压、上电建立与温度仍须验证，最长ADC采样时间不能代替这些检查。

既有 `board_vbat_mv_from_adc` 仍按VREF+=3.3 V及名义分压比计算。TSSOP20参考连接需按封装电源核对并测量实际VDDA/VREF+；本实现不读取VREFINT校正，不提供12位绝对电压精度承诺。PA1必须始终处于VSSA..VREF+输入范围，检查掉电时电池分压反灌、输入漏电、去耦及建立时间。未测板上ADC码、精度、功耗、启动延迟或SWD保持。

## 官方依据（实际读取）

- [ST STM32G031 CMSIS器件头](https://raw.githubusercontent.com/STMicroelectronics/cmsis-device-g0/master/Include/stm32g031xx.h)：ADC地址0x40012400、寄存器偏移、ADCEN/ADCRST位20及状态/控制字段。
- [ST ADC LL头](https://raw.githubusercontent.com/STMicroelectronics/stm32g0xx-hal-driver/master/Inc/stm32g0xx_ll_adc.h)：同步HCLK/4、160.5周期、CCRDY要求、20 us稳压启动、校准后2 ADC周期及CR命令位语义。
- [ST ADC HAL实现](https://raw.githubusercontent.com/STMicroelectronics/stm32g0xx-hal-driver/master/Src/stm32g0xx_hal_adc.c)：核心/转换时钟、单次采样流程及ADC局部reset清理。
- [DS12992 Rev4，2025-06](https://www.st.com/resource/en/datasheet/stm32g031f8.pdf)：引脚/封装连接、表59/60模拟输入条件。未声称完整核读RM0444。

## 验证与复现

从仓库根目录运行：

```sh
python3 -m unittest discover -s firmware/host/tests -v
python3 -m unittest discover -s firmware/mcu/tests -v
make -C firmware/mcu objects-both CC=/opt/homebrew/opt/llvm/bin/clang BUILD=validation/adc/arm
/opt/homebrew/opt/llvm/bin/clang --analyze --target=arm-none-eabi -mcpu=cortex-m0plus -mthumb -std=c11 -ffreestanding -I firmware/mcu/include -I firmware/mcu/runtime/include firmware/mcu/src/board.c -o firmware/mcu/validation/adc/board.plist
```

host 23/23；MCU 5/5（原有runtime/TIM2/SPI/UART四项加ADC），寄存器模型各跑AWA/UW。ADC模型地址白名单，W1C、reset、校准命令完成、ADEN/ADSTART、DR读清EOC；断言稳压和校准后最小延时、校准先于转换、端点0/4095及中间码、重复调用重校准、TIM2回绕、GPIO/RCC非目标位保留。注入校准卡住、ADRDY缺失、转换超时、OVR、时钟丢失、格式改变、微调漂移、CCRDY缺失、计时失败/停滞、DR越界、ADSTART卡住、EOCAL缺失、EOS缺失、ADSTP异常15类故障；均不改输出且下一次显式调用重新初始化可恢复。另测5类初始时钟错误与NULL。

LLVM AWA/UW各10个对象，经 `-Wall -Wextra -Werror`。`validation/adc/objects.json` 保存ELF32 little-endian ARM REL检查与SHA256；静态分析无诊断。日志为 `validation/adc/{host-tests,mcu-tests,arm-objects,static-analysis}.log` 和 `board.plist`。该模型不能替代真实ADC数字时序/模拟电路仿真，也不能证明板上轮询余量。

修改：`src/board.c` ADC函数与专用helpers、`include/board_revA2.h` ADC契约、`tests/adc_registers.c`、`tests/test_adc.py`、本报告及 `validation/adc/`。未加依赖、安装工具或提交。最终链接器/compiler runtime、阻抗数值已修正；参考电压、静态电流预算及实物验证仍未完成。

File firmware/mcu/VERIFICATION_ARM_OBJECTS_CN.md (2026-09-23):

# ARM 构建基础验证（2026-09-23）

## 结论与状态边界

已从“仅宿主语法/模拟回归”推进到 **AWA/UW 两变体真实 Cortex-M0+ ARM 目标文件可编译**。每变体 10 个 ELF32 little-endian `ET_REL` / `EM_ARM` 文件，共 20 个；`-Wall -Wextra -Werror` 编译退出 0。**未产出已链接固件 ELF，不可烧录，不是发行固件，不代表 HAL 或板上运行通过。**

已有 Clang 23.1.0 可用；PATH 无 arm-none-eabi-gcc、arm-none-eabi-ld、ld.lld、rust-lld、rustc、zig。扫描 `/Applications`、`/Library/Developer`、`/usr/local`、`/opt/homebrew`、`~/.codex` 未找到相应 ELF linker 或 ARM compiler-rt/libgcc；`~/.rustup` 不存在。未安装依赖。

## 本次文件与设计

- `Makefile`：保留默认 GNU ARM 编译入口，新增显式 LLVM cross-compile、两变体独立输出、object-only 目标、依赖跟踪、启动/链接基础。原文件备份 `validation/arm_20260923/Makefile.before`。
- `runtime/include/string.h` / `runtime/string.c`：当前源码所需 memcpy/memset/memcmp 的真实逐字节实现，使用编译器提供的 `stddef.h`，无假 typedef、无空实现；`-fno-builtin` 防止编译器将自身循环重新转成库调用。
- `runtime/startup.c`：独立实现 .data 复制、.bss 清零、进入 main、意外中断默认停驻；47 项向量顺序对应 ST G031 模板。只保留 reset 时钟状态，不声称替代 SystemInit/HAL，不支持 C++ 静态构造。
- `runtime/stm32g031f8.ld`：Flash 0x08000000/64 KiB，RAM 0x20000000/8 KiB，MSP 候选 0x20002000；保留 2 KiB 栈与向量大小断言。**因 linker 不存在，地址放置、容量断言、load/run 地址及栈预算尚未通过实际链接验证。**
- `tests/test_runtime.py`：宿主执行真实 string runtime，覆盖零长度、1/3/4/7/34/255/256/513 字节、非对齐地址、目标前后 guard、填充截断和 unsigned 比较。1 项参数化回归通过；不是 MCU 指令运行测试。
- `tests/verify_arm_objects.py`：读取每个目标文件 ELF header 并用 llvm-nm 核对跨目标文件符号；防止把宿主 object 或未解析依赖称为发行 ELF。

未修改既有 `src/`、`include/`、host 或传感器算法。

## 实际命令与证据

在仓库根目录运行：

```sh
make -C firmware/mcu objects-both CC=/opt/homebrew/opt/llvm/bin/clang
python3 firmware/mcu/tests/verify_arm_objects.py /opt/homebrew/opt/llvm/bin/llvm-nm
python3 -m unittest discover -s firmware/mcu/tests -v
make -C firmware/mcu all CC=/opt/homebrew/opt/llvm/bin/clang VARIANT=0
make -C firmware/mcu all CC=/opt/homebrew/opt/llvm/bin/clang VARIANT=1
```

前三项退出 0；后两项退出 2，实际报错 `invalid linker name in argument '-fuse-ld=lld'`。日志保存在 `validation/arm_20260923/`：`build-objects.log`、`object-audit.json`、`runtime-tests.log`、`link-variant0.log`、`link-variant1.log`。

`llvm-readelf -h/-S/-A/-s` 检查全部 20 个目标文件，完整结果分别为 `elf-headers.txt`、`sections.txt`、`attributes.txt`、`symbols.txt`。startup 的 `.isr_vector` 长度 0xBC（188 字节）、对齐 256；`vector-relocations.txt` 显示首项 `_estack`、第二项 Thumb `Reset_Handler`，EXTI0_1/EXTI4_15/SysTick 等顺序对应官方表。目标文件中这些是重定位关系，**不是已确认的最终向量地址**。

用 llvm-nm 将所有对象定义符号与引用符号做集合核对，两个变体残留完全相同：

- 编译器运行时：`__aeabi_uidiv`、`__aeabi_lmul`、`__aeabi_uldivmod`。
- linker 应提供的边界：`_ebss`、`_edata`、`_estack`、`_sbss`、`_sdata`、`_sidata`。

memcpy/memset/memcmp 已由本项目 runtime 定义，未用虚假 stub 隐藏符号。Arithmetic AEABI 没有自行伪造；需对应 ARM compiler-rt 或 libgcc。只有 linker 仍不足以消除这一阻断。

## 官方依据

- [ST DS12992 Rev 4](https://www.st.com/resource/en/datasheet/stm32g031k8.pdf)：STM32G031F8 的 64 KiB Flash、8 KiB SRAM。
- [ST CMSIS G031 设备头](https://github.com/STMicroelectronics/cmsis-device-g0/blob/master/Include/stm32g031xx.h)：FLASH_BASE/SRAM_BASE，内存地址。
- [ST G031 GCC startup](https://github.com/STMicroelectronics/cmsis-device-g0/blob/master/Source/Templates/gcc/startup_stm32g031xx.s)：异常/IRQ 顺序与保留槽。本地未复制 ST 代码，仅按硬件表独立实现。

## 尚未关闭

1. 提供 ARM ELF linker 及适配 Cortex-M0+ 的 compiler runtime 后，实际链接两个变体，再验证 entry、vector、LOAD sections、Flash/RAM/栈余量和零 undefined。
2. CubeMX/官方时钟配置、完整 GPIO/总线/ADC/时基/Stop 驱动仍缺。当前 `board_time_us()` 失败闭合，不能记录真实采样。
3. 没有模拟器/实物上的复位、异常入口、栈深度、外设通信或 Flash 运行证据；不得把 object 编译改写成“可启动”或“板上运行通过”。

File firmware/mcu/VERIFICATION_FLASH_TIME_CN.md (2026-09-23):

# Flash BUSY 实时时限验证（2026-09-23）

已移除32次状态轮询作为页编程超时的做法，改用现有 TIM2 `board_time_us()` 的5000µs预算；连续4096次时间不前进终止，属于故障防停滞上限。未增加依赖、提交、链接最终ELF或烧录；以下不是板上成功证明。

## 原厂依据

实际下载的 [Winbond W25Q256JV SPI Rev R PDF](https://www.winbond.com/resource-files/W25Q256JV%20SPI%20RevR%2005042026%20Plus.pdf)，内页发布日期 May 6, 2026，§9.7 印刷页84（PDF第85页）：tPP典型0.4ms、最大3ms。5000µs预算包含2000µs裕量，仅服务页编程等待，不覆盖扇区/整片擦除。不能将别的版本或其他料号参数混用。

原始PDF及该页文本保存在 `validation/flash_time/W25Q256JV_RevR.pdf`、`datasheet-timing.txt`。下载链起于 Winbond 官方文档库的 W25Q256JV SPI Data Sheet，下载页解析出的resource-files地址即上述链接。

## 修复及边界

- 每次读状态都结束CS事务；等待计时包含SPI状态读取时间。首次已ready允许只读恢复，即使TIM2无效；首次BUSY必须有有效时基才能继续，不以CPU循环假装微秒。
- 一旦观察BUSY，后续状态ready也需有效时间，超过5000µs不接受ready。恰在5000µs观察ready可成功，恰在5000µs仍BUSY失败。无符号时间差支持一次32位自然回绕；倒退或大跳变失败。
- 真正PP之前采集时基、WREN、验证WEL，再采集时基并验证实际进展与预算。无时基或停滞不得授权新写。返回0仍要求读回一致；已经匹配的数据可幂等确认，无需重新PP。
- 继续拒绝已占/半写页，没有隐藏program重试。失败可能已编程，调用者不能把失败当作未发生写入；显式重试先读回，半写页仍拒绝。
- CS断言失败也调用释放；传输/状态读取/时间故障路径均结束事务。物理CS损坏不可能由软件证明释放，测试证明的是release调用及模型中的非选中状态。
- 依赖SPI与TIM2 API自身的有界失败、独占同步调用。时间预算不是线程调度/异常中断下的硬实时保证，长暂停或坏时间戳会保守失败。停滞上限不是正常页编程期限。

## 先复现，再验证

修改前快照在 `validation/flash_time/baseline/`。`baseline/flash_nor_reproduction.c` 建立状态模型：每次RDSR推进10µs，PP保持BUSY 1000µs；原32轮代码在合法1ms编程尚未结束时失败。`before.log` 保存该成功预期断言的失败（exit=-6）。修复后同一情形完成100轮以上状态查询并读回成功。

专用 `tests/flash_time_cases.h` 由现有 `flash_nor.c` 运行，覆盖3ms、4990/5000/5010µs、BUSY后6000µs才采到ready拒绝、UINT32回绕、首次/等待中时基失败、倒退、永久BUSY、停滞、SPI错误、CS失败、PP后失时基以及显式重试只读确认。原有WEL拒绝、NOR按位写、读回失配、断写、已占页、重复确认断言保留。新增ready且无TIM2可读、BUSY且无TIM2失败、无TIM2不发PP断言。

验证命令（仓库根）：

```sh
python3 -m unittest discover -s firmware/host/tests -v
python3 -m unittest discover -s firmware/mcu/tests -v
make -C firmware/mcu objects-both CC=/opt/homebrew/opt/llvm/bin/clang BUILD=validation/flash_time/arm
```

host 23/23、MCU 8/8通过。20个AWA/UW Cortex-M0+目标对象在 `-Wall -Wextra -Werror` 下编译，并独立检查ELF32 little-endian ARM REL头、保存SHA256；LLVM 23.1现有工具链，无安装。Flash两个变体clang静态分析均无诊断。具体命令、日志和对象清单为 `validation/flash_time/{host-tests.log,mcu-tests.log,arm-objects.log,static-analysis.json,objects.json}`；`source-hashes.json`记录本轮源码快照哈希。

修改文件：`src/flash.c`、`include/board_revA2.h`仅FLASH_BUSY常量、`tests/flash_nor.c`、新增`tests/flash_time_cases.h`；host `test_flash_bounds_reject_before_spi`只加入时间mock及CS释放对应调用数1→2。未修改其他测试。

仍需板上验证：实际SPI/CS时序、温压边界tPP、TIM2/SPI失钟、断电半写、长航次页持久化，以及真实硬件下的超时裕量。尚未建立最终ELF或板上证据。

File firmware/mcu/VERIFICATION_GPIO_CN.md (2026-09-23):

# STM32G031 GPIO / 磁簧轮询验证（2026-09-23）

已实现真实 GPIO 寄存器初始化和 IDR 读取；磁簧连续闭合用 TIM2 微秒计时并轮询 EXTI9 释放边沿。这里只证明宿主状态模型、回归和 ARM 目标文件通过；没有最终 ELF、烧录、实物电平/功耗或 Stop 唤醒成功声明。

## 实现契约

- `board_enable_syscfg` 仅置 RCC_APBENR2 SYSCFGEN 并读回；`board_apply_pa9_pa10_remap` 必须看到该时钟使能才置 CFGR1 的 PA11_RMP/PA12_RMP。其余 RCC/SYSCFG 位保留。
- `board_init_gpio` 仅使能 GPIOA/B。先写 BSRR 将 PA4 输出锁存器置高、PB0 置低，再设置推挽、低速、无上下拉、输出模式。先预载避免由输入切换至输出时误选 FLASH 或点亮 LED。输出初始化即使 remap 缺失仍先执行；PA0/9/10 的输入配置必须在 remap 成功后进行，外部已有驱动/上拉，不加内部拉电阻。所有寄存器按目标字段读改写，保留 SWD PA13/14、AFR、其他 GPIO 和 RCC 位。
- PA9 读取实际 IDR，低为闭合；PA0 读取实际 IDR，高为 IMU pending。输入 API 检查 GPIO 时钟、SYSCFG/remap、输入模式和 pull 配置，未初始化/漂移返回假。PA10 配置成输入，但本轮不新增 strain IRQ API。
- `board_reed_exti_setup` 独占 EXTI9：选择 PA、仅上升沿（释放）触发，IMR9/EMR9 都屏蔽，以 W1C 清本线 pending，保留其他线路。它只是硬件释放边沿锁存器的轮询初始化，不启用 NVIC 或 ISR，不构成 Stop 唤醒。现有 startup 的 EXTI handler 仍是 Default_Handler 弱别名，不能启用中断。
- `board_reed_held_for_sleep` 从第一次闭合观察开始计时，至少标称 1,500,000 us 才为真。IDR 观察到松开会清零；即使两次调用之间开闭，EXTI9 上升 pending 也会清零，下一次闭合调用重新开始计时。清 pending 后不复用清除前的时间戳，避免将释放前时间计入新的闭合。计时后再次查 IDR/pending，避免调用内松开被认作合格。时钟 API 失败、时间停滞/反向或间隔超过 INT32_MAX、配置失效也清零。32 位计时回绕和长闭合跨多次回绕均受模型覆盖。必须至少每 INT32_MAX us 调用一次；无并发 GPIO/EXTI/RCC 写者或其他 pending 清除者。
- `board_imu_int_exti_setup` 明确保留空兼容入口；IMU 是即时电平轮询，短脉冲可能漏检，不是事件队列。既有基于时间的传感器采样路径仍需保留。LED 仅有启动 PB0 低电平，闪烁控制仍未实现。

1.5 秒基于现有 TIM2/HSI 的标称时间及其容差，并非独立校准的绝对时长。EXTI 捕获只能保证满足芯片电气/脉宽要求且被硬件捕获的边沿；无法证明任意短毛刺都捕获。模式配置瞬时变更后在调用间恢复、其他代码清 pending 等情况不在独占契约内。物理拉电阻、焊接、逻辑阈值、机械抖动与长期时基精度须板上确认。

## 官方依据（实际读取）

- [ST STM32G031 CMSIS 器件头](https://raw.githubusercontent.com/STMicroelectronics/cmsis-device-g0/master/Include/stm32g031xx.h)：GPIO/EXTI 地址和偏移，SYSCFG remap bit3/4，EXTICR3 EXTI9 三位字段在 bit8，RPR/FPR 与 IMR/EMR。
- [ST GPIO LL](https://raw.githubusercontent.com/STMicroelectronics/stm32g0xx-hal-driver/master/Inc/stm32g0xx_ll_gpio.h)：输入/输出模式、IDR 输入读取、BSRR 原子置位/复位。
- [ST EXTI LL](https://raw.githubusercontent.com/STMicroelectronics/stm32g0xx-hal-driver/master/Inc/stm32g0xx_ll_exti.h)：独立 trigger、interrupt/event mask、rising/falling pending 和 W1C 清除。未声称完整核读 RM0444。

## 验证证据与复现

```sh
python3 -m unittest discover -s firmware/host/tests -v
python3 -m unittest discover -s firmware/mcu/tests -v
make -C firmware/mcu objects-both CC=/opt/homebrew/opt/llvm/bin/clang BUILD=validation/gpio/arm
/opt/homebrew/opt/llvm/bin/clang --analyze --target=arm-none-eabi -mcpu=cortex-m0plus -mthumb -std=c11 -ffreestanding -I firmware/mcu/include -I firmware/mcu/runtime/include firmware/mcu/src/board.c -o firmware/mcu/validation/gpio/board.plist
```

host 23/23，MCU 7/7（原六项加 GPIO）通过。GPIO 模型各编译运行 AWA/UW 两变体，真实后端经宏 hook 操作独立状态模型；地址白名单拒绝未建模访问，BSRR 改输出锁存器、pending 为 W1C。断言 latch-before-mode、SYSCFG-before-remap、remap-before-input、GPIO/SWD 与 EXTI 非目标位保留、低有效/高有效 IDR、阈值前一微秒/正好阈值、两次轮询间释放、调用内释放、计时回绕、多次完整计数周期。注入 GPIO 时钟使能写丢失、remap 写丢失、MODER 写丢失、计时失败/停滞/反向及七类配置漂移。没有用固定成功返回模拟硬件行为。

LLVM AWA/UW 各 10 个 ARM 对象通过 `-Wall -Wextra -Werror`，`validation/gpio/objects.json` 记录各对象 ELF32 little-endian ARM REL 检查及 SHA256；静态分析无诊断。日志见 `validation/gpio/{host-tests,mcu-tests,arm-objects,static-analysis}.log`。没有安装依赖或提交。

修改范围：`src/board.c` 的 GPIO/SYSCFG/remap/磁簧/IMU 函数及局部 helpers；`include/board_revA2.h` GPIO 契约；`tests/gpio_registers.c`、`tests/test_gpio.py`；本报告和 `validation/gpio/`。未改 TIM2/SPI/UART/ADC/I2C 生产后端。分压硬件与换算由同任务其他工作流处理，不属于本 GPIO 验证结论。

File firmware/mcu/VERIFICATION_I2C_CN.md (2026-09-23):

# STM32G031 I2C1 PB6/PB7 验证（2026-09-23）

已替换 I2C 桩为寄存器轮询后端，现有 LSM6DSO、LPS28DFW、NAU7802 驱动直接调用这些接口。模型和编译通过不等于器件应答或板上时序合格；没有最终 ELF、烧录、示波器或传感器成功声明。

## 实现契约

- 独占单主机 I2C1，PB6=SCL、PB7=SDA、AF6、开漏、低速GPIO、无内部上下拉，需要外部上拉。只修改这两个引脚字段、I2C1时钟/reset/CCIPR字段；保留其他GPIO/RCC位，不更改系统时钟树、remap、SWD、TIM2/SPI/UART/ADC实现。
- 仅接受已验证 HSI16 /1、AHB/APB /1；I2C1SEL=00选择PCLK。每次事务等待检查 RCC、微调、PE、TIMINGR、滤波/控制、GPIO配置，拒绝漂移。关闭从机地址、IRQ/DMA、SMBus超时；模拟滤波开、DNF=0。初始化局部reset I2C1。
- 参数地址为未左移的7位地址；写时SADD=addr7<<1、NBYTES=2、AUTOEND，逐次TXIS写寄存器号和实际值。读先NBYTES=1写寄存器号、不AUTOEND，TC后重复START读、AUTOEND；读取实际RXDR。支持1..255字节，不做RELOAD；当前驱动最大14字节。
- 成功要求STOPF且BUSY清零，随后清STOPCF/CR2。允许最后字节RXNE与STOPF同时出现。读用255字节局部暂存，整个事务成功才复制，任何失败不改调用者缓冲区；错误没有补零或伪造有效数据。增加的栈开销须在最终链接/实际栈水位验证时评估。
- NACK/BERR/ARLO/OVR/PECERR/TIMEOUT/ALERT均使当前事务失败。只有纯NACK且STOP已完成、BUSY清零、配置仍有效才保留总线就绪，因此缺装一个器件不阻止探测其他地址。无透明重试，部分写可能已生效。
- 硬错误、异常STOP、BUSY卡住、超时、配置改变均失效，需显式init/recover。只有本次已START且仍持有总线时请求STOP；ARLO不发STOP、不自动GPIO恢复，避免干扰其他主机。STOP收尾失败不递归重试；显式恢复才产生恢复时钟。与旧桩注释不同：不在任意超时后盲目产生GPIO脉冲。
- 正常事务等待及SCL拉伸有TIM2名义25ms与4096次双上限；STOP错误收尾最多4096次。循环上限可能早于25ms，是有限终止保证，未证明板上最坏执行时延或支持25ms拉伸。所有延时使用`board_time_us`，不以CPU空循环作微秒延时；依赖其时钟/回绕/Stop失效契约。
- 显式恢复关闭PE后释放PB6/PB7，开漏GPIO读取IDR确认SCL真的变高，才计6us高电平；低电平亦6us。SDA低时最多9个恢复脉冲，再在SCL低时拉低SDA、释放SCL并等拉伸结束、释放SDA产生STOP（STOP过程额外一个SCL低/高转换）。不把输出锁存“高”误当总线“高”。确认两线高才回AF6/PE；失败保持PE=0并释放开漏引脚，可能保持GPIO模式。
- 初始化也需要工作TIM2。现有Stop唤醒使TIM2时基失效，所以不能宣称Stop后I2C已恢复；需要完整低功耗时基设计后验证。并发ISR/DMA、其他主机及外部GPIO/RCC改写不在支持范围。

## TIMINGR依据及条件

`0x10A2272F`是本轮手算的保守标准模式候选，**不是CubeMX结果或RM0444表格的直接复制**。PRESC=1、SCLDEL=10、SDADEL=2、SCLH=39、SCLL=47。在16MHz时，tPRESC=125ns，数据建立延时1375ns、保持延时250ns，SCL高/低计数部分为5000/6000ns；同步、滤波、边沿会再增加周期，因此不是精确100kHz，名义常落在约80–90kHz范围。

计算依据为[ST AN4235的时序公式](https://www.st.com/resource/en/application_note/an4235-i2c-timing-configuration-tool-for-stm32f3xxxx-and-stm32f0xxxx-microcontrollers-stmicroelectronics.pdf)，以及[ST官方BSP的SDADEL/SCLDEL计算式](https://raw.githubusercontent.com/STMicroelectronics/stm32wba55g-dk1-bsp/main/stm32wba55g_discovery_bus.c)。AN4235针对F0/F3，BSP针对WBA，这里只引用相同TIMINGR字段的计算方法，不把其时钟树或示例常数当G031配置。

计算假设：SDA/SCL上升≤1000ns，下降≤300ns，模拟滤波50..260ns、DNF=0。G031滤波范围来自[DS12992 Rev4表69](https://www.st.com/resource/en/datasheet/stm32g031y8.pdf)。`validation/i2c/check_timing.py`额外检查15.2/16/16.8MHz（人为±5%计算裕量，不是HSI校准测量）：SCLDEL时间≥1250ns；SDADEL在`max(0,tf-50-3*tclk)`到`3450-tr-260-4*tclk`之间；高低计数自身已超过标准模式要求，最快总计数周期也超过10us。结果存`timing.json`。实际边沿、上拉/总线电容、电压温度与HSI误差须上板测量并按实测重新核算；不据此关闭硬件发布门禁。

寄存器地址、偏移和位域核读[ST G031 CMSIS头](https://raw.githubusercontent.com/STMicroelectronics/cmsis-device-g0/master/Include/stm32g031xx.h)；控制/清标志、PE关闭与滤波语义核读[ST G0 LL I2C头](https://raw.githubusercontent.com/STMicroelectronics/stm32g0xx-hal-driver/master/Inc/stm32g0xx_ll_i2c.h)，事务流程参考[ST G0 HAL I2C](https://raw.githubusercontent.com/STMicroelectronics/stm32g0xx-hal-driver/master/Src/stm32g0xx_hal_i2c.c)。[RM0444](https://www.st.com/resource/en/reference_manual/rm0444-stm32g0x1-advanced-armbased-32bit-mcus-stmicroelectronics.pdf)正文提取未成功，不声称完整核读该手册。

## 验证及复现

```sh
python3 -m unittest discover -s firmware/host/tests -v
python3 -m unittest discover -s firmware/mcu/tests -v
make -C firmware/mcu objects-both CC=/opt/homebrew/opt/llvm/bin/clang BUILD=validation/i2c/arm
/opt/homebrew/opt/llvm/bin/clang --analyze --target=arm-none-eabi -mcpu=cortex-m0plus -mthumb -std=c11 -ffreestanding -I firmware/mcu/include -I firmware/mcu/runtime/include firmware/mcu/src/board.c -o firmware/mcu/validation/i2c/board.plist
python3 firmware/mcu/validation/i2c/check_timing.py
```

Host 23/23；MCU原有5项加I2C共6/6，均覆盖AWA/UW。新模型具有地址白名单、CR2 START自清、TC/STOP和AUTOEND序列、TXDR消耗TXIS、RXDR清RXNE、ICR W1C、reset和GPIO BSRR/IDR分离等副作用，不是只固定返回成功位。覆盖1..14/255字节、真实接收图样、寄存器与地址编码、重复START、最终RXNE+STOP、时间回绕、NACK及各错误、TC/TXIS/STOP缺失、BUSY/时钟/微调/时序/时钟源错误、计时失败/停滞/期限超时、读失败输出不变、参数边界、拉伸与恢复成功/失败、无关字段保留。另测0x6A NACK后0x5C成功及NACK+STOP失败/BUSY未清锁存。模型不模拟电气边沿或证明芯片实际工作。

现有TIM2模型的Stop重初始化会调用新后端；只在`tests/tim2_timebase.c`添加I2C MMIO隔离hooks，保留原有TIM2断言，防止宿主访问真实外设地址。该适配不替代独立I2C模型。

本次实际可用的Homebrew LLVM/Clang 23.1.0以`-Wall -Wextra -Werror`生成两变体各10个ARM对象；`validation/i2c/objects.json`记录ELF32 ARM REL检查、SHA256及工具版本。静态分析无诊断。完整日志见同目录`host-tests.log`、`mcu-tests.log`、`arm-objects.log`、`static-analysis.log`。没有最终链接/运行时库验证。本轮未安装或切换工具；“20个对象”是构建产物数量。

修改范围：`src/board.c`仅I2C段、`include/board_revA2.h` I2C常数/契约、`tests/i2c_registers.c`/`test_i2c.py`、TIM2测试隔离、本报告和`validation/i2c/`。无新依赖、工具安装或提交。保留板上波形、所有器件WHOAMI/数据、传感器配置/采样率、低功耗恢复和最终ELF验证为未关闭项。

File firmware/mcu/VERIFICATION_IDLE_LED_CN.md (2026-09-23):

# 软件等待恢复、UART重试与LED输出（2026-09-23）

实现已通过模型与对象构建，**不是硬件Stop、实物闪光或最终固件验证**。本轮无PCB改变。

## 修复与边界

- APP_SLEEP当前只是软件等待。移除其对`board_buses_reinit_after_stop`的错误调用，避免没有进入Stop却丢失TIM2时基；真实Stop后失效保护函数保持原样，TIM2原模型仍覆盖它。
- `app_step_from_clock`在等待和转储期间也读取真实TIM2时间，避免长时间未服务32位epoch而无法识别回绕。非记录状态遇到时钟失败保留只读转储路径并锁存APP_ERROR_CLOCK；不伪造时间、不恢复记录。
- 时间已失效时，ERROR使用真实闭合输入请求只读转储，不要求无法验证的1.5s长按；其他错误仍使用长按。转储是否可完成还取决于SPI/UART时钟和设备状态。
- UART后端故障锁存后，APP现在显式重新初始化，再在下一步重试同一完整记录。保留原记录、序号与CRC，成功前不推进读取；失败可能已经发送前缀或整帧，主机仍须重同步/去重，没有ACK或持久化保证。
- `board_led_gate_set`使用PB0 BSRR和ODR读回，检查GPIO初始化、时钟及推挽输出模式。只改PB0锁存器，不能证明实际MOSFET/LED电流或光输出。
- LED模块实现原有AWA名义10Hz/50%/2s时序与取消，UW不触发闪光。写入/配置失败锁存，停止请求并尽力写低；硬件写入失效时可能保持高，不能声称物理关断成功。需显式`led_init`恢复。`APP_ERROR_LED`可查询并粘滞，不改变APO2/UART样本格式；LED失效不自动丢弃传感器记录。
- 闪光依赖`led_poll`调用节拍，没有硬件PWM；迟到/阻塞可能延长物理脉冲，必须实测调度/波形。咬钩检测器仍未实现，不能把输出驱动当检测成功。

## 真实回归证据

先加状态模型复现再修复：`regression_before.log`在四小时软件等待缺少时基服务的断言失败；`uart_regression_before.log`在模拟真实TX故障锁存后拒绝恢复的断言失败。新模型不再把Stop恢复或UART初始化写成无副作用空函数。

修复后AWA/UW均验证：四小时虚拟转储重试+四小时软件等待、跨32位回绕、等待不增加样本、正常恢复不触发Stop调用、时基故障永不恢复写日志、无需失效计时即可请求只读恢复；保留之前日志/CRC/重试断言。LED模型覆盖40个半周期、截止、回绕、取消、UW禁止闪光、ON/OFF写丢失和模式错误，并验证故障锁存与显式恢复。虚拟时间不是八小时实板运行。

主代理执行：

```sh
python3 -m unittest discover -s firmware/host/tests -p test_firmware_contract.py -k app_log_errors -v
python3 -m unittest discover -s firmware/mcu/tests -p test_gpio.py -v
python3 -m unittest discover -s firmware/mcu/tests -v
python3 -m unittest discover -s firmware/host/tests -v
make -C firmware/mcu objects-both CC=/opt/homebrew/opt/llvm/bin/clang BUILD=validation/idle_led_checkpoint/arm
```

MCU8/8、host23/23，状态机用例运行两变体；最终额外状态/LED粘滞检查也通过。两变体20个ARM ELF32 REL对象经独立标头/哈希验证，清单`validation/revA2_idle/objects.json`。`app.c`、`led.c`、`board.c`的ARM clang静态分析均无诊断。命令形式：

```sh
/opt/homebrew/opt/llvm/bin/clang --analyze --target=arm-none-eabi -mcpu=cortex-m0plus -mthumb -std=c11 -ffreestanding -I firmware/mcu/include -I firmware/mcu/runtime/include firmware/mcu/src/app.c -o validation/revA2_idle/app.plist
```

对led/board同样执行。完整日志`validation/revA2_idle/{final_mcu_tests,final_host_tests,final_state_test,final_arm_objects,led_test}.log`，各源分析日志及plist同目录。

## 剩余和文件

仍缺真实Stop/RTC补偿、最终链接/栈预算、器件/总线/ADC/时钟/电流/闪光实测；工具链安装授权待答复。板上与最终ELF成功均未声明。源文件修改为app.c、board.c的LED段、led.c及对应header；扩充app_errors/gpio模型和host双变体调用。输入备份在`validation/revA2_idle/baseline/`。无安装、提交、PCB或Rev.A1修改。

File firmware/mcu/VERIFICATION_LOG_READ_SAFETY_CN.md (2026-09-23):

# 日志读取输出保护 · 2026-09-23

已修复datalog_dump_next在CRC失败前覆盖调用者输出的问题。旧实现先memcpy到sample再校验；新实现校验本地候选，CRC通过才复制到输出并推进游标。空指针原已有防护，本次没有新加该逻辑；新增回归锁定其不推进游标的行为。接口声明明确0/-1不改输出。

实际证据：先加测试，旧代码在`memcmp(&out,&last_good,sizeof(out))==0`断言失败（red.log）；修复后`python3 -m unittest discover -s firmware/host/tests -v`共23项通过，日志生命周期用AWA/UW两变体分别编译执行。测试保留坏记录错误、存储修复后重新开始转储、空指针拒绝后的首条序号、历史日志只读等路径。

`make -C firmware/mcu objects-both CC=/opt/homebrew/opt/llvm/bin/clang BUILD=validation/log_read_safety/arm` exit0。20对象逐个ELF32 little-endian/ET_REL/EM_ARM检查通过，llvm-nm跨对象只有既知链接脚本符号和__aeabi运行库待解析，证据arm_verification.json。没有最终ELF、烧录或板上测试。

为核对新增临时记录的代价，使用相同Clang Cortex-M0+ -Os/-fstack-usage编译修改前后datalog.c：datalog_dump_next静态函数帧40→72字节，增加32字节；完整命令与.su在stack_delta.json及before/after_stack.su。仅为单函数帧证据，不是完整运行栈上界；旧资源审计对应修改前源码，最终链接/异常栈/实机测量仍缺。

修改文件：src/datalog.c、include/datalog.h、tests/log_lifecycle.c、firmware/host/tests/test_firmware_contract.py。证据目录validation/revA2_log_read_safety保留修改前源码、红/绿日志、ARM对象散列、栈差值和source_manifest.json。PCB/原理图未改，未重复ERC/DRC。

剩余：真正Stop/RTC补偿、咬钩检测与实机采样/Flash/转储可靠性仍未完成；最终链接缺lld/ARM builtins。不改变NOT_FAB_RELEASED状态，不将模型回归当硬件验证。

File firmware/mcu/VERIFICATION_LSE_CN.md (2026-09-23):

# STM32G031 LSE 有界启动（2026-09-23）

本报告更新旧 TIM2/时序报告中“LSE 未实现”的软件状态。已实现寄存器级启动与失败返回；**未验证实板起振、晶体参数、RTC 或低功耗功能**。

`board_start_clocks()` 先运行原有 `time_start()`，再要求 `board_time_us()` 给出有效 TIM2 时间。无有效时基时不访问 LSE/PWR。返回 1 仅表示本次观察到 LSEON+LSERDY 且无 bypass/CSS 故障/备份域 reset；其他路径返回 0。既有 app_boot 将该布尔值保存到 `sensors->lse_ok`，样本按此生成 LSE_FAIL；它是启动状态快照，不是运行期间的连续振荡器监控。APP_ERROR_CLOCK 的独立失败语义不变。

启动只写 BDCR.LSEON，保留 LSEDRV、RTCSEL、RTCEN、CSS、LSCO 等位，禁止 reset 备份域。已经 ready 时不进行备份域写入。已开但未 ready 时继续有界等待。BYP、CSS 检测故障、BDRST 或 ON=0/RDY=1 异常直接失败，不擅自修复已有备份域。开启 PWR 时钟并读回，设置 DBP 并在 TIM2 总预算内等待；受保护写入无效时失败。结束时恢复本次获取的 DBP/PWREN 位，保留原来已开启的权限与其他位；恢复读回失败也返回 0。超时不关闭 LSE，避免破坏其他备份域消费者。要求启动阶段独占 RCC/PWR 写入。

2 秒是软件策略超时，包含 DBP 等待，单位来自现有 HSI16/TIM2 标称微秒；允许计数器自然回绕。TIM2 停转或配置故障使等待立即失败。**TIM2 仍是 HSI16 来源，LSE ready 不代表时间戳已被 LSE 校准。** DS 的 2 秒只是典型启动时间，没有最坏上限；本策略可能拒绝较慢但健康的晶体，不承诺所有温度电压下启动成功。

硬件工作 BOM 的 Y1 仅列 `32.768kHz 12.5pF`，没有可核查的准确料号/ESR/最大驱动参数。代码保留当前 drive（复位默认低驱动），没有人为提高 drive；这不等于与板上负载匹配。仍需确认准确晶体规格、负载/寄生电容、增益裕量、实际驱动功率以及冷启动/温度/电压边界。没有 NVIC、RTC 配置、Stop 唤醒或成功测量声明。

## 官方依据

本次实际读取 ST 官方资料，未新增依赖：

- [stm32g031xx.h](https://raw.githubusercontent.com/STMicroelectronics/cmsis-device-g0/master/Include/stm32g031xx.h)：RCC BDCR 偏移0x5C、LSEON/RDY/BYP/DRV/CSSD/BDRST 位，APBENR1.PWREN bit28，PWR.CR1.DBP bit8。
- [ST LL RCC](https://raw.githubusercontent.com/STMicroelectronics/stm32g0xx-hal-driver/master/Inc/stm32g0xx_ll_rcc.h)：LSE enable/ready 与晶体/bypass 模式、drive 字段、CSS 故障状态访问。
- [ST LL PWR](https://raw.githubusercontent.com/STMicroelectronics/stm32g0xx-hal-driver/master/Inc/stm32g0xx_ll_pwr.h)：DBP 控制备份域写访问。
- [DS12992 Rev4](https://www.st.com/resource/en/datasheet/stm32g031f8.pdf) 表40及其说明：四种 drive 对应不同晶体增益条件；2秒启动为典型值，随晶体厂商显著变化，负载器件/布局必须独立确认。

## 实际验证

仓库根目录执行，日志见 `validation/lse/`：

```sh
python3 -m unittest discover -s firmware/host/tests -v
python3 -m unittest discover -s firmware/mcu/tests -v
make -C firmware/mcu objects-both CC=/opt/homebrew/opt/llvm/bin/clang BUILD=validation/lse/arm
/opt/homebrew/opt/llvm/bin/clang --analyze --target=arm-none-eabi -mcpu=cortex-m0plus -mthumb -std=c11 -ffreestanding -I firmware/mcu/include -I firmware/mcu/runtime/include firmware/mcu/src/board.c -o /tmp/lse-board.plist
```

- host 23/23，7.553秒；MCU 8/8，6.266秒（原7项+LSE模型）；两变体分别运行全部寄存器模型。
- LSE 模型直接编译实际 board.c，并使用真实 TIM2 实现配合模拟寄存器，覆盖 cold start、already ready、already on、重入 epoch、超时、计数器回绕、无有效时基、PWREN/DBP/BDCR 写入被拒绝、运行中时基停止/时钟破坏、BYP/CSS/reset 异常、无关位保留与权限恢复。
- 原 TIM2 模型仅新增惰性 LSE hooks，原断言全部保留。未改 TIM2/GPIO/ADC/其他总线实现；ADC 由主代理同时修改，本次全回归包含该修改。
- AWA/UW 共20个 Cortex-M0+ 目标文件通过 `-Wall -Wextra -Werror`；独立解析20个 ELF 头均为 little-endian ELF32 ARM relocatable，SHA256见 `validation/lse/objects.json`。
- ARM clang 静态分析无诊断，plist 见验证目录。没有链接/烧录/实板测量；模型不模拟真实晶体、异步同步器、APB 延迟或电气特性。

修改范围：`src/board.c` 的 LSE helper/启动返回；`include/board_revA2.h` LSE 常量与契约；`tests/tim2_timebase.c` 惰性 hook；新增 `tests/lse_registers.c`、`tests/test_lse.py`、本报告及验证日志。无安装、无新依赖、无提交。

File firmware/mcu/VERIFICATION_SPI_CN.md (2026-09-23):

# STM32G031 SPI1 / PA4 软件片选验证（2026-09-23）

已用真实 MMIO 实现 SPI1，取代发送/接收/片选失败桩。**仅通过寄存器模型及 ARM 目标文件编译；未链接最终固件、未烧录、未进行板上验证。** TIM2 生产代码保持不变；I2C、UART 等未实现部分不因此获得硬件支持。

## 行为及边界

- PA4 先通过 BSRR 置高，再配置推挽输出，最后开启 SPI；PA5/6/7 AF0。仅修改对应 GPIO 字段和 GPIOA/SPI1 RCC 位，保留 SWD PA13/14、其他引脚及 SYSCFG remap。
- 严格检查 HSI 开启/就绪、HSIDIV=/1、SW/SWS=HSISYS、AHB/APB=/1，不修改时钟树。16 MHz PCLK 配 BR=/16，得到标称 1 MHz SCK；每次轮询检查时钟和微调值及关键外设配置。HSI 容差仍然存在。
- Mode 0、主机、MSB first、软件 NSS（SSM/SSI），全双工；DS=7、FRXTH=1，DR 只通过 volatile uint8_t 读写，避免 16 位访问打包出额外时钟。TX 每字节读取并丢弃收到的数据；RX 发 0xFF dummy。
- 每个 TXE、RXNE、BSY 等待最多 256 次；次数不是校准时间。CS 释放前等待 TXE 且 BSY/RXNE 清零，跨 tx/rx 调用保持片选。调用者必须串行访问；不支持 ISR/DMA 并发，也不允许其他模块更改 SPI1/PA4..7。
- OVR/MODF/FRE、时钟变化、无效指针及超时返回 -1，释放片选并锁存失败。通过 DR→SR→CR1 序列处理故障并关闭 SPE；下次显式 init 的 RCC reset 丢弃残余 FIFO。重新初始化会终止既有事务，不透明重试。
- 失败前发送的字节可能已经影响 flash；接收缓冲区可能保留有效前缀。失败不等于没有副作用，不得将部分数据当完整事务。初始化前调用保持失败闭合，不触碰 MMIO；已初始化后的失败会释放 CS。
- Stop 唤醒仍调用 SPI init，但不会恢复 TIM2 epoch；现有时基错误策略保持原样。GPIO/RCC 被并发修改、引脚硬件故障或整机失钟不能由软件保证恢复。

## 官方依据

本次实际读取：

- [ST CMSIS stm32g031xx.h](https://raw.githubusercontent.com/STMicroelectronics/cmsis-device-g0/master/Include/stm32g031xx.h)：GPIOA、SPI1、RCC 地址、寄存器布局和位定义。
- [ST LL SPI](https://raw.githubusercontent.com/STMicroelectronics/stm32g0xx-hal-driver/master/Inc/stm32g0xx_ll_spi.h)：ReceiveData8 / TransmitData8 的字节访问、OVR 的 DR→SR 清除、MODF 的 SR→CR1 清除，以及 BSY 行为。
- [ST DS12992 Rev 4](https://www.st.com/resource/en/datasheet/stm32g031f8.pdf)：引脚复用表、HSI16 与 SPI 外设。
- [ST 系统时钟源码](https://raw.githubusercontent.com/STMicroelectronics/cmsis-device-g0/master/Source/Templates/system_stm32g0xx.c)：HSI 标称频率和时钟分频计算。

[RM0444](https://www.st.com/resource/en/reference_manual/rm0444-stm32g0x1-advanced-armbased-32bit-mcus-stmicroelectronics.pdf) 本次 web 请求返回 Internal Error；未声称读取完整 RM。实现依据为上面的官方器件头文件、LL 源码和数据手册；没有引入 CMSIS/HAL 依赖。

## 实际验证命令及证据

从仓库根目录执行：

```sh
python3 -m unittest discover -s firmware/host/tests -v
python3 -m unittest discover -s firmware/mcu/tests -v
make -C firmware/mcu objects-both CC=/opt/homebrew/opt/llvm/bin/clang BUILD=validation/spi/arm
/opt/homebrew/opt/llvm/bin/clang --analyze --target=arm-none-eabi -mcpu=cortex-m0plus -mthumb -std=c11 -ffreestanding -I firmware/mcu/include -I firmware/mcu/runtime/include firmware/mcu/src/board.c -o firmware/mcu/validation/spi/board.plist
```

Host 23/23，MCU 3/3（runtime、TIM2、新增 SPI，每个寄存器模型运行 AWA/UW 两变体）。SPI 模型模拟延迟 TX/RX 状态、接收 FIFO 消耗、尾部 BSY、软件 CS、电路配置顺序、8 位 DR 限制、RCC reset 副作用；注入 TXE/RXNE/BSY 卡住、OVR/MODF/FRE、错误时钟、配置破坏、空指针、部分 RX、重初始化。测试验证无关 GPIO/RCC 字段保留。它不是完整 STM32 仿真，不证明引脚波形或实际总线行为。

20 个 Cortex-M0+ 对象使用 `-Wall -Wextra -Werror` 编译成功，独立解析 ELF 头确认 ELF32 little-endian ARM；哈希清单 `validation/spi/objects.json`。clang 静态分析无诊断。完整日志 `validation/spi/{host-tests,mcu-tests,arm-objects}.log`。

修改范围：`src/board.c`、`include/board_revA2.h`；新增 `tests/spi_registers.c`、`tests/test_spi.py`、本报告。`tests/tim2_timebase.c` 只加入惰性 SPI hooks，使其 Stop 测试不会访问宿主物理地址，保留原断言。修改前文件备份 `validation/spi_before/`。没有安装工具、增加依赖、提交或宣称最终 ELF 成功。

尚需硬件：逻辑分析仪确认 CS 启动与错误释放、SCK=Mode0/约 1 MHz、每字节恰好 8 个脉冲、MISO/MOSI 与电压/负载下的边沿；实际 JEDEC ID、读状态/页编程/读回、断开 flash、总线故障、Stop 后重新初始化和 SWD 保持。GNU 工具链和最终链接由独立授权/验证流程处理。

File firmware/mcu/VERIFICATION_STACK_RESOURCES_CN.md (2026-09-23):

# ARM资源审查：对象文件阶段 · 2026-09-23

状态：**PRELINK_RESOURCE_EVIDENCE_ONLY**。完成新的真实ARM编译和资源统计，不是最终ELF、完整栈上界或板上运行通过。生产固件源码未改，未安装依赖。

## 实际命令

```sh
make -C firmware/mcu objects-both CC=/opt/homebrew/opt/llvm/bin/clang BUILD=validation/stack_audit/arm CFLAGS='-mcpu=cortex-m0plus -mthumb --target=arm-none-eabi -std=c11 -Os -g -ffreestanding -fno-builtin -ffunction-sections -fdata-sections -Wall -Wextra -Werror -fstack-usage'
python3 firmware/mcu/tests/report_arm_resources.py --build firmware/mcu/validation/stack_audit/arm --llvm-bin /opt/homebrew/opt/llvm/bin --output firmware/mcu/validation/stack_audit/resources.json
```

现有Homebrew Clang23.1.0，两个版本共20个对象，编译exit0，保留build.log、全部.o/.su、反汇编和llvm-size输出。资源脚本校验ELF32小端、ET_REL、EM_ARM，保存源文件及对象散列。另用llvm-size --format=sysv逐对象独立交叉检查.data/.bss合计，结果一致，见independent_section_crosscheck.json。

## 结果与边界

| 对象文件指标 | AWA / variant0 | UW / variant1 |
|---|---:|---:|
| 静态RAM节有效字节之和 | 714 | 705 |
| 每节另计最大对齐填充后的和 | 847 | 829 |
| 只读ALLOC节字节之和 | 9830 | 10084 |
| 编译器栈记录函数数 | 74 | 74 |
| 最大单函数栈帧 | 312 | 312 |
| 已知直接调用链最大栈帧合计 | 616 | 616 |
| 反汇编调用数/调用或跳转重定位数 | 193/193 | 205/205 |

以上是链接前统计：节可能被gc-sections删除或重排，最终固件另含运行库、填充与可能的链接器跳板。只读ALLOC和不能当最终烧录镜像大小，RAM两行不能当最终map。

最大单帧为flash_page_program312字节，其次board_i2c1_read_n288字节。最长已知路径为Reset_Handler→main→app_step_from_clock→app_step→datalog_append→datalog_flush_page→flash_page_program→flash_read→flash_cmd→board_spi1_tx→spi_transfer→spi_wait_mask。尾跳保守保留调用者帧，不把各函数栈帧简单求和作为使用量。

当前反汇编没有发现寄存器间接调用，解析到的直接调用图没有递归环；仅对本次产物成立。未知被调函数帧仍有__aeabi_lmul、__aeabi_uidiv、__aeabi_uldivmod。脚本对未知帧不计入已知小计，同时明确输出full_stack_bound_verified=false，不能把616字节当全路径上界。

runtime/stm32g031f8.ld声明8KiB RAM并保留2KiB栈；最终链接尚未完成，该ASSERT还未在最终ELF中执行。异常硬件压栈、嵌套中断、外部运行库、最终链接布局、真实启动和高水位测量均未验证。报告没有把“看起来有余量”升级为安全通过。

## 新增文件及下一步

新增tests/report_arm_resources.py及validation/stack_audit证据。本轮没有修改生产源码、没有重复既有功能测试；此前8/8 MCU、23/23 host仅为已有行为证据。

下一步在具备已授权的完整ARM链接工具链/运行库后生成ELF/map，执行链接ASSERT，再对最终ELF重新核调用图和栈，最后板上用栈填充水位与错误/转储/采样路径实测。当前无新工具链安装授权，未安装。KiCad审批服务额度问题仍独立存在，本次编译为不依赖该审批的固件工作，没有重试或绕过被拒绝的PCB操作。

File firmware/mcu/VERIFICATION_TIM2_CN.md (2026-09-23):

# STM32G031 TIM2 微秒时基（2026-09-23）

已实现寄存器级运行态时基；通过宿主寄存器模型和实际 ARM 目标文件编译。**未链接完整固件、未烧录、未验证板上运行/精度。** 本文更新旧 `VERIFICATION_TIMING_CN.md` 中“时基始终失败”的状态，其他未关闭 HAL 条件仍有效。

## 实现与约束

`board_start_clocks()` 在现有 app_boot 调用点初始化 TIM2。LSE 仍未实现，返回 0 保留 LSE_FAIL。`board_time_us()` 初始化前保持原来的失败闭合行为，不触碰 MMIO。

启动和每次读取验证 RCC：HSI 开启且就绪、HSIDIV=/1、系统时钟请求和实际来源均为 HSISYS、AHB/APB 分频均 /1。任何不同配置直接拒绝；不修改系统时钟树。读取时还验证校准/微调寄存器未变化。因此 TIM2 标称输入 16 MHz，PSC=15、ARR=0xffffffff；UG 装载预分频，清状态，启动内部时钟向上计数，禁用中断/DMA。32 位 CNT 原子读取并自然回绕，无软件溢出 ISR。

开启和重置只操作 TIM2 RCC 位，保留其他外设位；开启后读回作同步。初始化与每次取时最多 4096 次轮询，必须观察到真实 CNT 变化。循环次数仅限定失败等待，绝不充当时间。配置变化、停转或超过 INT32_MAX us 的差值均锁存失败，输出不变。重复初始化不重置 epoch 或清故障；重新上电/复位才清除。Stop 唤醒的现有 `board_buses_reinit_after_stop()` 明确作废 epoch，下一次 RECORD 走既有 APP_ERROR_CLOCK 路径，禁止继续伪连续记录。

TIM2 与 RCC 时钟树必须由此模块独占；不能被 ISR、调试脚本或未来 HAL 改写。每次调用间隔必须不超过 INT32_MAX us。HSI 是标称时间，温度、电压和校准误差需实测；该实现没有 RTC 补偿。**两次读取之间发生并恢复的短暂时钟停止、隐藏的 CNT 重写/复位、任意长停顿不能仅凭该计数器完整检测**，因此不能把寄存器检查解释为独立时钟监视器。真正 Stop 前后的连续时间需要独立 RTC/LPTIM 方案。

## 官方依据

2026-09-23 通过 web 工具实际读取以下 ST 官方资料；未新增 CMSIS/HAL 依赖：

- [STM32G031 数据手册 DS12992 Rev 4](https://www.st.com/resource/en/datasheet/stm32g031f8.pdf)，§3.16.2 / 表7：TIM2 为 32 位计数器、16 位预分频；§3.16.3：低功耗定时器的 Stop 工作条件。
- [ST stm32g031xx.h](https://raw.githubusercontent.com/STMicroelectronics/cmsis-device-g0/master/Include/stm32g031xx.h)：TIM2 地址、寄存器偏移、RCC 时钟/重置/睡眠位及 HSIDIV/SW/SWS/HPRE/PPRE 定义；TIM2EN/TIM2RST/TIM2SMEN 都是 bit0。
- [ST system_stm32g0xx.c](https://raw.githubusercontent.com/STMicroelectronics/cmsis-device-g0/master/Source/Templates/system_stm32g0xx.c)：HSI 标称 16 MHz，HSIDIV、AHB 分频计算以及实际频率容差说明。
- [ST LL TIM](https://raw.githubusercontent.com/STMicroelectronics/stm32g0xx-hal-driver/master/Inc/stm32g0xx_ll_tim.h)：CNT 读取、PSC+1 分频和更新事件装载规则。

尝试读取 RM0444 PDF 时 web 返回 Internal Error，未以“已读完整 RM”作为证据。实际依据为上列数据手册和 ST 官方 CMSIS/LL 源码。

## 检查及结果

仓库根目录执行：

```sh
python3 -m unittest discover -s firmware/host/tests -v
python3 -m unittest discover -s firmware/mcu/tests -v
make -C firmware/mcu objects-both CC=/opt/homebrew/opt/llvm/bin/clang BUILD=validation/tim2/arm
/opt/homebrew/opt/llvm/bin/clang --analyze --target=arm-none-eabi -mcpu=cortex-m0plus -mthumb -std=c11 -ffreestanding -I firmware/mcu/include -I firmware/mcu/runtime/include firmware/mcu/src/board.c -o /tmp/tim2-board.plist
```

- 修改前 host 23/23（8.362s）；修改后 23/23（6.179s）。原故障闭合/APP_ERROR_CLOCK 回归仍通过。
- MCU 2/2（含现有 runtime 测试与新时基测试；1.346s）。TIM2 寄存器模型对 AWA/UW 分别测试初始化前失败、错误时钟源/分频、HSI 未就绪、未启动计数器、时基重入、无 IRQ/DMA、无关 RCC 位保留、跨 32 位回绕、过长间隔、各配置破坏及恢复后的错误锁存、停转、CNT 后退、Stop 唤醒后失败。
- 两变体所有 20 个 Cortex-M0+ 对象实际编译成功，`-Wall -Wextra -Werror`；独立解析 ELF 头确认 20 个为 ELF32 little-endian ARM relocatable。哈希清单 `validation/tim2/objects.json`。
- ARM clang 静态分析无诊断。完整命令/日志见 `validation/tim2/`。
- 未进行链接、硬件计时频率/抖动、调试冻结、Stop 功耗及连续性测量。模型不模拟真实 APB 总线、影子寄存器或振荡器。

修改 `src/board.c`、`include/board_revA2.h`；新增 `tests/tim2_timebase.c`、`tests/test_tim2.py`、本报告与证据。`app.c` 无需修改。修改前拥有范围的三个文件备份于 `validation/tim2_before/`，保留此前未提交改动。无新依赖、无安装、无提交。

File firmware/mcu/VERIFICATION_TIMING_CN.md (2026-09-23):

# Rev.A2 固件时基修复验证

状态：**native 逻辑可编译及模拟测试通过；HAL 时基未实现；ARM 启动及板上运行未验证。**

## 问题与改动

原 `main.c` 每轮无条件 `now_us += 1000`，可将 CPU 循环误认为真实毫秒；原 `sensors.c` 用 `now >= deadline` 和 `now + floor(1000000/hz)`，跨 32 位回绕失效且累积轮询/截断漂移。

改为 `board_time_us()` 明确 HAL 契约，骨架始终失败且不修改输出。`app_step_from_clock()` 在 RECORD 取时失败立即置 `APP_ERROR_CLOCK`、关 LED、禁止继续写入；已有数据仍可只读转储。`main` 不再生成伪时间。直接传入时间的 `app_step()` 保留为注入时钟测试入口。

传感器调度用四个整数相位：`phase += elapsed_us * hz`，以 1000000 为分母，无小数周期累积误差。第一次调用建立相位，后续无符号差可跨 32 位计数回绕。每次最多读各通道一次，迟到的历史槽计入饱和计数，禁止突发补造历史数据。时间差大于 INT32_MAX 判为错误并锁定；应用处理 -1 时不再把错误返回值当作有效样本。

备份位置：`validation/timing_baseline/`。只复制本子任务修改前的文件，未覆盖已有工作。APO2/34 字节样本/UART v1 格式未改。

## 实际检查

仓库根目录命令：

```sh
python3 -m unittest discover -s firmware/host/tests -v
```

- 修改前：15 项，通过（5.775 秒）。
- 修改后：17 项，通过（7.027 秒），完整输出 `validation/native_tests_timing.log`。
- 该套件对两变体所有 MCU 源文件执行 native `clang -std=c11 -Wall -Wextra -Werror -fsyntax-only`。
- 新 `tests/sensors_timing.c` 两变体各模拟 3 小时、1 ms 步进，包含重复同一时间的额外调用：IMU 104/208 Hz、压力 50/100 Hz、张力 320 Hz、电池 1 Hz 总数均严格等于秒数×频率+初始一次；所有未过载计数为零。起点设在 UINT32_MAX 附近，覆盖多次回绕。
- 1 秒调度停顿：各通道只读一次，跳槽计数正确；恢复保持相位且不突发补发。后退时间与 0x80000000 歧义间隔拒绝采样并锁定错误。
- 时基骨架失败不改变输出值；应用时基失败不调用采样、无记录增加；错误后只能只读转储。传感器错误返回不被追加为记录。

## 改动文件

- `src/main.c`, `src/board.c`, `include/board_revA2.h`：时基契约和实际入口。
- `src/app.c`, `include/app.h`：失败闭合、时钟错误位。
- `src/sensors.c`, `include/sensors.h`：回绕、相位、过载诊断。
- `tests/app_errors.c`, 新 `tests/sensors_timing.c`；`firmware/host/tests/test_firmware_contract.py`：回归证据。
- `README_CN.md`、本报告、native 日志及修改前备份。

## 未关闭条件

1. 无真实 HAL 时基；未指定未经确认的 MCU 定时器。必须根据芯片资源/时钟树提供可靠微秒计时、溢出处理、Stop 连续性与故障报告。
2. 仅凭 32 位计数不能辨认任意长停顿或硬件冻结；调用间隔须 ≤ INT32_MAX us，HAL 必须报告停转/重置，不能根据循环数判断物理时长。
3. 跳槽计数是 RAM 诊断，未持久化到 v1 记录；不代表传感器实际丢样数。IMU/压力真实 DRDY/FIFO 与 I²C/Flash 最坏阻塞时间仍需上板测量。
4. 主机 `dump_decode.py` 当前主动拒绝 timestamp 回绕以免错误 autotune，约 71.6 分钟以上记录需显式重建时间；本任务未修改主机解码实现。
5. 未运行 ARM 构建、未烧录、未验证实际频率/抖动/功耗；无新增依赖。

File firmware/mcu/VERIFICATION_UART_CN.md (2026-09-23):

# STM32G031 USART2 TX 验证（2026-09-23）

USART2 TX 已替换为寄存器后端，UART v1 帧结构及 host 解码协议不变。**仅寄存器模型、宿主回归及 ARM 目标文件验证；没有最终 ELF、烧录或板上成功声明。**

## 行为边界

- GPIOA/USART2 时钟使能及 USART2 reset 只改对应 RCC 位；PA2/PA3 配 AF1、推挽、低速、无上下拉，保留 PA13/14 SWD、PA9/10 remap、SPI 及其他引脚。初始化不更改系统时钟树。
- 只接受 HSI16 开启并就绪、HSIDIV=/1、SW/SWS=HSISYS、AHB/APB=/1；保存并检查 ICSCR 微调。G031 USART2 使用 PCLK，不存在其他型号的 USART2SEL 配置。PRESC=/1、OVER8=0、BRR=139，标称约 115108 baud（相对115200约 -0.08%，另有 HSI 容差）。
- 8N1、仅 TE|UE，关闭 RX/FIFO/IRQ/DMA/流控。PA3 仍配置 AF1，但不提供收包或主机 ACK；避免无人读取 RDR 引起 ORE。未来双向协议必须另行实现 RX 消费和错误恢复。
- 初始化等待 TEACK/TXE/TC；每个字节写 TDR 前等待 TEACK/TXE，最后等待 TEACK/TC。每次最多256次轮询并复核时钟、BRR、控制寄存器、GPIO及RCC。次数是终止上限，不是校准微秒数；实物须测定是否足够覆盖整字节/初始化延时。
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

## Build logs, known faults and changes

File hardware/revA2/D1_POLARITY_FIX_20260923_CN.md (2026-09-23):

# D1极性修复检查点 · 2026-09-23

正式PCB SHA256 `6399dd180a5b50c9931cfed0662c3caf641f06213e151ca5037d261392fa9602`。D1内部数字极性约定冲突已修正，所购LED实际外形/标记核验仍开放。官方ERC0错误/0警告，DRC0错误/0未连接/0一致性问题、3项courtyard警告；NOT_FAB_RELEASED。

## 最终修复

D1不再使用PASSIVE2。新增项目符号LED_AK_REVA2，从本机KiCad Device:LED派生镜像图形、延长引脚到既有±7.62mm端点，保持原理图导线/标签位置：左侧2=A接LED_A，右侧1=K接LED_K。原理图嵌入定义与项目库一致，LED图形明确显示二极管方向。

PCB D1旋转180°（90°→270°，API规范化为-90°），新项目封装LED_0805_2012Metric_RevA2_K1。上下焊盘的物理网络保持：上方(2.3,31.7125)mm现在为1/K/LED_K，下方(2.3,33.5875)mm为2/A/LED_A。阴极丝印与Fab端标、3D模型方向随封装同步旋转。位号保持原位置。没有重新布线。

独立geometry.py按物理坐标比较两焊盘：位置、尺寸、边界框、圆角比、层集、阻焊裕量与网络完全一致，仅编号互换；模型局部旋转未变、全局随封装转180°。PCB剔除D1封装块后逐字节一致；原理图除新增符号与D1两个引用外一致；网表只变D1编号，所有其他网络节点保持。确认R6.2→D1.2/A、D1.1/K→Q1.3漏极。

旧EdgeSilk封装作为历史保留，不能用于当前D1。工作BOM已同步K1封装。历史生成脚本仍可能重建PASSIVE2/旧极性，未执行；不要在已修复工程上运行重新生成。

## 实际检查

- 独立候选`kicad-cli sch erc --format json --severity-all`：0违规；`sch export netlist --format kicadxml`成功。
- 独立候选`kicad-cli pcb drc --format json --severity-all --units mm --refill-zones --schematic-parity`：0错误/0未连/3项courtyard。
- `python3 validation/revA2_led_polarity_fix/verify.py`：电路修改范围与网表一致性通过；KiCad内置Python运行geometry.py：物理焊盘/网络不变量通过。
- 官方PCB与原理图PDF经Poppler渲染并查看，D1符号与阴极侧一致；并非全图视觉验收。首轮候选符号重命名错误曾导致加载失败，修正后重新执行所有检查；未把失败当通过。
- 正式采用后`bash tools/export_fab_revA2.sh --check-only`及官方XML网表导出：exit0，ERC/DRC上述结果。
- `python3 tools/validate_revA2.py`：exit0，Rev.A1保持。
- `python3 tools/check_bom_revA2.py --output validation/revA2_led_polarity_fix/bom_consistency.json`：43位号一致性及新D1 K_1/A_2语义通过。
- `python3 -m unittest discover -s tools/tests -v`：17项通过，新增两项极性回归拒绝编号颠倒及无极性PASSIVE语义退化。

工具输出在validation/revA2_led_polarity_fix/：baseline/candidate/final、verification.json、geometry.json、PDF/PNG、日志、tests.log。修改PCB/原理图/项目符号库、新K1封装、工作BOM、库README、BOM检查工具与测试、官方/离线报告及交接文档。固件未改未重测，fab_export不存在。

## 后续与边界

采购准确LED型号及实际K/A外观、光学和额定电流仍未核验；本次仅关闭设计内部冲突。旧STEP及装配图对应旧D1旋转，必须从最终板重导出并审核。原理图整页PDF暴露既有器件越页和标签拥挤，完整可审核图面需修整，不得仅凭ERC0称为完成。三个连接区courtyard、准确采购/工艺、3D、最终ELF和实机门槛仍开放。

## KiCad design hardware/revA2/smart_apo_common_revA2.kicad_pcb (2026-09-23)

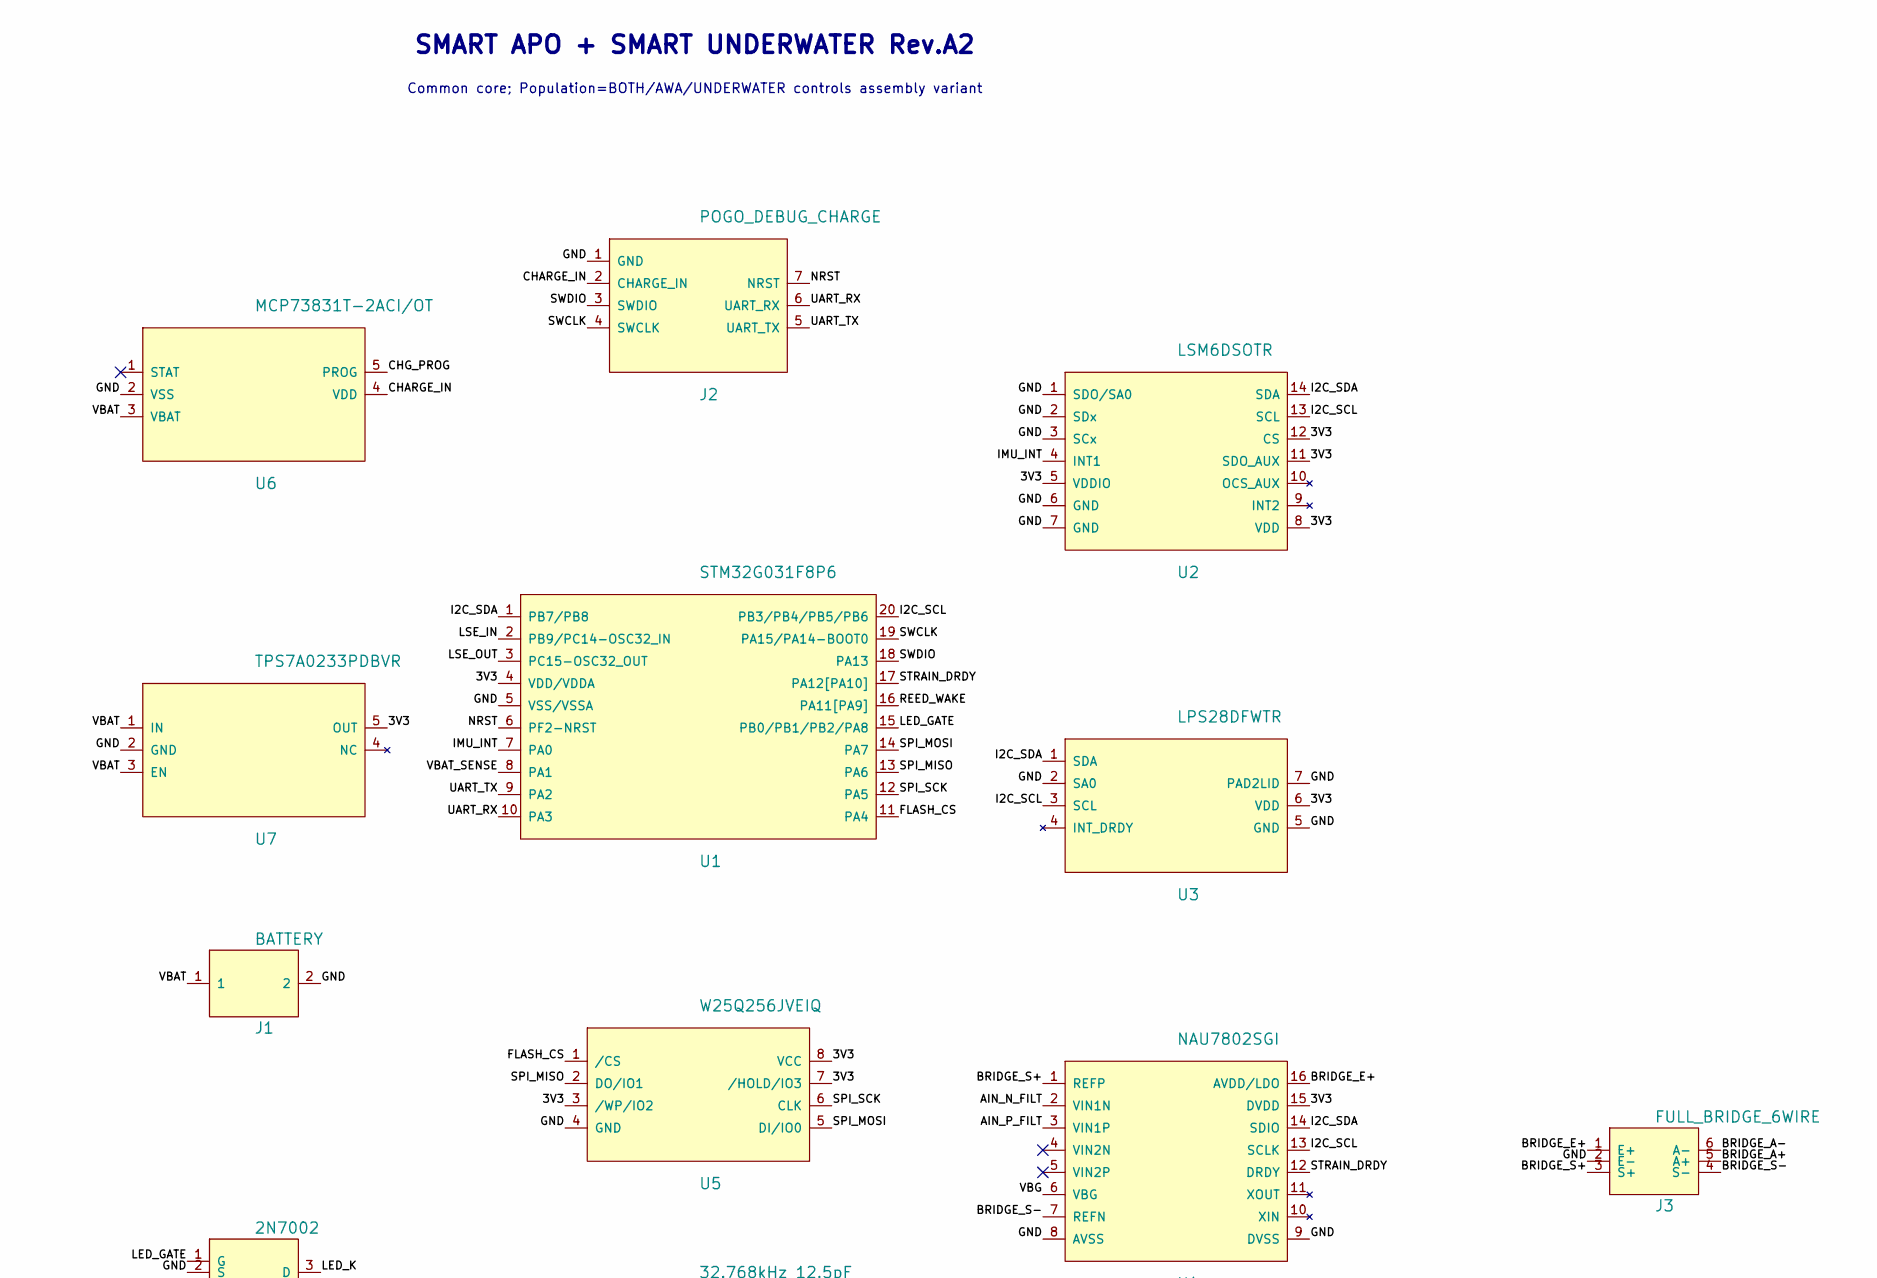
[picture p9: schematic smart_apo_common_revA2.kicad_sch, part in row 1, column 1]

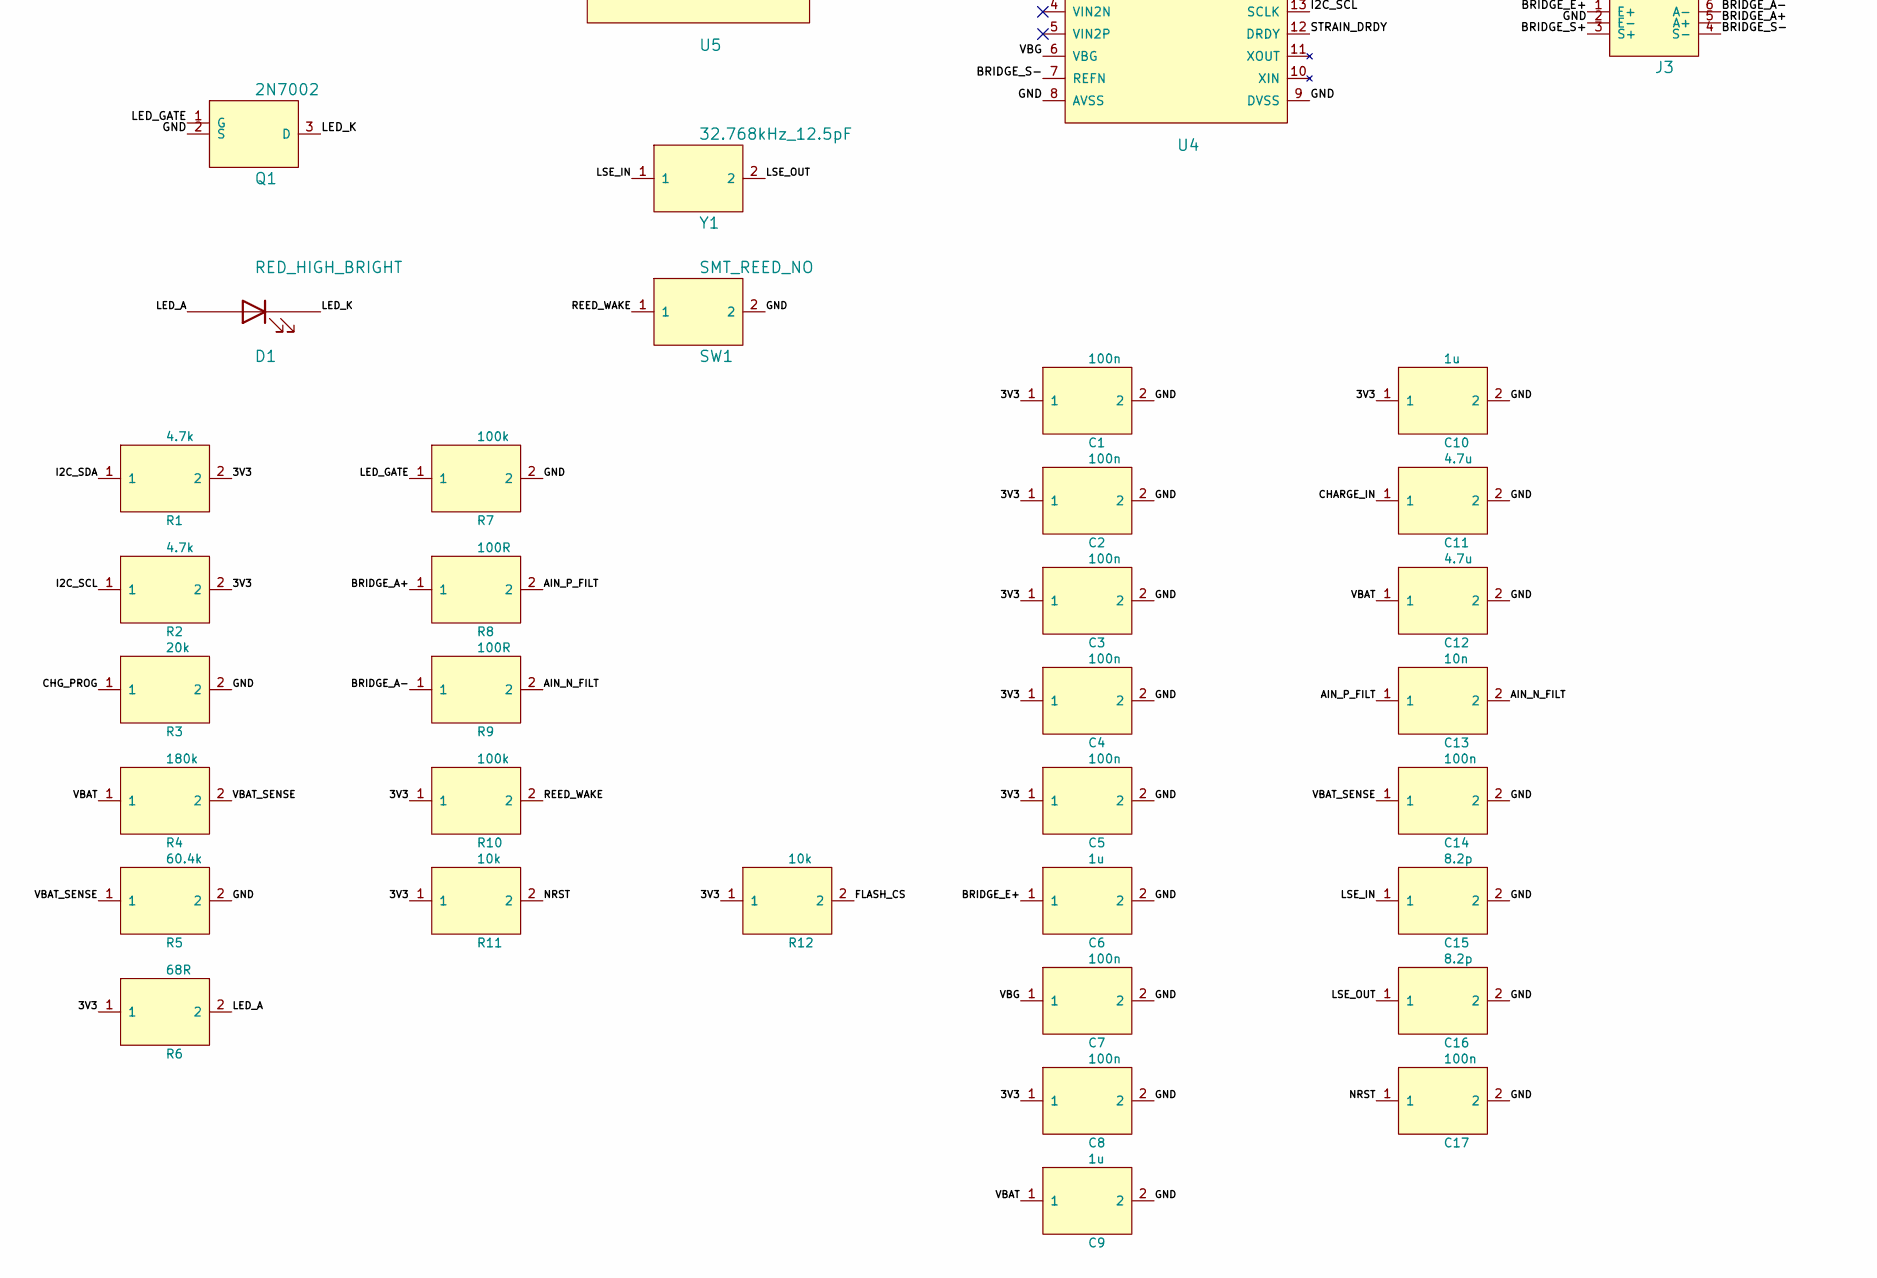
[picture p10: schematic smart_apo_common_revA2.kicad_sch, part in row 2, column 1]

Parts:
C1, C2, C3, C4, C5, C7, C8, C14, C17: 100n; C_0402_1005Metric
C6, C9, C10: 1u; C_0402_1005Metric
C11, C12: 4.7u; C_0402_1005Metric
C13: 10n; C_0402_1005Metric
C15, C16: 8.2p; C_0402_1005Metric
D1: RED_HIGH_BRIGHT; LED_0805_2012Metric_RevA2_K1
J1: BATTERY; BATTERY_WIRE_PADS
J2: POGO_DEBUG_CHARGE; POGO_7x1.27mm
J3: FULL_BRIDGE_6WIRE; PAD_6x1.27mm
Q1: 2N7002; SOT-23
R1, R2: 4.7k; R_0402_1005Metric
R3: 20k; R_0402_1005Metric
R4: 180k; R_0402_1005Metric
R5: 60.4k; R_0402_1005Metric
R6: 68R; R_0402_1005Metric
R7, R10: 100k; R_0402_1005Metric
R8, R9: 100R; R_0402_1005Metric
R11, R12: 10k; R_0402_1005Metric
SW1: SMT_REED_NO; REED_CT05_COMPACT
U1: STM32G031F8P6; TSSOP-20_4.4x6.5mm_P0.65mm_RevA2_Pin1
U2: LSM6DSOTR; LGA-14_3x2.5mm_P0.5mm_LSM6DSO
U3: LPS28DFWTR; LPS28DFW_CCLGA-7L
U4: NAU7802SGI; SOIC-16_3.9x9.9mm_P1.27mm
U5: W25Q256JVEIQ; WSON-8_W25Q256JV_8x6mm_AN0000009
U6: MCP73831T-2ACI/OT; SOT-23-5
U7: TPS7A0233PDBVR; SOT-23-5
Y1: 32.768kHz_12.5pF; Crystal_SMD_2012-2Pin_2.0x1.2mm

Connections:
/3V3: C1.1, C2.1, C3.1, C4.1, C5.1, C8.1, C10.1, R1.2, R2.2, R6.1, R10.1, R11.1, R12.1, U1.4 (VDD/VDDA), U2.5 (VDDIO), U2.8 (VDD), U2.11 (SDO_AUX), U2.12 (CS), U3.6 (VDD), U4.15 (DVDD), U5.3 (/WP/IO2), U5.7 (/HOLD/IO3), U5.8 (VCC), U7.5 (OUT)
/AIN_N_FILT: C13.2, R9.2, U4.2 (VIN1N)
/AIN_P_FILT: C13.1, R8.2, U4.3 (VIN1P)
/BRIDGE_A+: J3.5 (A+), R8.1
/BRIDGE_A-: J3.6 (A-), R9.1
/BRIDGE_E+: C6.1, J3.1 (E+), U4.16 (AVDD/LDO)
/BRIDGE_S+: J3.3 (S+), U4.1 (REFP)
/BRIDGE_S-: J3.4 (S-), U4.7 (REFN)
/CHARGE_IN: C11.1, J2.2 (CHARGE_IN), U6.4 (VDD)
/CHG_PROG: R3.1, U6.5 (PROG)
/FLASH_CS: R12.2, U1.11 (PA4), U5.1 (/CS)
/GND: C1.2, C2.2, C3.2, C4.2, C5.2, C6.2, C7.2, C8.2, C9.2, C10.2, C11.2, C12.2, C14.2, C15.2, C16.2, C17.2, J1.2, J2.1 (GND), J3.2 (E-), Q1.2 (S), R3.2, R5.2, R7.2, SW1.2, U1.5 (VSS/VSSA), U2.1 (SDO/SA0), U2.2 (SDx), U2.3 (SCx), U2.6 (GND), U2.7 (GND), U3.2 (SA0), U3.5 (GND), U3.7 (PAD2LID), U4.8 (AVSS), U4.9 (DVSS), U5.4 (GND), U6.2 (VSS), U7.2 (GND)
/I2C_SCL: R2.1, U1.20 (PB3/PB4/PB5/PB6), U2.13 (SCL), U3.3 (SCL), U4.13 (SCLK)
/I2C_SDA: R1.1, U1.1 (PB7/PB8), U2.14 (SDA), U3.1 (SDA), U4.14 (SDIO)
/IMU_INT: U1.7 (PA0), U2.4 (INT1)
/LED_A: D1.2 (A), R6.2
/LED_GATE: Q1.1 (G), R7.1, U1.15 (PB0/PB1/PB2/PA8)
/LED_K: D1.1 (K), Q1.3 (D)
/LSE_IN: C15.1, U1.2 (PB9/PC14-OSC32_IN), Y1.1
/LSE_OUT: C16.1, U1.3 (PC15-OSC32_OUT), Y1.2
/NRST: C17.1, J2.7 (NRST), R11.2, U1.6 (PF2-NRST)
/REED_WAKE: R10.2, SW1.1, U1.16 (PA11[PA9])
/SPI_MISO: U1.13 (PA6), U5.2 (DO/IO1)
/SPI_MOSI: U1.14 (PA7), U5.5 (DI/IO0)
/SPI_SCK: U1.12 (PA5), U5.6 (CLK)
/STRAIN_DRDY: U1.17 (PA12[PA10]), U4.12 (DRDY)
/SWCLK: J2.4 (SWCLK), U1.19 (PA15/PA14-BOOT0)
/SWDIO: J2.3 (SWDIO), U1.18 (PA13)
/UART_RX: J2.6 (UART_RX), U1.10 (PA3)
/UART_TX: J2.5 (UART_TX), U1.9 (PA2)
/VBAT: C9.1, C12.1, J1.1, R4.1, U6.3 (VBAT), U7.1 (IN), U7.3 (EN)
/VBAT_SENSE: C14.1, R4.2, R5.1, U1.8 (PA1)
/VBG: C7.1, U4.6 (VBG)

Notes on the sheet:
SMART APO + SMART UNDERWATER Rev.A2
Common core; Population=BOTH/AWA/UNDERWATER controls assembly variant

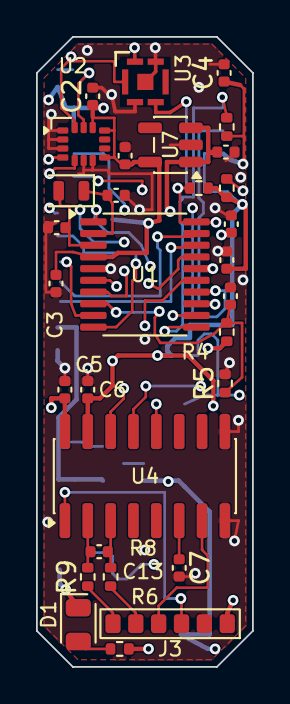
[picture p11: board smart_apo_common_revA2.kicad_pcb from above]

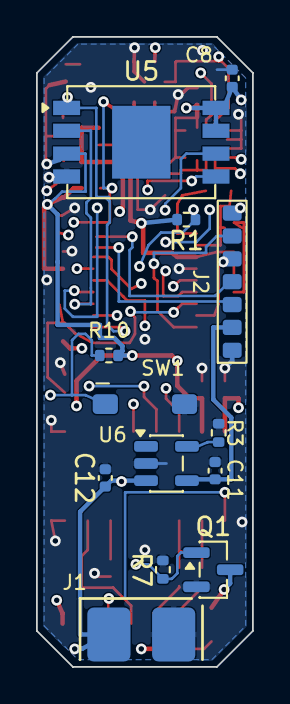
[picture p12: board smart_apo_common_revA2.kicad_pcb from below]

Board: 4 copper layers, 12.0 x 35.0 mm, 43 parts (13 on the bottom side), 33 nets.

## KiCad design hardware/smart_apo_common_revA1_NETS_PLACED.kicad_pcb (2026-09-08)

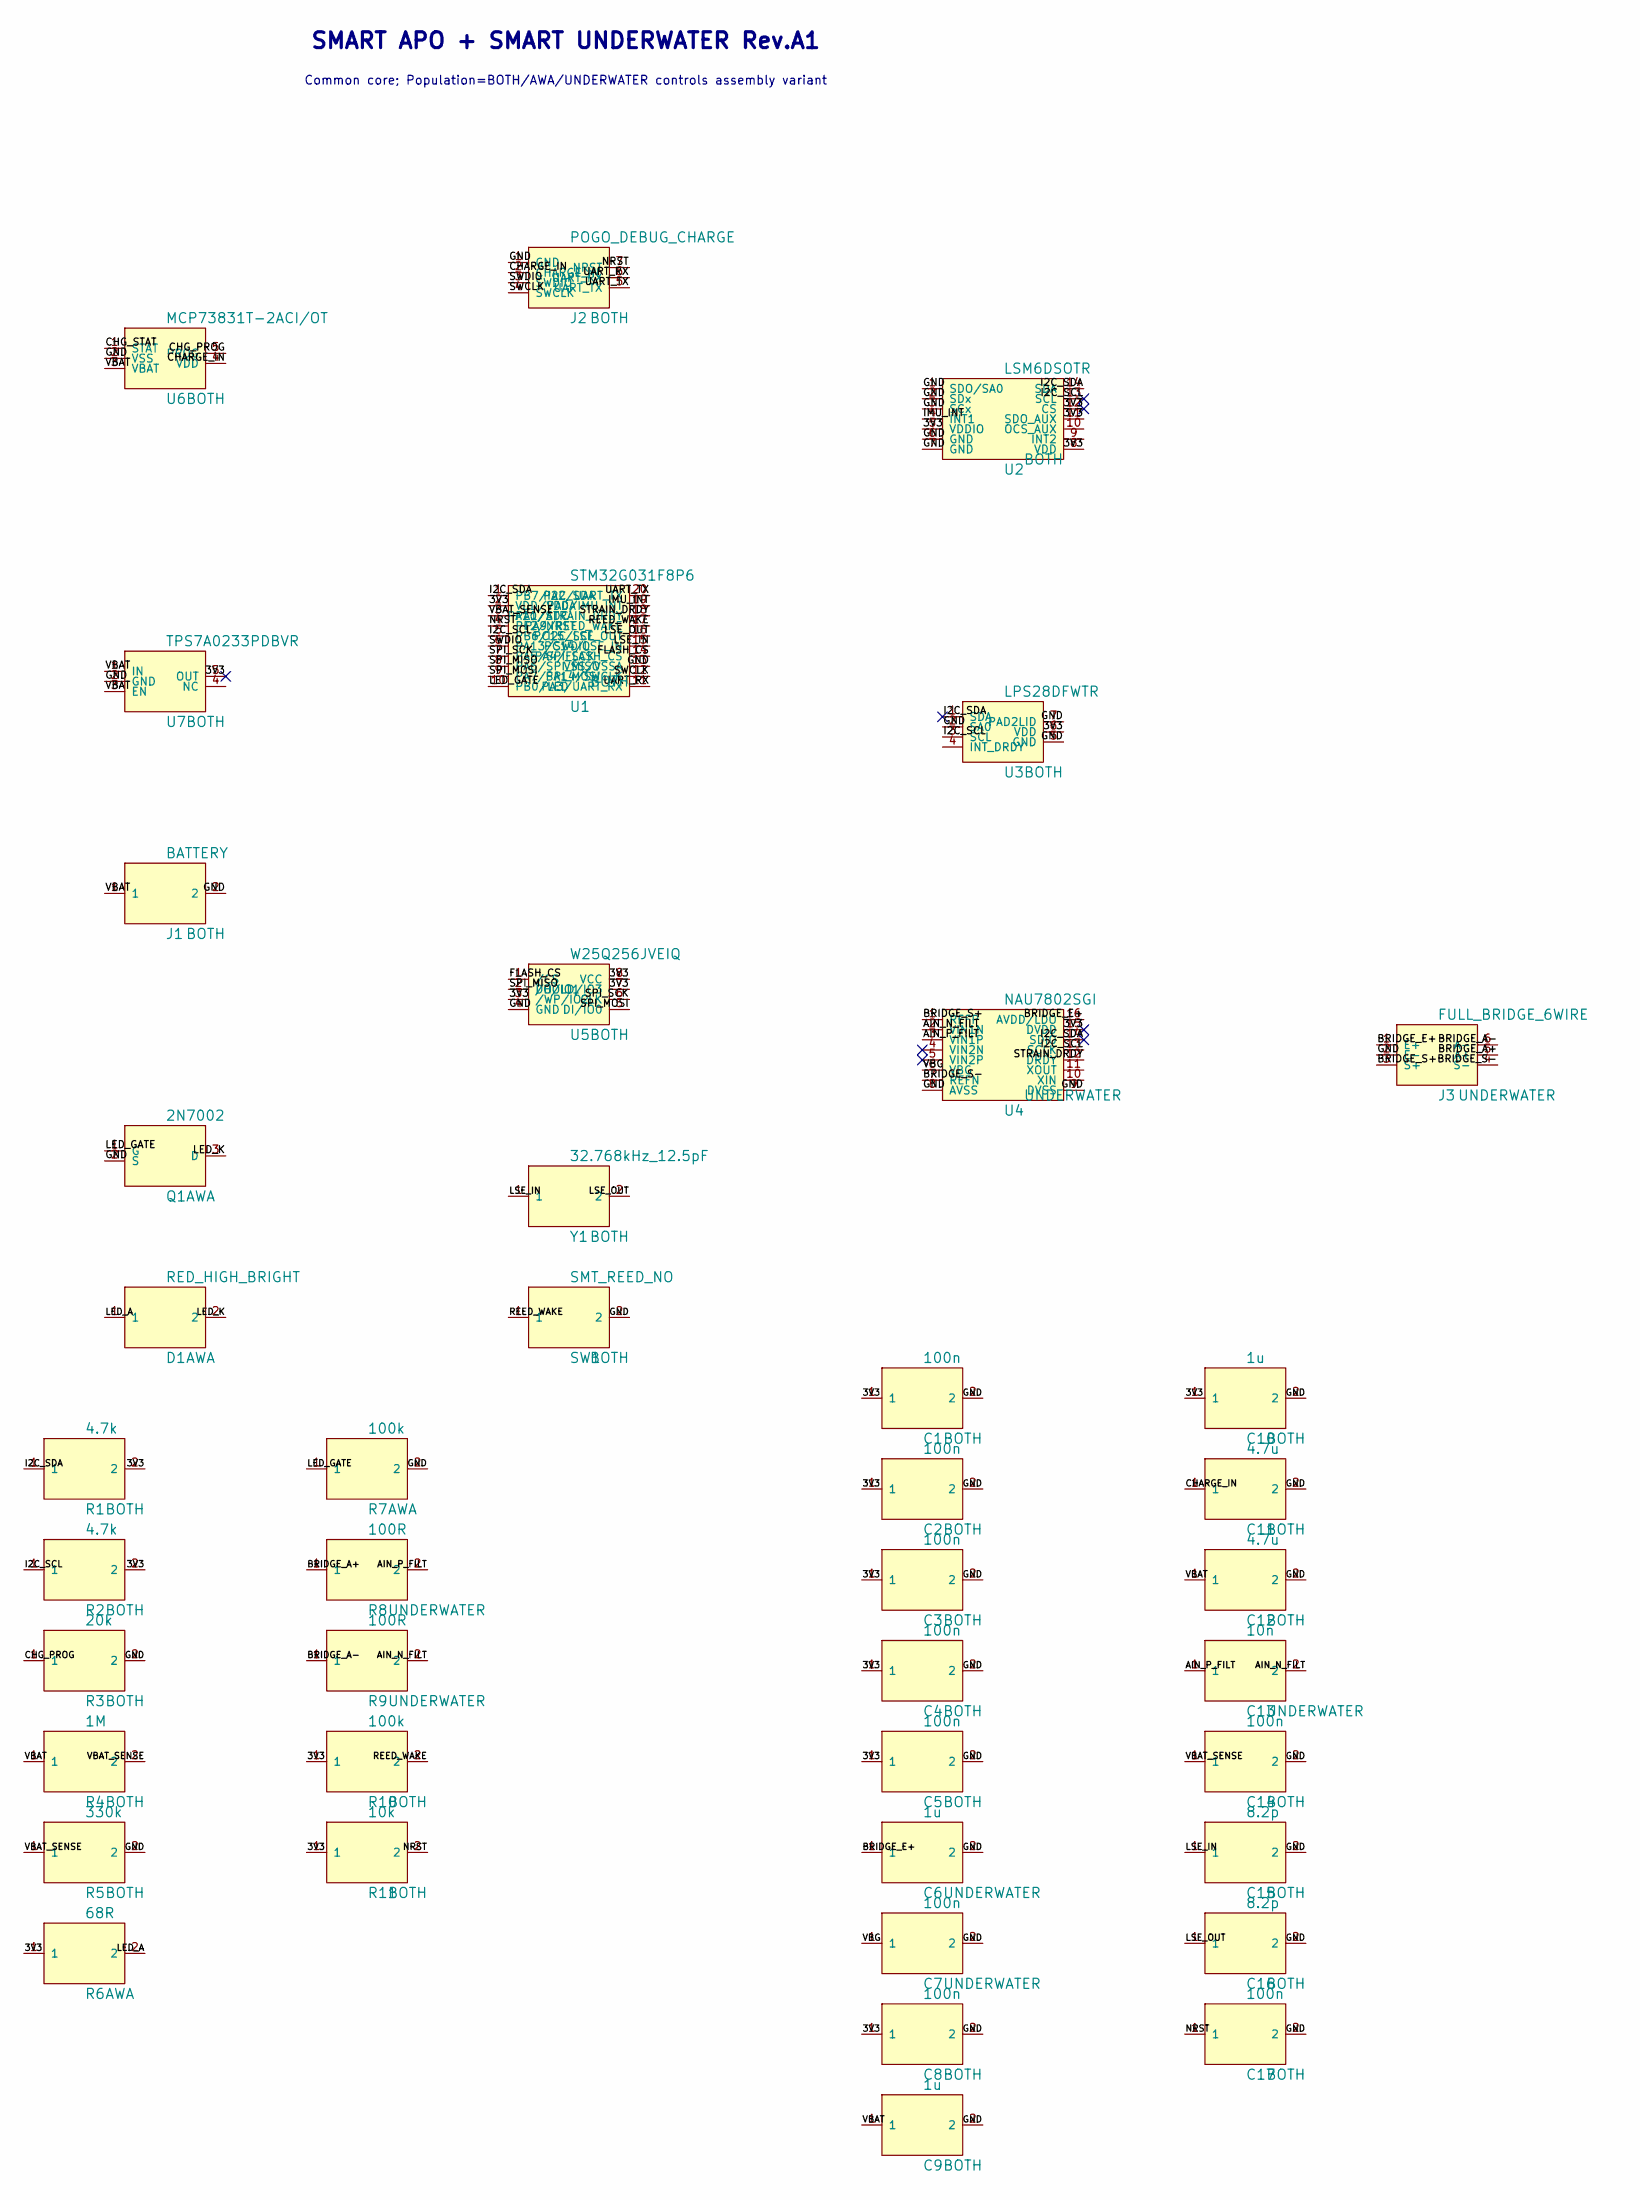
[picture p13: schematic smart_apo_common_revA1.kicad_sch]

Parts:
C1, C2, C3, C4, C5, C7, C8, C14, C17: 100n; C_0402_1005Metric
C6, C9, C10: 1u; C_0402_1005Metric
C11, C12: 4.7u; C_0402_1005Metric
C13: 10n; C_0402_1005Metric
C15, C16: 8.2p; C_0402_1005Metric
D1: RED_HIGH_BRIGHT; LED_0805_2012Metric
J1: BATTERY; SolderWire-1sqmm_1x02_P3.9mm_D1.4mm_OD2.7mm
J2: POGO_DEBUG_CHARGE; POGO_7x1.27mm
J3: FULL_BRIDGE_6WIRE; PAD_6x1.27mm
Q1: 2N7002; SOT-23
R1, R2: 4.7k; R_0402_1005Metric
R3: 20k; R_0402_1005Metric
R4: 1M; R_0402_1005Metric
R5: 330k; R_0402_1005Metric
R6: 68R; R_0402_1005Metric
R7, R10: 100k; R_0402_1005Metric
R8, R9: 100R; R_0402_1005Metric
R11: 10k; R_0402_1005Metric
SW1: SMT_REED_NO; SW_SPST_MK16
U1: STM32G031F8P6; TSSOP-20_4.4x6.5mm_P0.65mm
U2: LSM6DSOTR; LGA-14_2.5x3mm_P0.5mm
U3: LPS28DFWTR; CCLGA-7_LPS28DFW
U4: NAU7802SGI; SOIC-16_3.9x9.9mm_P1.27mm
U5: W25Q256JVEIQ; WSON-8-1EP_6x8mm_P1.27mm
U6: MCP73831T-2ACI/OT; SOT-23-5
U7: TPS7A0233PDBVR; SOT-23-5
Y1: 32.768kHz_12.5pF; Crystal_SMD_2012-2Pin_2.0x1.2mm

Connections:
3V3: C1.1, C2.1, C3.1, C4.1, C5.1, C8.1, C10.1, R1.2, R2.2, R6.1, R10.1, R11.1, U1.2 (VDD/VDDA), U2.5 (VDDIO), U2.8 (VDD), U2.11 (SDO_AUX), U2.12 (CS), U3.6 (VDD), U4.15 (DVDD), U5.3 (/WP/IO2), U5.7 (/HOLD/IO3), U5.8 (VCC), U7.5 (OUT)
AIN_N_FILT: C13.2, R9.2, U4.2 (VIN1N)
AIN_P_FILT: C13.1, R8.2, U4.3 (VIN1P)
BRIDGE_A+: J3.5 (A+), R8.1
BRIDGE_A-: J3.6 (A-), R9.1
BRIDGE_E+: C6.1, J3.1 (E+), U4.16 (AVDD/LDO)
BRIDGE_S+: J3.3 (S+), U4.1 (REFP)
BRIDGE_S-: J3.4 (S-), U4.7 (REFN)
CHARGE_IN: C11.1, J2.2 (CHARGE_IN), U6.4 (VDD)
CHG_PROG: R3.1, U6.5 (PROG)
CHG_STAT: U6.1 (STAT)
FLASH_CS: U1.14 (PA4/FLASH_CS), U5.1 (/CS)
GND: C1.2, C2.2, C3.2, C4.2, C5.2, C6.2, C7.2, C8.2, C9.2, C10.2, C11.2, C12.2, C14.2, C15.2, C16.2, C17.2, J1.2, J2.1 (GND), J3.2 (E-), Q1.2 (S), R3.2, R5.2, R7.2, SW1.2, U1.13 (VSS/VSSA), U2.1 (SDO/SA0), U2.2 (SDx), U2.3 (SCx), U2.6 (GND), U2.7 (GND), U3.2 (SA0), U3.5 (GND), U3.7 (PAD2LID), U4.8 (AVSS), U4.9 (DVSS), U5.4 (GND), U6.2 (VSS), U7.2 (GND)
I2C_SCL: R2.1, U1.5 (PB6/I2C_SCL), U2.13 (SCL), U3.3 (SCL), U4.13 (SCLK)
I2C_SDA: R1.1, U1.1 (PB7/I2C_SDA), U2.14 (SDA), U3.1 (SDA), U4.14 (SDIO)
IMU_INT: U1.19 (PA0/IMU_INT), U2.4 (INT1)
LED_A: D1.1, R6.2
LED_GATE: Q1.1 (G), R7.1, U1.10 (PB0/LED)
LED_K: D1.2, Q1.3 (D)
LSE_IN: C15.1, U1.15 (PC14/LSE_IN), Y1.1
LSE_OUT: C16.1, U1.16 (PC15/LSE_OUT), Y1.2
NRST: C17.1, J2.7 (NRST), R11.2, U1.4 (PF2/NRST)
REED_WAKE: R10.2, SW1.1, U1.17 (PA9/REED_WAKE)
SPI_MISO: U1.8 (PA6/SPI_MISO), U5.2 (DO/IO1)
SPI_MOSI: U1.9 (PA7/SPI_MOSI), U5.5 (DI/IO0)
SPI_SCK: U1.7 (PA5/SPI_SCK), U5.6 (CLK)
STRAIN_DRDY: U1.18 (PA10/STRAIN_DRDY), U4.12 (DRDY)
SWCLK: J2.4 (SWCLK), U1.12 (PA14/SWCLK)
SWDIO: J2.3 (SWDIO), U1.6 (PA13/SWDIO)
UART_RX: J2.6 (UART_RX), U1.11 (PA3/UART_RX)
UART_TX: J2.5 (UART_TX), U1.20 (PA2/UART_TX)
VBAT: C9.1, C12.1, J1.1, R4.1, U6.3 (VBAT), U7.1 (IN), U7.3 (EN)
VBAT_SENSE: C14.1, R4.2, R5.1, U1.3 (PA1/ADC)
VBG: C7.1, U4.6 (VBG)

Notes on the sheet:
SMART APO + SMART UNDERWATER Rev.A1
Common core; Population=BOTH/AWA/UNDERWATER controls assembly variant

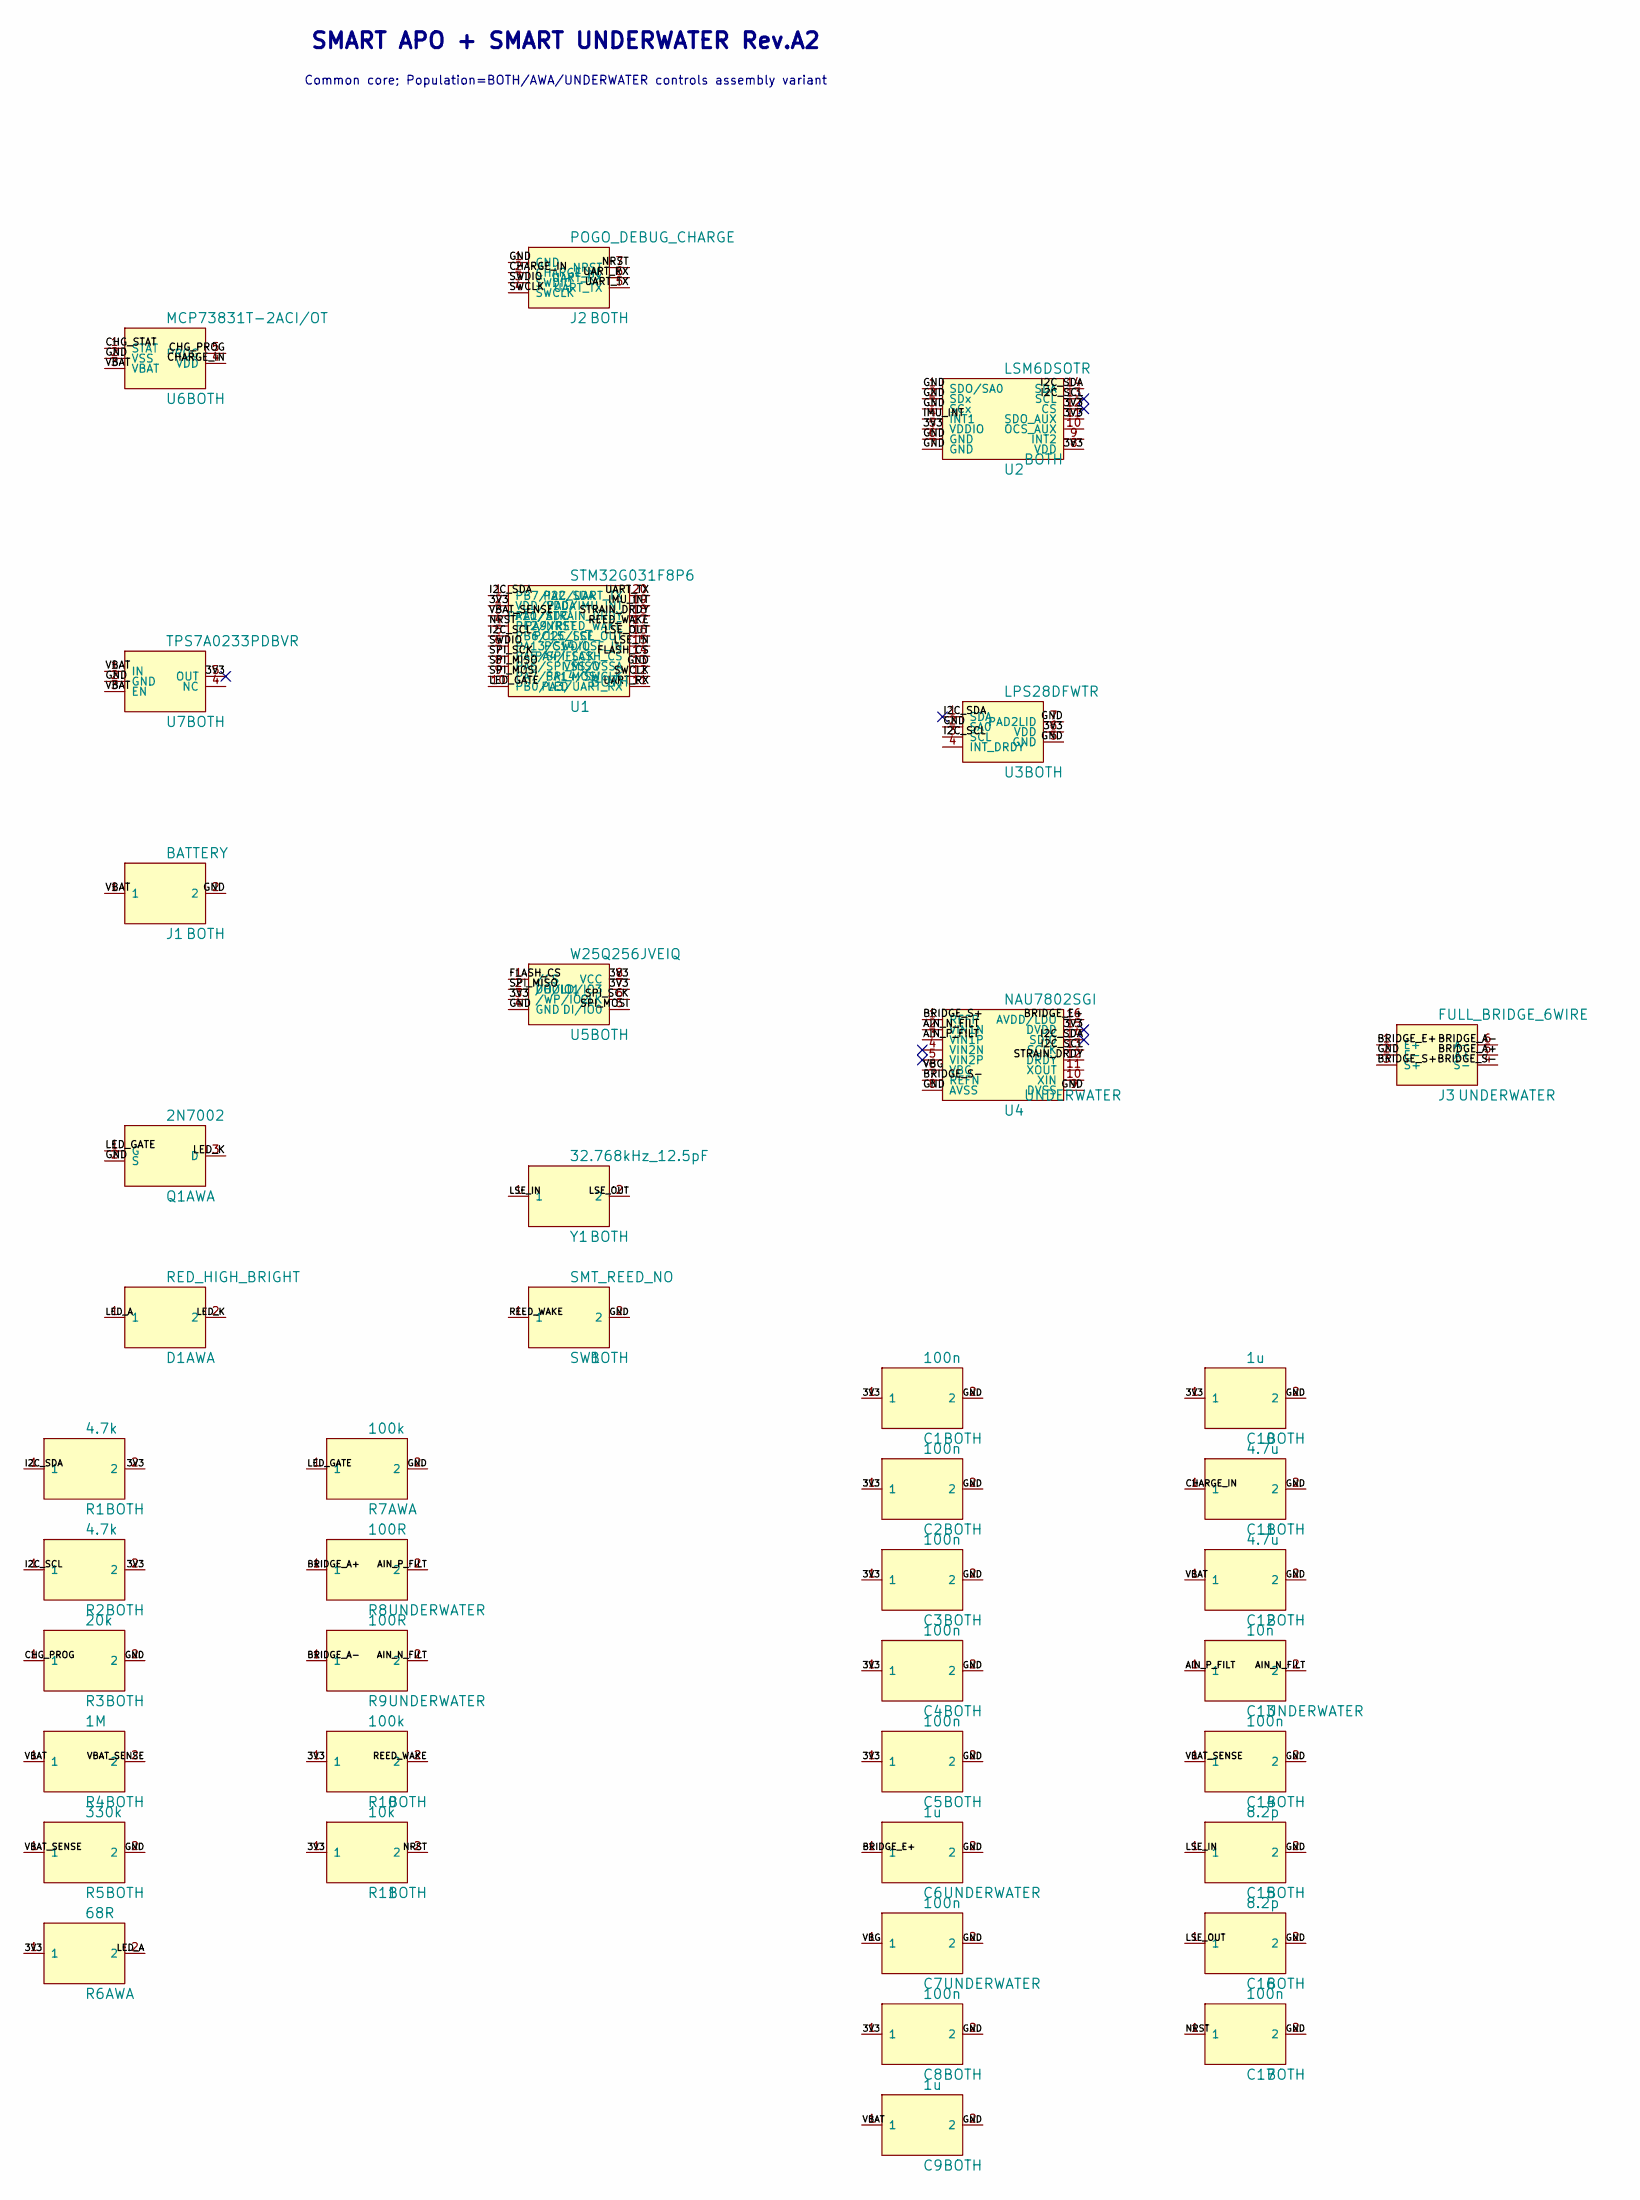
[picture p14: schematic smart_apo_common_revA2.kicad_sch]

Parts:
C1, C2, C3, C4, C5, C7, C8, C14, C17: 100n; C_0402_1005Metric
C6, C9, C10: 1u; C_0402_1005Metric
C11, C12: 4.7u; C_0402_1005Metric
C13: 10n; C_0402_1005Metric
C15, C16: 8.2p; C_0402_1005Metric
D1: RED_HIGH_BRIGHT; LED_0805_2012Metric
J1: BATTERY; SolderWire-1sqmm_1x02_P3.9mm_D1.4mm_OD2.7mm
J2: POGO_DEBUG_CHARGE; POGO_7x1.27mm
J3: FULL_BRIDGE_6WIRE; PAD_6x1.27mm
Q1: 2N7002; SOT-23
R1, R2: 4.7k; R_0402_1005Metric
R3: 20k; R_0402_1005Metric
R4: 1M; R_0402_1005Metric
R5: 330k; R_0402_1005Metric
R6: 68R; R_0402_1005Metric
R7, R10: 100k; R_0402_1005Metric
R8, R9: 100R; R_0402_1005Metric
R11: 10k; R_0402_1005Metric
SW1: SMT_REED_NO; SW_SPST_MK16
U1: STM32G031F8P6; TSSOP-20_4.4x6.5mm_P0.65mm
U2: LSM6DSOTR; LGA-14_2.5x3mm_P0.5mm
U3: LPS28DFWTR; CCLGA-7_LPS28DFW
U4: NAU7802SGI; SOIC-16_3.9x9.9mm_P1.27mm
U5: W25Q256JVEIQ; WSON-8-1EP_6x8mm_P1.27mm
U6: MCP73831T-2ACI/OT; SOT-23-5
U7: TPS7A0233PDBVR; SOT-23-5
Y1: 32.768kHz_12.5pF; Crystal_SMD_2012-2Pin_2.0x1.2mm

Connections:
3V3: C1.1, C2.1, C3.1, C4.1, C5.1, C8.1, C10.1, R1.2, R2.2, R6.1, R10.1, R11.1, U1.2 (VDD/VDDA), U2.5 (VDDIO), U2.8 (VDD), U2.11 (SDO_AUX), U2.12 (CS), U3.6 (VDD), U4.15 (DVDD), U5.3 (/WP/IO2), U5.7 (/HOLD/IO3), U5.8 (VCC), U7.5 (OUT)
AIN_N_FILT: C13.2, R9.2, U4.2 (VIN1N)
AIN_P_FILT: C13.1, R8.2, U4.3 (VIN1P)
BRIDGE_A+: J3.5 (A+), R8.1
BRIDGE_A-: J3.6 (A-), R9.1
BRIDGE_E+: C6.1, J3.1 (E+), U4.16 (AVDD/LDO)
BRIDGE_S+: J3.3 (S+), U4.1 (REFP)
BRIDGE_S-: J3.4 (S-), U4.7 (REFN)
CHARGE_IN: C11.1, J2.2 (CHARGE_IN), U6.4 (VDD)
CHG_PROG: R3.1, U6.5 (PROG)
CHG_STAT: U6.1 (STAT)
FLASH_CS: U1.14 (PA4/FLASH_CS), U5.1 (/CS)
GND: C1.2, C2.2, C3.2, C4.2, C5.2, C6.2, C7.2, C8.2, C9.2, C10.2, C11.2, C12.2, C14.2, C15.2, C16.2, C17.2, J1.2, J2.1 (GND), J3.2 (E-), Q1.2 (S), R3.2, R5.2, R7.2, SW1.2, U1.13 (VSS/VSSA), U2.1 (SDO/SA0), U2.2 (SDx), U2.3 (SCx), U2.6 (GND), U2.7 (GND), U3.2 (SA0), U3.5 (GND), U3.7 (PAD2LID), U4.8 (AVSS), U4.9 (DVSS), U5.4 (GND), U6.2 (VSS), U7.2 (GND)
I2C_SCL: R2.1, U1.5 (PB6/I2C_SCL), U2.13 (SCL), U3.3 (SCL), U4.13 (SCLK)
I2C_SDA: R1.1, U1.1 (PB7/I2C_SDA), U2.14 (SDA), U3.1 (SDA), U4.14 (SDIO)
IMU_INT: U1.19 (PA0/IMU_INT), U2.4 (INT1)
LED_A: D1.1, R6.2
LED_GATE: Q1.1 (G), R7.1, U1.10 (PB0/LED)
LED_K: D1.2, Q1.3 (D)
LSE_IN: C15.1, U1.15 (PC14/LSE_IN), Y1.1
LSE_OUT: C16.1, U1.16 (PC15/LSE_OUT), Y1.2
NRST: C17.1, J2.7 (NRST), R11.2, U1.4 (PF2/NRST)
REED_WAKE: R10.2, SW1.1, U1.17 (PA9/REED_WAKE)
SPI_MISO: U1.8 (PA6/SPI_MISO), U5.2 (DO/IO1)
SPI_MOSI: U1.9 (PA7/SPI_MOSI), U5.5 (DI/IO0)
SPI_SCK: U1.7 (PA5/SPI_SCK), U5.6 (CLK)
STRAIN_DRDY: U1.18 (PA10/STRAIN_DRDY), U4.12 (DRDY)
SWCLK: J2.4 (SWCLK), U1.12 (PA14/SWCLK)
SWDIO: J2.3 (SWDIO), U1.6 (PA13/SWDIO)
UART_RX: J2.6 (UART_RX), U1.11 (PA3/UART_RX)
UART_TX: J2.5 (UART_TX), U1.20 (PA2/UART_TX)
VBAT: C9.1, C12.1, J1.1, R4.1, U6.3 (VBAT), U7.1 (IN), U7.3 (EN)
VBAT_SENSE: C14.1, R4.2, R5.1, U1.3 (PA1/ADC)
VBG: C7.1, U4.6 (VBG)

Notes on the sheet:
SMART APO + SMART UNDERWATER Rev.A2
Common core; Population=BOTH/AWA/UNDERWATER controls assembly variant

Board: 4 copper layers, 42 parts (8 on the bottom side), 33 nets, no tracks yet.

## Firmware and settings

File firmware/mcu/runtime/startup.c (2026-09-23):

/* Review-only C startup, independent implementation for STM32G031F8.
 * Vector order: ST cmsis-device-g0 startup_stm32g031xx.s (see report).
 * Reset clock configuration is retained. No HAL, C++ constructors or heap.
 * Hardware driver initialization remains in app_boot and is not complete.
 */
#include <stdint.h>
extern uint32_t _estack, _sidata, _sdata, _edata, _sbss, _ebss;
extern int main(void);
void Default_Handler(void) { for (;;) {} }
void Reset_Handler(void)
{
    volatile uint32_t *dst = &_sdata;
    const uint32_t *src = &_sidata;
    while (dst < &_edata) *dst++ = *src++;
    for (dst = &_sbss; dst < &_ebss; ++dst) *dst = 0;
    (void)main();
    Default_Handler();
}
void NMI_Handler(void) __attribute__((weak, alias("Default_Handler")));
void HardFault_Handler(void) __attribute__((weak, alias("Default_Handler")));
void SVC_Handler(void) __attribute__((weak, alias("Default_Handler")));
void PendSV_Handler(void) __attribute__((weak, alias("Default_Handler")));
void SysTick_Handler(void) __attribute__((weak, alias("Default_Handler")));
void WWDG_IRQHandler(void) __attribute__((weak, alias("Default_Handler")));
void PVD_IRQHandler(void) __attribute__((weak, alias("Default_Handler")));
void RTC_TAMP_IRQHandler(void) __attribute__((weak, alias("Default_Handler")));
void FLASH_IRQHandler(void) __attribute__((weak, alias("Default_Handler")));
void RCC_IRQHandler(void) __attribute__((weak, alias("Default_Handler")));
void EXTI0_1_IRQHandler(void) __attribute__((weak, alias("Default_Handler")));
void EXTI2_3_IRQHandler(void) __attribute__((weak, alias("Default_Handler")));
void EXTI4_15_IRQHandler(void) __attribute__((weak, alias("Default_Handler")));
void DMA1_Channel1_IRQHandler(void) __attribute__((weak, alias("Default_Handler")));
void DMA1_Channel2_3_IRQHandler(void) __attribute__((weak, alias("Default_Handler")));
void DMA1_Ch4_5_DMAMUX1_OVR_IRQHandler(void) __attribute__((weak, alias("Default_Handler")));
void ADC1_IRQHandler(void) __attribute__((weak, alias("Default_Handler")));
void TIM1_BRK_UP_TRG_COM_IRQHandler(void) __attribute__((weak, alias("Default_Handler")));
void TIM1_CC_IRQHandler(void) __attribute__((weak, alias("Default_Handler")));
void TIM2_IRQHandler(void) __attribute__((weak, alias("Default_Handler")));
void TIM3_IRQHandler(void) __attribute__((weak, alias("Default_Handler")));
void LPTIM1_IRQHandler(void) __attribute__((weak, alias("Default_Handler")));
void LPTIM2_IRQHandler(void) __attribute__((weak, alias("Default_Handler")));
void TIM14_IRQHandler(void) __attribute__((weak, alias("Default_Handler")));
void TIM16_IRQHandler(void) __attribute__((weak, alias("Default_Handler")));
void TIM17_IRQHandler(void) __attribute__((weak, alias("Default_Handler")));
void I2C1_IRQHandler(void) __attribute__((weak, alias("Default_Handler")));
void I2C2_IRQHandler(void) __attribute__((weak, alias("Default_Handler")));
void SPI1_IRQHandler(void) __attribute__((weak, alias("Default_Handler")));
void SPI2_IRQHandler(void) __attribute__((weak, alias("Default_Handler")));
void USART1_IRQHandler(void) __attribute__((weak, alias("Default_Handler")));
void USART2_IRQHandler(void) __attribute__((weak, alias("Default_Handler")));
void LPUART1_IRQHandler(void) __attribute__((weak, alias("Default_Handler")));
__attribute__((section(".isr_vector"), used, aligned(256)))
const uintptr_t vectors[] = {
    (uintptr_t)&_estack, (uintptr_t)Reset_Handler,
    (uintptr_t)NMI_Handler,
    (uintptr_t)HardFault_Handler,
    0,
    0,
    0,
    0,
    0,
    0,
    0,
    (uintptr_t)SVC_Handler,
    0,
    0,
    (uintptr_t)PendSV_Handler,
    (uintptr_t)SysTick_Handler,
    (uintptr_t)WWDG_IRQHandler,
    (uintptr_t)PVD_IRQHandler,
    (uintptr_t)RTC_TAMP_IRQHandler,
    (uintptr_t)FLASH_IRQHandler,
    (uintptr_t)RCC_IRQHandler,
    (uintptr_t)EXTI0_1_IRQHandler,
    (uintptr_t)EXTI2_3_IRQHandler,
    (uintptr_t)EXTI4_15_IRQHandler,
    0,
    (uintptr_t)DMA1_Channel1_IRQHandler,
    (uintptr_t)DMA1_Channel2_3_IRQHandler,
    (uintptr_t)DMA1_Ch4_5_DMAMUX1_OVR_IRQHandler,
    (uintptr_t)ADC1_IRQHandler,
    (uintptr_t)TIM1_BRK_UP_TRG_COM_IRQHandler,
    (uintptr_t)TIM1_CC_IRQHandler,
    (uintptr_t)TIM2_IRQHandler,
    (uintptr_t)TIM3_IRQHandler,
    (uintptr_t)LPTIM1_IRQHandler,
    (uintptr_t)LPTIM2_IRQHandler,
    (uintptr_t)TIM14_IRQHandler,
    0,
    (uintptr_t)TIM16_IRQHandler,
    (uintptr_t)TIM17_IRQHandler,
    (uintptr_t)I2C1_IRQHandler,
    (uintptr_t)I2C2_IRQHandler,
    (uintptr_t)SPI1_IRQHandler,
    (uintptr_t)SPI2_IRQHandler,
    (uintptr_t)USART1_IRQHandler,
    (uintptr_t)USART2_IRQHandler,
    (uintptr_t)LPUART1_IRQHandler,
    0,
};
_Static_assert(sizeof(vectors) == 188, "STM32G031 has 47 vector entries");

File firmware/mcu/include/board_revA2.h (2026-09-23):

#ifndef BOARD_REVA2_H
#define BOARD_REVA2_H

#include <stdint.h>

/* STM32G031F8P6 TSSOP20 pin map for Smart Apo Rev.A2.
 * Physical pin order is from ST DS12992 Rev 4 Figure 5, not Rev.A1's
 * incorrect 1-20 logical mapping.
 *
 * CubeMX is not installed here. These constants are for a future HAL/LL
 * project and for code review against the schematic netlist.
 */

#define SMART_APO_VARIANT_AWA 0
#define SMART_APO_VARIANT_UW  1

#ifndef SMART_APO_VARIANT
#define SMART_APO_VARIANT SMART_APO_VARIANT_AWA
#endif

/* SYSCFG_CFGR1 bits from RM0444 Rev 6. Set both before using PA9/PA10. */
#define SMART_APO_SYSCFG_PA11_RMP (1u << 3)
#define SMART_APO_SYSCFG_PA12_RMP (1u << 4)

#define PIN_I2C_SDA        1u  /* PB7, I2C1 SDA AF6 */
#define PIN_LSE_IN         2u  /* PC14 */
#define PIN_LSE_OUT        3u  /* PC15 */
#define PIN_3V3            4u
#define PIN_GND            5u
#define PIN_NRST           6u
#define PIN_IMU_INT        7u  /* PA0 EXTI */
#define PIN_VBAT_SENSE     8u  /* PA1 ADC */
#define PIN_UART_TX        9u  /* PA2 USART2 AF1 */
#define PIN_UART_RX       10u  /* PA3 USART2 AF1 */
#define PIN_FLASH_CS      11u  /* PA4 GPIO; R12 10k pull-up to 3V3 */
#define PIN_SPI_SCK       12u  /* PA5 SPI1 AF0 */
#define PIN_SPI_MISO      13u  /* PA6 SPI1 AF0 */
#define PIN_SPI_MOSI      14u  /* PA7 SPI1 AF0 */
#define PIN_LED_GATE      15u  /* PB0 GPIO */
#define PIN_REED_WAKE     16u  /* PA9 after PA11_RMP */
#define PIN_STRAIN_DRDY   17u  /* PA10 after PA12_RMP */
#define PIN_SWDIO         18u  /* PA13, do not reassign */
#define PIN_SWCLK         19u  /* PA14, do not reassign */
#define PIN_I2C_SCL       20u  /* PB6, I2C1 SCL AF6 */

#define I2C_ADDR_LSM6DSO_SA0_GND  0x6Au
#define I2C_ADDR_LPS28DFW         0x5Cu
#define I2C_ADDR_NAU7802          0x2Au

#define ODR_IMU_AWA_HZ      104u
#define ODR_IMU_UW_HZ       208u
#define ODR_PRESS_AWA_HZ     50u
#define ODR_PRESS_UW_HZ     100u
#define ODR_STRAIN_UW_SPS   320u
#define ODR_BATT_HZ           1u

#define LSE_STARTUP_TIMEOUT_MS  2000u
#define LSE_STARTUP_TIMEOUT_US  (LSE_STARTUP_TIMEOUT_MS * 1000u)

/* SW1 is NO to GND; R10 100 kΩ pulls REED_WAKE to 3V3. Closed = 0.
 * Long press in RECORD enters DUMP. EXTI9 rising pending records release;
 * currently polled only, not a Stop wake source. Configure after PA11_RMP.
 */
#define REED_CLOSED_LEVEL       0
#define REED_HOLD_SLEEP_MS      1500u
#define REED_EXTI_LINE          9u
#define IMU_EXTI_LINE           0u  /* PA0, LSM6DSO INT1, default active-high */
#define EXTI_BASE_G0            0x40021800u
#define EXTI_RTSR1_OFF          0x00u
#define EXTI_FTSR1_OFF          0x04u
#define EXTI_RPR1_OFF           0x0Cu
#define EXTI_FPR1_OFF           0x10u
#define EXTI_EXTICR1_OFF        0x60u
#define EXTI_EXTICR3_OFF        0x68u
#define EXTI_IMR1_OFF           0x80u

/* R4=180 kΩ VBAT→VBAT_SENSE, R5=60.4 kΩ to GND. STM32G031 12-bit ADC, VDDA=3.3 V.
 * mV = adc * 3300 * 240400 / (60400 * 4095) = adc * 132220 / 41223.
 * Worst 1% Thevenin resistance is <50 kΩ; VREF/analog accuracy remain unverified.
 */
#define VBAT_R_TOP_OHM      180000u
#define VBAT_R_BOT_OHM       60400u
#define ADC_VREF_MV           3300u
#define ADC_FULL_COUNTS       4095u
#define VBAT_MV_NUM         132220u
#define VBAT_MV_DEN          41223u
/* From boot TIM2 epoch, nonblocking. R/C/HSI assumptions in startup report. */
#define VBAT_STARTUP_SETTLE_US 100000u

/* USART2 on PA2/PA3 AF1. Do not use PA9/PA10 (those are reed/DRDY after remap).
 * RM0444: USART2 0x40004400, APBENR1 USART2EN bit 17, IOPENR GPIOAEN bit 0.
 * 115200 8N1. With default HSI 16 MHz and OVER8=0, BRR ≈ 139.
 */
#define USART2_BASE_G0       0x40004400u
#define USART2_AF            1u
#define USART2_BAUD          115200u
#define USART2_HSI16_BRR     139u
#define RCC_IOPENR_G0        0x40021034u
#define RCC_APBENR1_G0       0x4002103Cu
#define RCC_APBENR2_G0       0x40021040u
#define RCC_GPIOAEN          (1u << 0)
#define RCC_GPIOBEN          (1u << 1)
#define RCC_USART2EN         (1u << 17)
#define RCC_I2C1EN           (1u << 21)
#define RCC_SPI1EN           (1u << 12)
#define SPI1_BASE_G0         0x40013000u
#define SPI1_AF              0u /* PA5/PA6/PA7 AF0, mode 0 for W25Q256 */
#define I2C1_BASE_G0         0x40005400u
#define I2C1_AF              6u /* PB6 SCL / PB7 SDA AF6, open-drain */
#define I2C1_HSI16_TIMINGR   0x10A2272Fu /* conservative Standard-mode @ PCLK16; see VERIFICATION_I2C_CN.md */
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

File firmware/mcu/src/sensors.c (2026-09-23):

#include "sensors.h"
#include "datalog.h"

#include <string.h>

/* Fractional phases preserve exact nominal ODR without truncating periods.
 * One poll may read only the current conversion, never fabricate past samples.
 */
static uint32_t g_phase[4], g_last_poll_us;
static int g_started, g_clock_fault;
static sensors_timing_stats_t g_timing;

void sensors_timing_stats(sensors_timing_stats_t *out)
{
    if (out) *out = g_timing;
}

static int channel_due(unsigned channel, unsigned hz, uint32_t elapsed, int first)
{
    uint64_t phase = g_phase[channel] + (uint64_t)elapsed * hz;
    uint32_t slots = (uint32_t)(phase / 1000000u);
    g_phase[channel] = (uint32_t)(phase % 1000000u);
    if (slots > 1u) {
        uint32_t missed = slots - 1u;
        uint32_t *count = &g_timing.skipped_slots[channel];
        *count = UINT32_MAX - *count < missed ? UINT32_MAX : *count + missed;
    }
    return first || slots != 0u;
}

static int i2c_write_u8(uint8_t addr7, uint8_t reg, uint8_t value)
{
    return board_i2c1_write_u8(addr7, reg, value);
}

static int i2c_read_n(uint8_t addr7, uint8_t reg, uint8_t *buf, unsigned n)
{
    return board_i2c1_read_n(addr7, reg, buf, n);
}

static int i2c_read_u8(uint8_t addr7, uint8_t reg, uint8_t *value)
{
    return i2c_read_n(addr7, reg, value, 1);
}

static int16_t le16(const uint8_t *p)
{
    return (int16_t)((uint16_t)p[0] | ((uint16_t)p[1] << 8));
}

static int32_t le24_sign(const uint8_t *p)
{
    uint32_t u = (uint32_t)p[0] | ((uint32_t)p[1] << 8) | ((uint32_t)p[2] << 16);
    if (u & 0x800000u) {
        u |= 0xFF000000u;
    }
    return (int32_t)u;
}

static int32_t be24_sign(const uint8_t *p)
{
    uint32_t u = ((uint32_t)p[0] << 16) | ((uint32_t)p[1] << 8) | (uint32_t)p[2];
    if (u & 0x800000u) {
        u |= 0xFF000000u;
    }
    return (int32_t)u;
}

static int lsm6dso_read_sample(smart_apo_sample_t *out)
{
    uint8_t buf[14];
    int16_t t_raw;

    /* DS12754: OUT_TEMP_L..OUTZ_H_A with IF_INC. Gyro then accel. */
    if (i2c_read_n(I2C_ADDR_LSM6DSO_SA0_GND, LSM6DSO_OUT_TEMP_L, buf, 14) != 0) {
        return -1;
    }
    t_raw = le16(buf);
    out->temperature = (int16_t)(2500 + ((int32_t)t_raw * 100) / 256);
    out->gx = le16(buf + 2);
    out->gy = le16(buf + 4);
    out->gz = le16(buf + 6);
    out->ax = le16(buf + 8);
    out->ay = le16(buf + 10);
    out->az = le16(buf + 12);
    return 0;
}

static int lps28_read_sample(smart_apo_sample_t *out)
{
    uint8_t buf[5];

    /* DS13317: PRESS_OUT_XL..TEMP_OUT_H with IF_ADD_INC. Temp is 100 LSB/°C. */
    if (i2c_read_n(I2C_ADDR_LPS28DFW, LPS28DFW_PRESS_OUT_XL, buf, 5) != 0) {
        return -1;
    }
    out->pressure_raw = le24_sign(buf);
    out->temperature = le16(buf + 3);
    return 0;
}

static int nau7802_read_sample(smart_apo_sample_t *out)
{
    uint8_t buf[3], status;

    if (i2c_read_u8(I2C_ADDR_NAU7802, NAU7802_PU_CTRL, &status) != 0 ||
        (status & NAU7802_PU_CR) == 0u) {
        return -1; /* never mark a stale or incomplete conversion valid */
    }
    if (i2c_read_n(I2C_ADDR_NAU7802, NAU7802_ADCO_B2, buf, 3) != 0) {
        return -1;
    }
    out->tension_raw = be24_sign(buf);
    return 0;
}

static int nau7802_configure(void)
{
    uint8_t pur;

    /* V1.7 §9.1. Do not init on AWA — U4 is DNP. */
    if (i2c_write_u8(I2C_ADDR_NAU7802, NAU7802_PU_CTRL, NAU7802_PU_RR) != 0) {
        return -1;
    }
    if (i2c_write_u8(I2C_ADDR_NAU7802, NAU7802_PU_CTRL, NAU7802_PU_PUD) != 0) {
        return -1;
    }
    /* Bounded polling is fail-closed; HAL must replace counts with a timed deadline. */
    pur = 0;
    for (unsigned i = 0; i < NAU7802_READY_POLLS; ++i) {
        if (i2c_read_u8(I2C_ADDR_NAU7802, NAU7802_PU_CTRL, &pur) != 0) return -1;
        if (pur & NAU7802_PU_PUR) break;
    }
    if ((pur & NAU7802_PU_PUR) == 0u) return -1;
    if (i2c_write_u8(I2C_ADDR_NAU7802, NAU7802_PU_CTRL, NAU7802_PU_ANALOG_LDO) != 0) {
        return -1;
    }
    if (i2c_write_u8(I2C_ADDR_NAU7802, NAU7802_CTRL1, NAU7802_CTRL1_3V0_G128) != 0) {
        return -1;
    }
    if (i2c_write_u8(I2C_ADDR_NAU7802, NAU7802_CTRL2, NAU7802_CTRL2_320SPS) != 0) {
        return -1;
    }
    if (i2c_write_u8(I2C_ADDR_NAU7802, NAU7802_PU_CTRL, NAU7802_PU_RUN) != 0) {
        return -1;
    }
    /* Internal offset calibration is not beam zero/gain calibration. */
    if (i2c_write_u8(I2C_ADDR_NAU7802, NAU7802_CTRL2,
                     NAU7802_CTRL2_320SPS | NAU7802_CTRL2_CALS) != 0) return -1;
    for (unsigned i = 0; i < NAU7802_CAL_POLLS; ++i) {
        if (i2c_read_u8(I2C_ADDR_NAU7802, NAU7802_CTRL2, &pur) != 0) return -1;
        if ((pur & NAU7802_CTRL2_CALS) == 0u) {
            return (pur & NAU7802_CTRL2_CAL_ERR) ? -1 : 0;
        }
    }
    return -1;
}

static int whoami_match(uint8_t addr7, uint8_t reg, uint8_t expect)
{
    uint8_t id;

    if (i2c_read_u8(addr7, reg, &id) != 0) {
        return 0;
    }
    return id == expect;
}

int sensors_probe(sensors_status_t *st)
{
    if (st == 0) {
        return -1;
    }
    st->imu_ok = whoami_match(I2C_ADDR_LSM6DSO_SA0_GND, LSM6DSO_WHO_AM_I_REG, LSM6DSO_WHO_AM_I_VAL);
    st->press_ok = whoami_match(I2C_ADDR_LPS28DFW, LPS28DFW_WHOAMI_REG, LPS28DFW_WHOAMI_VAL);
    st->strain_ok = 0;
    /* NAU7802 has no WHO_AM_I; strain_ok is set only after configure. */
    if (!st->imu_ok && !st->press_ok) {
        return -1;
    }
    return 0;
}

int sensors_configure(sensors_status_t *st)
{
    int rc = 0;
    uint8_t xl;
    uint8_t g;
    uint8_t p1;
    uint8_t p2;

    if (st == 0) {
        return -1;
    }
    if (st->imu_ok) {
        xl = (SMART_APO_VARIANT == SMART_APO_VARIANT_UW) ? LSM6DSO_CTRL1_XL_UW : LSM6DSO_CTRL1_XL_AWA;
        g = (SMART_APO_VARIANT == SMART_APO_VARIANT_UW) ? LSM6DSO_CTRL2_G_UW : LSM6DSO_CTRL2_G_AWA;
        if (i2c_write_u8(I2C_ADDR_LSM6DSO_SA0_GND, LSM6DSO_CTRL1_XL, xl) != 0 ||
            i2c_write_u8(I2C_ADDR_LSM6DSO_SA0_GND, LSM6DSO_CTRL2_G, g) != 0 ||
            i2c_write_u8(I2C_ADDR_LSM6DSO_SA0_GND, LSM6DSO_CTRL3_C, LSM6DSO_CTRL3_C_CONFIG) != 0 ||
            i2c_write_u8(I2C_ADDR_LSM6DSO_SA0_GND, LSM6DSO_INT1_CTRL, LSM6DSO_INT1_CTRL_DRDY) != 0) {
            st->imu_ok = 0;
            rc = -1;
        }
    }
    if (st->press_ok) {
        p1 = (SMART_APO_VARIANT == SMART_APO_VARIANT_UW) ? LPS28DFW_CTRL_REG1_UW : LPS28DFW_CTRL_REG1_AWA;
        p2 = (SMART_APO_VARIANT == SMART_APO_VARIANT_UW) ? LPS28DFW_CTRL_REG2_UW : LPS28DFW_CTRL_REG2_AWA;
        if (i2c_write_u8(I2C_ADDR_LPS28DFW, LPS28DFW_CTRL_REG2, p2) != 0 ||
            i2c_write_u8(I2C_ADDR_LPS28DFW, LPS28DFW_CTRL_REG1, p1) != 0) {
            st->press_ok = 0;
            rc = -1;
        }
    }
    if (SMART_APO_VARIANT == SMART_APO_VARIANT_UW) {
        if (nau7802_configure() != 0) {
            st->strain_ok = 0;
            rc = -1;
        } else {
            st->strain_ok = 1;
        }
    }
    return rc;
}
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

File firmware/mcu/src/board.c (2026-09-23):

#include "board_revA2.h"

/* GPIO register hooks are only overridden by the host state model. */
#ifndef BOARD_GPIO_READ
#define BOARD_GPIO_READ(a) (*(volatile uint32_t *)(uintptr_t)(a))
#define BOARD_GPIO_WRITE(a, v) (*(volatile uint32_t *)(uintptr_t)(a) = (v))
#endif
#ifndef BOARD_GPIO_TIME
#define BOARD_GPIO_TIME board_time_us
#endif
#define GPIO_A 0x50000000u
#define GPIO_B 0x50000400u
#define GPIO_SYSCFG 0x40010000u
#define GPIO_REMAP (SMART_APO_SYSCFG_PA11_RMP | SMART_APO_SYSCFG_PA12_RMP)
#define GPIO_REED (1u << 9)
#define GPIO_INPUT_MODES (3u | (3u << 18) | (3u << 20))
static int gpio_ready, reed_edges_ready, reed_tracking;
static uint32_t reed_started, reed_last;

static void gpio_modify(uint32_t a, uint32_t mask, uint32_t value)
{
    BOARD_GPIO_WRITE(a, (BOARD_GPIO_READ(a) & ~mask) | value);
}

void board_enable_syscfg(void)
{
    gpio_modify(RCC_APBENR2_G0, 0u, 1u);
    (void)BOARD_GPIO_READ(RCC_APBENR2_G0);
}

void board_apply_pa9_pa10_remap(void)
{
    if ((BOARD_GPIO_READ(RCC_APBENR2_G0) & 1u) == 0u) return;
    gpio_modify(GPIO_SYSCFG, 0u, GPIO_REMAP);
    (void)BOARD_GPIO_READ(GPIO_SYSCFG);
}

static int gpio_inputs_valid(void)
{
    return gpio_ready &&
        (BOARD_GPIO_READ(RCC_IOPENR_G0) & 3u) == 3u &&
        (BOARD_GPIO_READ(RCC_APBENR2_G0) & 1u) != 0u &&
        (BOARD_GPIO_READ(GPIO_SYSCFG) & GPIO_REMAP) == GPIO_REMAP &&
        (BOARD_GPIO_READ(GPIO_A) & GPIO_INPUT_MODES) == 0u &&
        (BOARD_GPIO_READ(GPIO_A + 12u) & GPIO_INPUT_MODES) == 0u;
}

/* TIM2 belongs exclusively to this timebase. Register layout/bit positions:
 * ST stm32g031xx.h; see VERIFICATION_TIM2_CN.md for source links and limits.
 * The reset clock tree is validated, never silently assumed or changed.
 * BOARD_TIME_REG is overridden only by the register-model unit test.
 */
#ifndef BOARD_TIME_REG
#define BOARD_TIME_REG(address) (*(volatile uint32_t *)(uintptr_t)(address))
#endif
#define TIME_RCC_CR       BOARD_TIME_REG(0x40021000u)
#define TIME_RCC_ICSCR    BOARD_TIME_REG(0x40021004u)
#define TIME_RCC_CFGR     BOARD_TIME_REG(0x40021008u)
#define TIME_RCC_RESET    BOARD_TIME_REG(0x4002102Cu)
#define TIME_RCC_ENABLE   BOARD_TIME_REG(RCC_APBENR1_G0)
#define TIME_RCC_SLEEP    BOARD_TIME_REG(0x4002104Cu)
#define TIME_TIM_CR1      BOARD_TIME_REG(0x40000000u)
#define TIME_TIM_SMCR     BOARD_TIME_REG(0x40000008u)
#define TIME_TIM_DIER     BOARD_TIME_REG(0x4000000Cu)
#define TIME_TIM_SR       BOARD_TIME_REG(0x40000010u)
#define TIME_TIM_EGR      BOARD_TIME_REG(0x40000014u)
#define TIME_TIM_CNT      BOARD_TIME_REG(0x40000024u)
#define TIME_TIM_PSC      BOARD_TIME_REG(0x40000028u)
#define TIME_TIM_ARR      BOARD_TIME_REG(0x4000002Cu)
#define TIME_POLL_MAX     4096u
static int time_ready, time_attempted;
static uint32_t time_trim, time_last;

static int time_clock_valid(void)
{
    /* HSION + HSIRDY, HSIDIV=/1; SW/SWS=HSISYS; HPRE=PPRE=/1.
     * Thus nominal SYSCLK=HCLK=PCLK=TIM2CLK=16 MHz. */
    return (TIME_RCC_CR & 0x00003D00u) == 0x00000500u &&
           (TIME_RCC_CFGR & 0x00007F3Fu) == 0u;
}

static int time_config_valid(void)
{
    return time_clock_valid() && TIME_RCC_ICSCR == time_trim &&
           (TIME_RCC_ENABLE & 1u) != 0u && (TIME_RCC_RESET & 1u) == 0u &&
           (TIME_RCC_SLEEP & 1u) != 0u && TIME_TIM_CR1 == 1u &&
           TIME_TIM_SMCR == 0u && TIME_TIM_DIER == 0u &&
           TIME_TIM_PSC == 15u && TIME_TIM_ARR == UINT32_MAX;
}

static void time_start(void)
{
    unsigned i;
    uint32_t first;
    /* Re-entry may not reset an existing epoch or clear a latched fault. */
    if (time_attempted) return;
    time_attempted = 1;
    if (!time_clock_valid()) return;
    time_trim = TIME_RCC_ICSCR;
    TIME_RCC_ENABLE |= 1u;
    (void)TIME_RCC_ENABLE; /* Peripheral clock enable readback delay. */
    TIME_RCC_SLEEP |= 1u;
    TIME_RCC_RESET |= 1u;
    TIME_RCC_RESET &= ~1u;
    TIME_TIM_CR1 = 0u;
    TIME_TIM_SMCR = 0u;
    TIME_TIM_DIER = 0u;
    TIME_TIM_PSC = 15u;
    TIME_TIM_ARR = UINT32_MAX;
    TIME_TIM_EGR = 1u; /* UG loads buffered PSC and resets prescaler. */
    TIME_TIM_SR = 0u;
    TIME_TIM_CNT = 0u;
    TIME_TIM_CR1 = 1u; /* CEN, upcount, internal clock, no IRQ/DMA. */
    first = TIME_TIM_CNT;
    for (i = 0; i < TIME_POLL_MAX; ++i) {
        time_last = TIME_TIM_CNT;
        if (time_last != first) {
            time_ready = time_config_valid();
            return;
        }
    }
}

/* LSE hooks are overridden only by host register models. */
#ifndef BOARD_LSE_READ
#define BOARD_LSE_READ(a) (*(volatile uint32_t *)(uintptr_t)(a))
#define BOARD_LSE_WRITE(a, v) (*(volatile uint32_t *)(uintptr_t)(a) = (v))
#endif
#define LSE_BDCR 0x4002105Cu
#define LSE_PWR_CR1 0x40007000u
#define LSE_PWREN (1u << 28)
#define LSE_DBP (1u << 8)
#define LSE_ON 1u
#define LSE_RDY 2u
#define LSE_UNSAFE ((1u << 2) | (1u << 6) | (1u << 16))
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

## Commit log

2026-09-08 Initial commit of Smart APO revA project.
    [316L_flexure_0p30mm_revA.dxf, 316L_flexure_preview_NOT_FOR_PRINTING.stl, ASSEMBLY_VARIANTS_revA1.csv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]
2026-09-23 Preserve Rev.A2 engineering state for public collaboration
    Capture the reviewed KiCad candidate, firmware and host tooling, and current handoff documents. Exclude transient local validation snapshots and build products from the public repository.
    Constraint: Fabrication release remains blocked by assembly, sourcing, and physical verification gates
    Confidence: medium
    Scope-risk: broad
    Directive: Treat UART voyage-header changes as work in progress until end-to-end tests cover them
    Tested: 34 host tests, 8 MCU model tests, 17 tool tests, Rev.A2 structural validation, staged diff check
    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
    [BOM_revA2_WORKING.csv, smart_apo_common_revA2.kicad_pcb, smart_apo_common_revA2.kicad_sch]
2026-09-23 Make the unfinished prototype understandable to visitors
    Replace the Rev.A1-only landing page with a Rev.A2 overview, honest verification status, architecture diagram, mechanical concept image, repository map, local checks, and explicit release blockers. Keep README_CN.md as a compatibility entry point.
    Constraint: No fabricated or field-validated Rev.A2 unit exists
    Confidence: high
    Scope-risk: narrow
    Directive: Update measured status and release blockers before changing the landing-page claims
    Tested: All local README links resolve; staged diff check passes
    Not-tested: GitHub visual rendering before publication
2026-09-23 Make the budget pause visible to repository visitors
    State the user-confirmed reason for pausing the full design on the landing page and in the pause checkpoint, while preserving the independent technical release status.
    Constraint: Full prototype cost exceeds the current budget
    Tested: Staged diff whitespace check and document review
    Not-tested: No product tests rerun for documentation-only update
    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
2026-09-23 Show the proposed rig arrangement at a glance
    Add a vector concept illustration for the rod line, surface float, hook-side sensor, bait, and nearby fish. Place it near the top of the README and move the Rev.A1 mechanical preview into the design 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
    Constraint: Rig spacing, knots, ballast, and safety tether have not been physically validated
    Directive: Keep the illustration labeled as a concept, not a construction drawing
    Tested: SVG XML validation, raster render inspection, README links, staged diff check
    Not-tested: Physical rig assembly or water trials
    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
2026-09-23 Clarify each device role in the rig illustration
    Expand the surface float and hook-side sensor callouts with planned functions and principal hardware, and explain the shared-board assembly variants below the figure.
    Constraint: Neither device has been validated on assembled hardware
    Directive: Keep function descriptions qualified as design intent until physical tests exist
    Tested: SVG XML validation, raster visual inspection, README links, staged diff check
    Not-tested: Physical fishing rig or product behavior
    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
2026-09-23 Help visitors understand the paused prototype
    Reorganize the landing page around the fishing rig, each device role, evidence, local checks, and the budget pause. Use restrained humor while retaining the exact Rev.A2 release gates and unverified boundaries.
    Constraint: The full prototype remains over budget and NOT_FAB_RELEASED
    Directive: Keep jokes separate from measured claims and update snapshot numbers only with new evidence
    Tested: README links resolve, Markdown fences pair, staged diff check
    Not-tested: No PCB or firmware tests rerun for documentation-only changes
    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
2026-09-23 Permit broad reuse of original project work
    Add the canonical WTFPL version 2 text and replace the README no-license statement with scope guidance for original files and third-party-derived material.
    Constraint: Third-party materials cannot be relicensed by this repository
    Directive: Keep third-party source notices intact when importing or adapting new material
    Tested: Compared license text with official WTFPL source and SPDX identifier; staged diff check
    Not-tested: No product tests needed for licensing-only change
    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
